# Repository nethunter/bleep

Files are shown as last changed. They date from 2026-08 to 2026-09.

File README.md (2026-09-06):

<p align="center">
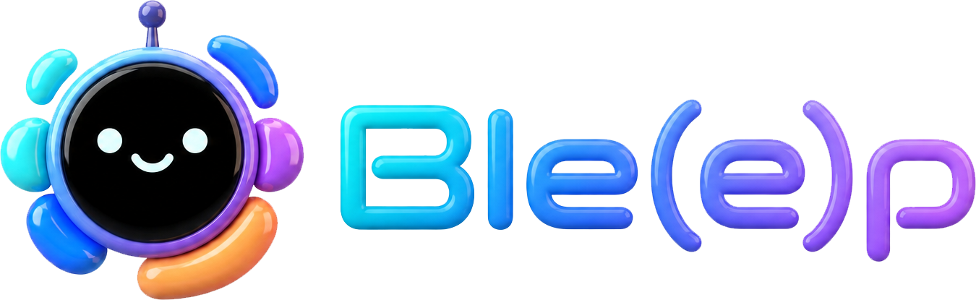
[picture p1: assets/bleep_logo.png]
Ble(e)p
  
</p>

<p align="center">
  Open, community-built control and automation for studio gear.
</p>

<p align="center">
  <a href="https://bleep.hml.tech">Website</a> ·
  <a href="docs/manual/manual.md">Owner's guide</a> ·
  <a href="docs/device-support.md">Device support</a>
</p>

# Ble(e)p

**Bluetooth Links Everything, Eventually, Probably.**

The serious expansion is **Bluetooth Low Energy Equipment Panel**: a compact
description of the hardware and its purpose when the joke needs a straight
face.

Ble(e)p is firmware for a small, touch-first hardware remote that can control
many kinds of studio equipment from one place. It started as a replacement
remote for the iFootage Shark Nano II camera slider. The longer-term goal is
bigger: become the **Home Assistant of remote controls**.

That means a shared platform where the community can add device drivers,
support new controller hardware, combine equipment from different brands, and
build repeatable workflows without waiting for every manufacturer to cooperate
with every other one.

Today Ble(e)p runs on an ESP32-C3 CrowPanel 1.28-inch round display and controls
a small but growing set of motion, camera, and audio devices. It is active
firmware development, not a finished consumer product. Some integrations are
capture-backed experiments, and several roadmap features shown in the UI are
not implemented yet.

## Product website

The [marketing website source](website/README.md) includes an interactive 3D
view of the printable enclosure with independent body/button finish swatches
and a clickable side-button push animation, a lights/camera/audio sequence
illustration, and a brightness preview. It introduces the current DIY project and links to
exact-model compatibility, the owner's guide, and build instructions. See the
website README for local preview and deployment commands. Manufacturer logos
use the site's monochrome palette, and camera compatibility distinguishes
Pixel 9's tested path from experimental iPhone, Galaxy, and other candidates.

## Where it started

Ble(e)p began on the
[Hacking Modern Life YouTube channel](https://www.youtube.com/@hml) as a hands-on
project to turn a small round ESP32 panel into a better remote for the iFootage
Shark Nano II. Once that worked, the obvious question was: why stop at one
remote? That experiment grew into the larger open-source vision described here.

## The idea

Studios accumulate one remote per light, camera, slider, recorder, and app.
Ble(e)p aims to replace that pile with an open controller built around a few
principles:

- **One interface, many brands.** Drivers expose capabilities such as record,
  move, power, or brightness through a common model.
- **Local control.** Device links, state, and sequences run on the controller;
  normal operation does not depend on a cloud service.
- **Useful offline.** The panel boots to Home without starting Bluetooth and
  connects only when a device or sequence needs it.
- **Honest state.** A Bluetooth write or protocol ACK is not presented as proof
  that hardware moved, recorded, or powered down.
- **Community-extensible.** New devices live in isolated drivers with captured
  protocol evidence, host tests, and explicit confidence labels.
- **More than one panel.** The current CrowPanel is the first target, not the
  final form factor. Display, touch, transport, and device boundaries are being
  shaped so other hardware can follow.

## What works now

- A round, touch-first Home and Devices interface with persistent device
  records, enable/disable, rename, forget/re-pair, and delete. A new or
  factory-reset panel starts with an empty Devices list; add Shark or any other
  physical device explicitly through **+ Add device**. The registry holds up
  to 24 saved devices. Connected devices sort to the front while other devices
  retain their saved order. The Devices list remains unpaged through six
  configured devices, then pages six devices at a time. Long screen, device, and sequence
  titles stay on one line and scroll horizontally instead of covering content.
  Common pages and edit overlays share the same Home-aligned title, navigation
  controls, and content start rather than maintaining separate screen geometry.
  Removing a saved device or deleting a sequence always opens a named,
  cancellable confirmation before changing stored configuration.
- A Home-screen Settings cog with radio-free saved-Wi-Fi status and direct
  on-panel setup. **Settings > Wi-Fi** scans only on request, lists visible
  networks, accepts a masked password on the round keyboard, validates
  association/DHCP, and turns Wi-Fi off afterward. Replacing Wi-Fi never
  overwrites the prior credentials unless the connection succeeds; forgetting
  Wi-Fi preserves Home Assistant setup. Retained equipment requires an explicit
  **Disconnect & scan** confirmation. The temporary Portal remains available
  for hidden SSIDs and easier phone text entry. Settings also includes haptic
  enable/disable, a first-position scrollable About/build page (including
  commit date), sanitized runtime diagnostics, and a warned Factory Reset.
- Signed Wi-Fi firmware updates with a Home-first boot. When saved Wi-Fi exists,
  the panel renders Home, waits five seconds, checks the selected channel, and
  returns updater-owned Wi-Fi to `WIFI_OFF`. Foreground work defers or cancels
  the check. Ten-minute idle checks and **Settings > Firmware update** checks
  remain. Checks never download an image; **Install now** hands the exact signed
  request to fixed recovery. The round-safe Firmware page keeps one contextual
  Check/Install action and an explicit two-second-hold Recovery action visible
  without scrolling; its countdown replaces the screen title where the holding
  finger cannot cover it. Available-release and install-confirmation prompts use
  a nearly full-face circular amber frame rather than a rectangular dialog;
  its primary and secondary actions have equal widths. Stable is default and
  development is opt-in. Recovery
  updates only the progress region while downloading, then holds on an explicit
  success screen until **Restart** is pressed. After installation is confirmed,
  main immediately restarts into a circular preparation screen with normal
  services kept dormant, then writes and validates the release's signed recovery
  image. Only the newly updated recovery is selected to install main. A failed
  preparation returns to the Firmware page with **Retry update**. This avoids reserving
  another full application slot; power loss while factory recovery itself is
  being replaced may require the NVS-preserving USB web recovery flow.
- On-demand Bluetooth LE connections through one shared NimBLE host. Central
  camera/light links and the Phone Camera HID peripheral share that runtime. Up to
  four physical BLE transport groups stay connected across navigation and
  remain immediately reusable while healthy. Ordinary devices consume one
  group each; every Aputure Light and Zhiyun member provisioned into the
  same panel-owned mesh shares one group and one proxy connection. An ownerless retained session is parked
  after an unexpected drop instead of reconnecting indefinitely. The controller
  retains up to 16 NimBLE bond records independently of the saved-device limit.
- A battery-conscious runtime policy uses compile-time configurable BLE
  transmit power (+6 dBm by default), bounded
  low-duty scan bursts, calmer ready-link intervals, Home Assistant Wi-Fi modem
  sleep, and ownerless reconnect suppression. The screen and backlight remain
  on continuously.
- On-device sequences with generated reverse/inverse Stop by default, an
  explicit Custom Stop override, waits, persistent storage, concurrent device
  preparation, and a hardware-button
  trigger. A partial Start failure can run Stop for cleanup and then retry
  Start; devices already confirmed stopped do not abort that cleanup. A saved
  camera that keeps accepting and dropping the link fails preparation within
  seconds as `Re-pair <camera>` instead of waiting out the connect budget, and
  Home Assistant's Wi-Fi may start while cameras and recorders are still
  waking when enough memory is free. There is
  no configured sequence-count ceiling; the registry grows until the panel
  cannot safely allocate or persist another sequence.
- Experimental local Home Assistant control for four selected lights, switches,
  input booleans, buttons, scenes, or scripts through a temporary setup Portal
  and one shared on-demand Wi-Fi session. An authenticated event subscription
  is command-ready even when a memory-gated initial state read is deferred; the
  entity remains visibly `UNKNOWN` until Home Assistant confirms its state.
  A successful service response completes sequence delivery even when an
  idempotent command produces no state-change event.
- A responsive LAN Portal for phone or desktop administration of committed
  devices and current Start/Stop sequences. It can rename, enable, disable, or
  remove existing devices and create, duplicate, reorder, and edit sequences;
  physical pairing and runtime control remain on the panel.
- Experimental native `Aputure Light` support with panel-owned PB-GATT
  provisioning, one cross-brand shared Mesh Proxy connection, per-member
  unicast controls, optimistic state, and the common capability-driven light
  screen. Aputure exposes per-member power and `Set look + On`; ordinary power,
  CCT/tint/brightness, and RGB use the selected fixture's unicast address.
  Automatic group polling is disabled because the previously labeled status
  payload is actually a group power-on command. `0xC000` is never written by
  ordinary device controls and is reserved for future explicit group actions.
  Initial Composition Data, AppKey, model, and group configuration advances
  only after authenticated success statuses; the reported vendor model chooses
  MC Pro versus the shared Ace/Pano command model automatically. The MT Pro is
  operator-confirmed working through this control path, but currently shares
  the MC Pro label because its captured composition identity is identical to
  MC Pro's known tuple.
- Experimental `Zhiyun Light` support for multiple MOLUS X100 and X60RGB
  fixtures. Each Add light operation detects the model, provisions a reset
  fixture when needed, persists its mesh-routing selector, and uses confirmed
  proprietary controls through the mesh's retained gateway; X60RGB also
  exposes RGB hue/saturation. Aputure, X100, X60RGB, and Home Assistant lights
  use the same control screen; the old brand-specific light controls are not
  constructed. Unsupported controls are hidden and HA is power-only.
- Separate Camera-family entries for GoPro, Insta360 GPS Remote, Insta360 Mini
  Remote, DJI Osmo, Sony Camera, and Phone Camera. GoPro uses the published
  Open GoPro BLE shutter API; Phone Camera advertises a bonded BLE HID
  volume-key shutter. The two Insta360 choices share one GATT/session runtime
  but retain separate advertising, shutter vectors, and camera-state formats.
  Mini mode uses the captured exact `Insta360 Mini Remote` identity: the X6 did
  not discover either `Ble(e)p Remote` or `Insta360 Bleep Remote` when only the
  complete-name field changed, then discovered the restored exact identity.
  Both include guarded shutdown and ORBIT wake. DJI
  implements the published Osmo controller handshake, shows the camera's
  four-digit verification code during first pairing, and supports start/stop
  plus status subscription. Toggle-only cameras expose an explicit `Shutter Toggle` scene
  action that repeats in generated Stop. Insta360 X6 Mini advertising,
  state-aware Start/Stop, and status are capture-backed; the physical Mini
  Remote's X6 power behavior is operator-confirmed. Ble(e)p's Mini path also
  completes physical X6 shutdown, correct off UI, and wake/reconnect; its
  Start/Stop and status panel checks remain open. Google Pixel 9
  reconnect and shutter behavior is
  operator-confirmed. GoPro MAX2 connection, initial recording state, explicit
  Start/Stop, and camera-confirmed Encoding state are operator-confirmed on the
  panel. Published Sleep plus reconnect-to-wake controls are implemented and
  verified on that MAX2; broader model/platform coverage and the other families remain
  experimental. Sony
  still stops at an explicit protocol-research screen.
- Specialized slider controls for keypoints A-H, joystick positioning,
  speed/hold settings, run direction, looping, and progress.
- A desktop LVGL simulator that renders the real 240x240 UI and captures PNGs
  without a connected board.
- Native tests for protocol parsing, state reducers, device/scene registries,
  command routing, persistence, and shared BLE scheduling.

Groups, existing Sidus mesh import, success-journal rollback, and full
Canon Wi-Fi/CCAPI control are roadmap work. Home Assistant and Aputure Light
are experimental bounded tranches whose hardware gates remain open. See
[project progress](docs/progress.md) for the exact current gates and
[the implementation roadmap](docs/implementation-roadmap.md) for sequencing.

## Device support

| Device | Status | What Ble(e)p can do |
| --- | --- | --- |
| iFootage Shark Nano II | Current | Pair/reconnect, battery, keypoints, manual movement, timing, loop/direction, and run control. |
| Canon EOS R6 Mark II/III via BR-E1 mode | Current | Stateless movie-record trigger through `Canon (Trigger)`. There is no recording-state readback. |
| Canon EOS R6 Mark II/III smartphone mode | Current, bounded scope | Bonded BLE pairing, explicit movie start/stop, and camera-reported recording state through `Canon (Smart)` are verified on both models; automatic wake and explicit power-down are included in the workflow. |
| GoPro MAX2 (Open GoPro BLE) | Supported | Bonded pairing, explicit Start/Stop, confirmed recording state, Sleep, physical wake, and post-boot Ready are operator-confirmed on the panel. Other models and broader coexistence coverage remain open. |
| Phone Camera — Google Pixel 9 | Experimental; verified path | Bonded reconnect and mixed-sequence BLE HID volume-up shutter are operator-confirmed. Other models and multi-phone coverage remain open. |
| Insta360 X3 | Supported | Operation through Ble(e)p's GPS Remote path is operator-approved. Model-specific capture, full reconnect/power coverage, and coexistence remain open. |
| Insta360 X4 | Supported | Operation through Ble(e)p's GPS Remote path is operator-approved. Model-specific capture, full reconnect/power coverage, and coexistence remain open. |
| Insta360 X4 Air | Supported | Operation through Ble(e)p's GPS Remote path is operator-approved. Model-specific capture, full reconnect/power coverage, and coexistence remain open. |
| Insta360 X5 | Supported | Pairing, immediate sequence Start, camera-reported recording state, Start/Stop, shutdown, and physical wake are operator-confirmed. The returning wake connection has a new address-routing fix awaiting confirmation. |
| Insta360 X6 | Experimental candidate; discovery and power verified | Exact-name Mini Remote discovery/connection, shutdown, `CAMERA OFF`, and wake/reconnect are operator-confirmed. Shutter toggle and video state are capture-backed; explicit Start/Stop and status still need a panel run. |
| Insta360 GO 3 | Experimental candidate | GPS Remote compatibility has not been tested on this model. |
| Insta360 GO Ultra | Experimental candidate | The supplied controller manual assigns Mini Remote mode; no model-specific hardware result is recorded. |
| DJI Osmo Action 5 Pro | Current, bounded scope | On-panel first-pair verification, explicit recording start/stop, and camera-originated recording status are operator-confirmed. Reconnect, forget/re-pair, and coexistence remain open. |
| DJI Osmo 360 | Current, bounded scope | On-panel first-pair verification, explicit recording start/stop, and camera-originated recording status are operator-confirmed. Reconnect, forget/re-pair, and coexistence remain open. |
| Sony Camera | Research | Separate catalog entry with recoverable capture-required onboarding; no device record is committed until the peripheral-role protocol is verified. |
| Tascam Portacapture X8 + AK-BT1 | Current, bounded scope | Record start/stop and recorder-confirmed state, including state restoration after reconnect. |
| Home Assistant local entities | Experimental; mixed sequence verified | Four selected `light`, `switch`, `input_boolean`, `button`, `scene`, or `script` entities over local HTTP/WebSocket. Four-link BLE coexistence plus accepted Start/Stop delivery is hardware-verified; full domain/lifecycle coverage remains open. |
| Aputure Light — amaran Ray 60c / Ace 25c; Aputure MC Pro / MT Pro | Supported exact models | Automatically selects one stable candidate, or shows a bounded picker when multiple factory-reset Aputure/amaran fixtures are nearby, before provisioning onto the panel-owned mesh. Per-node power/look routing follows the working Studio Lighter unicast path. MT Pro is currently mislabeled as MC Pro because both report the known `0x03F6:0x1000` vendor tuple and the same composition header IDs. Pano 60c/120c, broader physical selection, multi-fixture isolation, recovery, and soak gates remain open. |
| Zhiyun Light (MOLUS X100 / X60RGB) | Experimental | Uses the same conditional onboarding picker, then adds the selected fixture as a logical member of the one-slot mesh. Ble(e)p persists a per-member proprietary routing selector and multiplexes `0xFEE9` control with the standard Mesh Proxy bearer on one retained gateway. X100 supports power and CCT/brightness; X60RGB adds RGB hue/saturation. |
| Deity PR4 | Later | Transport and protocol research have not started. |

Compatibility claims are deliberately narrow. Read
[device support](docs/device-support.md) for tested models, pairing modes,
limitations, and remaining hardware checks.

## Hardware

The current target is the **ESP32-C3 CrowPanel 1.28-inch round display**:

- 240x240 GC9A01 LCD;
- CST816D touch controller;
- PI4IOE5V6408 I/O expander;
- onboard vibration motor;
- optional external button on GPIO 1, active low.

The board does not include battery-voltage sensing, so the firmware cannot show
the controller's own battery level without a hardware modification. Battery
values shown on the Shark screen come from the slider.

### Controls

- **Touch:** Home, device management, sequences, connection, keypoints,
  positioning, run controls, per-keypoint settings, and explicit Canon/GoPro
  camera power controls. Reopening or preparing a Canon Smart or sleeping
  GoPro that Ble(e)p powered off reconnects and attempts its device-specific
  wake path for up to 30 seconds, then returns to a retryable asleep state. An
  accepted touch click produces a crisp haptic tap; a device becoming ready or
  opening an already-connected device uses two quick ticks; Back uses two
  uneven taps; and a newly surfaced error uses two strong pulses. Scrolling
  and canceled touches do not produce feedback.
- **Button (GPIO 1):** A short press activates the current primary action. On a
  sequence run screen it starts from Ready and stops once armed or while Start
  is running. Device screens similarly dispatch their primary Shark, Canon,
  GoPro, Phone Camera, or Tascam action. A 700 ms hold navigates Back, cancels,
  or closes the current
  overlay. Continuing the same hold to 2 seconds safely unwinds the remaining
  navigation path and returns directly to Home. Recognized short presses use
  the normal tap, while each handled hold stage uses the Back pattern. The
  button has no power behavior; the hardware SPDT switch controls controller
  power.

### Pin assumptions

| Function | GPIO / address |
| --- | --- |
| LCD DC / CS / SCK / MOSI | GPIO 2 / 10 / 6 / 7 |
| I2C SDA / SCL | GPIO 4 / 5 |
| Touch interrupt | GPIO 0 |
| External button | GPIO 1, active low |
| Vibration motor | I/O expander P0 |
| I/O expander | I2C `0x43` |
| CST816D touch | I2C `0x15` |
| BM8563 RTC | I2C `0x51` |

## Build, test, and flash

You need a compatible Python 3 installation and PlatformIO. From the repository
root:

The clean-storage boundary introduced during `0.2.0-dev` remains in 0.3.0: the
firmware does not migrate former Amaran driver IDs, the `amaran_mesh` NVS key,
or pre-current device/scene/mesh schemas. Before flashing over an older
development build, use **Settings > Factory Reset** on the currently installed
firmware. Recovery first verifies latest stable, then clears saved configuration
and installs that stable main image.

```sh
python3 -m venv .venv
./.venv/bin/python -m pip install -r requirements.txt

PLATFORMIO_CORE_DIR="$PWD/.platformio-core" ./.venv/bin/python -m platformio test -e native
PLATFORMIO_CORE_DIR="$PWD/.platformio-core" ./.venv/bin/python -m platformio run -e bleep
PLATFORMIO_CORE_DIR="$PWD/.platformio-core" ./.venv/bin/python -m platformio run -e bleep -t upload
```

The main Montserrat profile compiles every current driver and is the standard
local firmware check. GitHub Actions is the cross-profile testing ground: every
pull request and push to `main` builds the full Montserrat and Roboto profiles,
plus the isolated Shark, Canon Smart, Canon Trigger, Tascam X8, Home Assistant,
  Aputure Light, Zhiyun Light, GoPro, Phone Camera, Insta360, and DJI Osmo
profiles.
Build an isolated profile locally only when diagnosing a profile-specific
failure.

After native tests and all firmware profiles pass on a push to `main`, GitHub
Actions updates the **Latest development firmware** prerelease with a canonical
manifest, ECDSA P-256 signature, full Montserrat and recovery images, independent verification,
and an NVS-preserving USB migration bundle. Its displayed and manifest version
is the configured project version with `-dev` appended. Publishing a normal GitHub Release
performs the stable-channel build and signing job; it does not require a tag
naming convention. Development snapshots have not necessarily passed the
physical hardware release gates.

To render the UI on a desktop, install ImageMagick and run:

```sh
PLATFORMIO_CORE_DIR="$PWD/.platformio-core" ./.venv/bin/python -m platformio run -e ui_sim
.pio/build/ui_sim/program
```

Generated screenshots are written to `sim/screenshots/` and are intentionally
ignored by Git. Partition schema 2 keeps NVS at `0x9000/0x5000`, OTA metadata
at `0xE000/0x2000`, fixed recovery at `0x10000/0x100000`, its journal at
`0x110000/0x10000`, main firmware at `0x120000/0x2D0000`, and coredump in the
final 64 KiB. CI enforces raw ceilings of `0xF0000` for recovery and `0x2C0000`
for main.

Existing single-slot installations require the release's one-time USB
migration bundle before Wi-Fi updates can work. The migration writes the
bootloader, partition table, blank OTA metadata, fixed recovery, blank recovery
journal, and main application; it does not erase or overlap NVS. On the first
boot, recovery validates and automatically selects main without requiring a
**Boot firmware** tap. See
[hardware migration](hardware/README.md#one-time-recovery-firmware-migration).

## Using the current build

The panel always boots to Home. Open **Devices** and choose a device from its
category to go straight into pairing. The device appears in the saved Devices
list only after pairing reaches protocol-ready state; Back or a failed attempt
does not leave an unpaired record behind. Pairing mode matters:

- Shark: make the slider discoverable; Ble(e)p matches service `0xFFF0` or a
  `Nano`/`Shark` advertised name.
- Canon Trigger: use the camera's Bluetooth remote / BR-E1 menu.
- Canon Smart: use **Connect to smartphone → Add a device to connect to**. A
  saved phone registration and a BR-E1 bond are different pairings.
- Tascam X8: install the AK-BT1 and make the recorder available to its remote
  app connection.
- Zhiyun Light: choose **Add light -> Zhiyun**, then add one nearby X100 or
  X60RGB. Factory-reset and previously provisioned fixtures are accepted.
  Ble(e)p matches the product-qualified `PL105_` or `X104_`/`plx104` identity,
  provisions `0x1827` when needed, then rediscovers `0x1828` and opens the
  control service. Repeat Add light for every fixture. A previously provisioned
  fixture can work over a temporary direct link but will not share the panel's
  mesh range. To move it onto the panel-owned mesh without breaking scene
  references, use **Forget** rather than Remove, Bluetooth-reset the fixture,
  reopen its saved entry, and select the factory-reset candidate.

When adding another Canon camera in either mode, Ble(e)p ignores Canon bodies
that are already saved or bonded to it, including cameras advertising from
Bluetooth standby. After pairing, known `EOSR6m2_...` and `EOSR6m3_...`
identities are shown as **Canon EOS R6 Mark II** and **Canon EOS R6 Mark III**.
**Retry** stays locked to the saved body; use **Forget** before deliberately
pairing that entry to a different camera.
For any saved unpaired device, reopening its entry makes the discovered
candidate rows selectable while preserving the existing device and scene
references.

Open **Portal** from Home and join the open temporary `Bleep-Setup-XXXXX`
network by scanning the on-panel QR code or selecting the SSID whose
five-character suffix matches that panel. Browse to the setup address shown on
the panel; phones may open it automatically as a captive sign-on page. The
setup Portal provides **Overview**, **Devices**, **Sequences**, and **Wi-Fi**
without requiring studio Wi-Fi. Devices can be renamed, enabled/disabled, or
removed; removal is blocked while a sequence references the device. Add
physical devices on the panel so their pairing flow stays local.

Home Assistant is the only Portal function that requires studio Wi-Fi. An
initial nearby-network scan completes before the setup AP opens, and **Show
nearby Wi-Fi** performs a fresh non-blocking scan if networks have changed or
the initial scan found none. Choose a result or enter a hidden SSID manually.
After Ble(e)p joins, note the numeric LAN address, let the setup AP close, and rejoin
the normal local Wi-Fi. Open that address while Portal remains active;
`http://bleep.local` is a best-effort convenience. The Home Assistant URL starts
as `http://homeassistant.local:8123`. A saved token is reported only as stored
and is never returned to the browser; choose **Change stored token** to replace
it. Select at most four supported entities.

Sequences can be created, renamed, enabled/disabled, duplicated, and deleted.
On the panel, **Duplicate** in Sequence Settings immediately opens a complete
copy named `Old Name (2)`; the Portal suggests the same copy name and lets you
change it before saving.

**Add Sequence** guides creation through Start actions, generated Stop review,
and Name. Editing Start regenerates the read-only reverse/inverse Stop
preview. **Customize Stop** copies that preview into an independent editable
list; **Use generated Stop** discards the override after confirmation. Custom
lists support action and wait steps, in-place editing, and reordering. On the
panel, orphaned custom
rows remain deletable if their target device
was removed, so an invalid sequence can be repaired one step at a time. The
Portal changes configuration only: it does not connect to
devices or run sequences. Choose **Finish & Exit** in the Portal, or Exit on the
panel, after saving; this stops the server and turns Wi-Fi off. Later Portal
sessions join saved Wi-Fi directly and show their current numeric LAN address;
normal Home boot remains network-free.
In LAN mode, the on-panel QR code changes from the temporary open-network join
to the current numeric Portal URL.

Lights and switches expose explicit On/Off controls. Home Assistant
`input_boolean` entities use one context-sensitive action button: it shows ON
while the helper is off and OFF while it is on. Buttons use Press and HA
scenes/scripts use Activate.

This v1 path uses an open setup AP and sends Portal and HA credentials over
local plaintext HTTP. Open Portal only in a controlled location and use the
LAN handoff only on a trusted studio network; TLS,
Home Assistant Cloud, OAuth, and exposing Ble(e)p-controlled hardware back to
Home Assistant are not implemented.

Open **Scenes** to create ordered Start sequences with generated or Custom Stop.
New sequences open Start first: add steps, select the header arrow to review
Stop, optionally customize it, then use the checkmark and standard Rename keypad
to name and finish the sequence.
A scene reaches `Ready`
only when every target has both a physical link and completed protocol setup.
In Start or Custom Stop, tap an existing step to change its action or settings;
waits open a millisecond duration editor and **Set look + On** steps reopen with
their saved CCT/RGB parameters. New waits default to 200 ms. New looks default
to 5600 K, 50% brightness,
and neutral tint. While that editor is open, settled slider or color-wheel
changes preview the look on the selected light after a short debounce. Preview
uses **Set look + On**, so the fixture turns on to make the result visible.
Step rows place their reorder/delete controls below
the action name, and the scrollable list ends with **Add step**. Back from an
existing step's settings returns directly to that Start/Stop list. The Devices
list similarly places **Add device** after the configured devices.
The panel owns those links while the run screen is open. Circular target chips
show connection readiness and open each device's full controls without dropping
the other sequence links. Opening Settings cancels pending preparation and
releases sequence ownership so Rename and the Start/Stop editors are immediately
usable; it does not interrupt an active Start, armed recording, Stop, or a
partial action failure that still permits Stop cleanup. Back or Done also
releases sequence ownership while ready device sessions remain available for
immediate reuse. Mixed BLE/Home Assistant scenes give cold physical targets and
deferred HA connection separate bounded preparation windows. Switching to a
scene that uses the same HA entity transfers its ownership without an idle gap,
keeping the retained Wi-Fi/WebSocket session protected even while new physical
targets prepare. Old-only targets lose sequence ownership but remain retained
while the four-resource pool has capacity; normal LRU eviction reclaims one
only when a new acquisition actually needs room. A shared physical transport
group is likewise protected when any member remains in the next scene. Device
management offers an explicit Disconnect action.

## How the firmware is organized

| Path | Responsibility |
| --- | --- |
| `src/core/` | Driver metadata, persistent registries, typed commands/results, scene execution, `DeviceManager`, and the shared BLE central. |
| `src/devices/<device>/` | One device integration: protocol, state reducer, transport client, driver adapter, and optional specialized UI. |
| `src/ui.cpp`, `src/scene_ui.cpp`, `src/ui/` | Home, Devices, Scenes, shared pickers/record controls, and navigation. |
| `src/main.cpp` | Display, touch, I/O, power-button handling, and the Arduino main loop. |
| `test/` | PlatformIO native tests for host-testable logic. |
| `sim/` | Desktop LVGL harness and fake runtime. |
| `docs/` | Architecture, decisions, roadmap, device support, protocol research, and current handoff. |

All parsing, state mutation, GATT writes, scene transitions, and LVGL access
happen from Arduino `loop()`. NimBLE callbacks only enqueue bounded raw events
or notification bytes. This ownership rule is central to keeping the UI and
device state deterministic.

Drivers are selected at compile time through the current PlatformIO build
flags. Runtime device records are separate from compiled driver metadata, so a
record can remain dormant when a smaller firmware build omits its driver. A
future Arduino-as-component build is expected to expose these options through
Kconfig without changing driver code.

BLE transmit power is selected at compile time with
`CONFIG_BLE_TX_POWER_DBM`. Its shared configuration default is `+6` dBm;
define the symbol as an integer from `-24` through `20` in a profile's build
flags when a different range/current trade-off is required. NimBLE maps the
request to a radio level supported by the ESP32-C3.

For the complete model, read [architecture](docs/architecture.md),
[architecture decisions](docs/decisions.md), and [scenes](docs/scenes.md).

## Adding support for a device

A useful driver contribution usually includes:

1. a stable driver/model ID and a clear pairing or discovery rule;
2. protocol types and golden vectors that can be tested without hardware;
3. a pure state reducer where the protocol exposes state;
4. a non-blocking client that obeys main-loop ownership;
5. capability and command descriptors used by the common UI and scenes;
6. hardware results that distinguish a link/ACK from observed physical action;
7. documentation with `Research`, `Hypothesis`, and `Blocked` labels where
   evidence is incomplete.

Start with [CONTRIBUTING.md](CONTRIBUTING.md) and the
[device-driver checklist](docs/device-support.md#adding-a-future-driver). For
Android vendor-app research, follow the
[screen-recording and HCI capture workflow](docs/protocols/capture-workflow.md).
Raw wireless captures often contain identifiers from unrelated nearby devices;
do not open a pull request with an unreviewed capture.

## Roadmap

The broad direction is:

- finish the shared multi-device foundation and physical regression gates;
- add capability-safe groups and reusable generic controls;
- prove Bluetooth Mesh, Wi-Fi/HTTP coexistence, and temporary Portal mode;
- add lighting and full camera integrations;
- harden scenes, recovery, configuration import/export, and release profiles;
- separate board support cleanly enough for community-maintained controller
  hardware.

The versioned [roadmap](docs/implementation-roadmap.md) and
[decision log](docs/decisions.md) are the source of truth. They intentionally
move more slowly than feature ideas: hardware verification gates are
requirements, not suggestions.

## Contributing

Device knowledge, protocol research, host tests, UI work, documentation, and
new hardware targets are all welcome. Please read [CONTRIBUTING.md](CONTRIBUTING.md)
before opening a pull request. Use [SECURITY.md](SECURITY.md) for vulnerability
reports, especially anything involving stored pairing material or future
network credentials.

## Safety and trademarks

This firmware can move physical equipment and start or stop real recordings.
Keep people, cables, and equipment clear of motorized hardware. Test protocol
changes at low speed and confirm physical behavior; an ACK alone is not proof
of success.

Ble(e)p is an independent community project and is not affiliated with or
endorsed by iFootage, Canon, GoPro, Insta360, DJI, Sony, Tascam, Amaran, Deity,
Espressif, or Elecrow. Brand
and product names belong to their respective owners.

## License

Ble(e)p is licensed under the [Apache License 2.0](LICENSE), the same license
used by Home Assistant Core. It permits use, modification, and distribution
while preserving attribution and providing an explicit patent grant.

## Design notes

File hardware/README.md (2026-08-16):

# Ble(e)p Hardware

This directory contains the printable enclosure and editable mechanical model
for the Ble(e)p handheld controller. The enclosure is designed around the
Elecrow CrowPanel ESP32 1.28-inch round display and an SS12D00G slide switch.

## Parts

| Part | Specification | Link |
| --- | --- | --- |
| Display and controller | Elecrow CrowPanel ESP32 1.28-inch round display, model DIS12824D; ESP32-C3, 240x240 IPS display, capacitive touch | [Elecrow product page](https://www.elecrow.com/crowpanel-esp32-display-1-28-r-inch-240-240-round-ips-display-capacitive-touch-spi-screen.html) |
| Slide switch | SS12D00G SPDT slide switch with a 5 mm actuator | [Amazon](https://amzn.to/3RRJRAK) |
| Battery | JLJLUP 3.7 V 1100 mAh 1S LiPo with protection board; 25 x 10 x 42 mm, 19 g, 1C discharge rate, JST 1.25 plug; four-pack listing, ASIN B0GR14VMW5 | [Amazon](https://www.amazon.com/dp/B0GR14VMW5) |
| Battery connector | JST SH 1.0 mm 2-pin connector with pigtails; replaces the battery's incompatible plug | [Amazon](https://amzn.to/4hNGGEG) |
| Replacement battery-path diode | 1N5819 Schottky diode, DO-41, nominal 1 A / 40 V; replaces the original CrowPanel D1 | [Amazon](https://amzn.to/45O7ehS) |
| Heat-set inserts | 3x M3 x 6 x 5 mm brass heat-set inserts | [Amazon](https://amzn.to/4yYaTH8) |
| Machine screws | 3x M3 x 8 mm socket-head machine screws | [Amazon](https://amzn.to/3S8nI18) |

The shortened `amzn.to` links in this parts list are affiliate links. Purchases
made through them may earn a commission at no additional cost to you and help
support the
[Hacking Modern Life YouTube channel](https://www.youtube.com/@hml).

## Enclosure files

| File | Purpose |
| --- | --- |
| [Bleep Remote Top.3mf](<Bleep Remote Top.3mf>) / [STL](<Bleep Remote Top.stl>) | Printable top shell |
| [Bleep Remote Bottom.3mf](<Bleep Remote Bottom.3mf>) / [STL](<Bleep Remote Bottom.stl>) | Printable bottom shell |
| [Bleep Remote Button.3mf](<Bleep Remote Button.3mf>) / [STL](<Bleep Remote Button.stl>) | Printable actuator for the CrowPanel's custom button |
| [Bleep Remote.step](<Bleep Remote.step>) | Editable assembly model containing the enclosure, CrowPanel, button, and slide switch |

Use the 3MF files when your slicer supports them. The STL files are provided
for broader compatibility, and the STEP file is the best starting point for
changing the enclosure or adapting it to another component.

## Printing

The original print used a Bambu Lab X1 Carbon with a 0.4 mm nozzle, a SuperTack
plate, and the stock `0.12mm High Quality @BBL X1C` process preset. The top and
bottom shells used Bambu PLA Matte in Ivory White; the button used Bambu PLA
Matte in Black. Each part was placed on its own plate.

Change only these process settings from the preset defaults:

- enable supports;
- select **Normal (Auto)** supports instead of the default **Tree (Auto)**.

All other process and filament settings remain at the defaults supplied by the
selected Bambu presets. Print the button first as a quick fit test before
committing to both shells.

Experimental mechanical models belong in the gitignored
`hardware/.workbench/` directory. Promote a model into this tracked parts list
only after its fit, printability, and assembly behavior feel final.

## Assembly notes

Dry-fit every component before soldering. The CrowPanel fits directly into the
top shell; no adhesive is used. The CrowPanel's custom button is GPIO 1 and
active low; the printed button transfers the case press to that control. In the
current firmware, a short press triggers the current screen's primary action,
including Start/Stop on a sequence run screen. A 700 ms hold navigates Back,
cancels, or closes the current overlay; releasing after a handled hold does not
also trigger the short-press action. The button has no power behavior—the
hardware SPDT switch is the remote's sole power control.

Install the three heat-set inserts into the modeled bosses with a temperature-
controlled soldering iron and a suitable insertion tip. Keep each insert
square to the boss and stop when it is flush; excessive heat or pressure can
deform the shell. Let the plastic cool completely before joining the enclosure
with the three M3 x 8 mm screws. Tighten the screws only until the shells are
secure.

The battery's original plug is not compatible with the CrowPanel battery
socket. Replace it with the linked JST SH 1.0 mm 2-pin pigtail and put the
slide switch in series with one battery lead:

```text
Battery lead A ── switch COM ── selected throw ── connector lead A
Battery lead B ────────────────────────────────── connector lead B
```

Only the switch's common terminal and one throw are used; insulate the unused
throw. Identify the terminals with a multimeter rather than relying on the
switch's physical orientation. Verify continuity in both switch positions, and
verify the finished connector's voltage and polarity against the CrowPanel
markings and documentation before plugging it into the board.

Battery leads remain live while replacing the connector. Cut and splice only
one conductor at a time, insulate each joint before exposing the other lead,
and cover the finished solder joints with heat-shrink tubing. Do not apply the
soldering iron directly to the battery cell or tabs.

After verifying the switched lead, remove the original CrowPanel D1 and install
the external 1N5819 replacement using the procedure below. Route and
strain-relieve the battery, switch, and diode wiring before fitting the board
and closing the enclosure.

Do not charge, use, or enclose a damaged or swollen lithium battery. Prevent
bare switch terminals and battery leads from contacting the PCB or each other.

## Prototype packaging

The five-unit telescoping-box dielines, folded bridge insert, quick-start card,
fit test, and two-up accordion pocket guide live in
[`hardware/packaging/`](packaging/README.md). Print every structural dieline and
the pocket guide at Actual Size and verify its 50 mm calibration bar before
cutting. The pocket guide is a 69 x 130 mm insert for the concealed cable bay;
it is not a substitute for the current full owner's guide.

## Replace the CrowPanel D1 battery path

The [DIS12824D V1.0 schematic](https://www.elecrow.com/download/product/CrowPanel/ESP32-HMI/1.28-DIS12824D/CrowPanel_ESP32_1.28-inch_V1.0_240507.zip)
identifies the CrowPanel's original D1 as a `B5819WT` Schottky diode in a small
SOD-523 package, in series between `VBAT` and the board load. The reference
assembly removes the original D1 and replaces it with the physically larger,
through-hole 1N5819 listed above.

Do not leave both diodes electrically connected in parallel. Do not replace D1
with a wire.
Confirm the diode's markings and supplier datasheet; its real current
and thermal limits depend on the specific manufacturer and installation.

Disconnect both USB and the battery before soldering. Identify the two D1 nets
with a multimeter rather than relying on connector wire colors, especially
after replacing or rewiring the JST SH pigtail:

```text
battery-positive / VBAT side ── unbanded end [ 1N5819 ] banded end ── board-load side
                                 anode                       cathode
```

Installation procedure:

1. With power disconnected, check that the board-load side is not shorted to
   ground. A steady resistance near zero indicates a fault; resolve it before
   fitting the external diode.
2. Confirm which end of the original D1 is connected to actual battery
   positive. Mark that as the `VBAT` side and mark the opposite end as the
   board-load side.
3. Carefully desolder and remove the original D1. Heat each joint only as long
   as needed, lift the component without prying, then clean and inspect both
   pads. Stop if either pad or trace lifts.
4. Connect the 1N5819's **unbanded anode** to the `VBAT` side. The battery
   connector's verified positive solder joint is a stronger alternative to
   loading the tiny former D1 pad mechanically.
5. Connect the 1N5819's **banded cathode** to the board-load side. Use short,
   flexible insulated wire so the large DO-41 body cannot pull the former D1
   pad from the PCB.
6. Confirm that the removed D1 is no longer electrically connected. Insulate
   every exposed conductor with heat-shrink or Kapton tape. Secure the diode
   body with strain relief and keep the assembly clear of the antenna, USB
   connector, enclosure hardware, and other exposed pads.
7. Inspect for solder bridges, then perform the first test from battery only.
   Disconnect immediately if the diode heats rapidly, the board-side voltage
   stays near zero, or the panel behaves abnormally.

A build using this arrangement measured 4.0 V on the battery side and 3.7 V on
the board side while the panel ran from battery. Before closing the enclosure,
exercise representative BLE scanning and connection load while monitoring
diode temperature and voltage drop. Disconnect immediately if the diode heats
rapidly or the voltage becomes unstable. Retain the longer ADR-025
battery-endurance gate.

## Firmware and pin details

### One-time recovery firmware migration

Firmware installed with the earlier single-application partition table cannot
perform a safe Wi-Fi update. Download `bleep-usb-migration.zip` from a trusted
release, verify its release provenance, extract it, connect the panel by USB,
and run:

```sh
cd bleep-usb-migration
./migrate.sh /dev/cu.usbserial-211240
```

Use the actual enumerated port; never guess a different device. The script uses
esptool `write_flash` without `erase_flash`. It writes the bootloader at
`0x0000`, partition table at `0x8000`, blank OTA metadata at `0xE000`, fixed
recovery at `0x10000`, a blank recovery journal at `0x110000`, and main firmware
at `0x120000`. It does not write or erase NVS at `0x9000/0x5000`, so saved panel
configuration is intended to survive. Keep USB power connected through the
first boot. Recovery should automatically validate and select main; no
**Boot firmware** tap is required for a clean migration. Confirm saved
configuration before relying on Wi-Fi updates.

The NVS-preserving bundle has been hash-verified and exercised on five distinct
panels. All five booted main firmware after migration without a manual recovery
selection, and settings remained intact where previously configured. Continue
to back up important configuration, confirm it after migration, and never use a
full-chip erase for this procedure.

Build, flashing, firmware behavior, and the complete CrowPanel pin assumptions
are documented in the [project README](../README.md#hardware).

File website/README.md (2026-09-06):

# Ble(e)p website

The static marketing site for [bleep.hml.tech](https://bleep.hml.tech), hosted
with Firebase Hosting in the `hml-studio` Google Cloud project.

## Preview locally

No install or bundler is required. Serve the directory over HTTP so the 3D
model can load its local modules and geometry:

```sh
python3 -m http.server 8765 --directory website --bind 127.0.0.1
```

For a preview with Firebase routing and headers:

```sh
cd website
firebase serve --only hosting --project hml-studio
```

## Design and interactions

The site presents Ble(e)p as an open-source DIY studio gadget. Warm ivory,
signal orange, olive, and oversized Archivo Black headlines frame a real CAD
model and an interactive studio illustration. There is no checkout or implied
finished-product availability.

- `index.html`: product story, lights/camera/audio sequence illustration,
  brightness preview, model-specific compatibility links, build CTA, and FAQ.
- `styles.css`: shared responsive marketing and compatibility design.
- `script.js`: navigation, finite user-started sequence playback, brightness
  preview, and optional model loading. Reduced motion shows the final sequence
  state immediately; each step remains individually selectable.
- `screen-tour.js`: five automatically cycling firmware-screen chapters
  (Sequences, Lighting, Cameras, Audio, Motion), illustrative tap pulses, and
  state crossfades on a 240×240 canvas texture. Pause and Next are keyboard
  accessible. Reduced motion disables autoplay; Next still selects functions.
  Hidden/offscreen/context-lost views stop the clock, and unchanged frames
  sleep between transitions. Failed tour loading retains the static screen.
- `product-model.js`: Three.js rendering from the actual top/bottom/button STL
  exports and display cover, USB-C socket, and power-switch parts extracted
  from the STEP assembly. Drag, arrow buttons, and keyboard arrows rotate the device; Home or
  Reset restores it. Body finishes (Ivory, Graphite, Sand, Stone, Orange) and
  button colors (Orange, Blue, Black) change independently through labeled
  swatches. Stone uses procedural object-space speckles, preserving alignment
  across the two shell parts. Clicking the model's side button depresses it
  and releases in one short animation; Enter/Space on the canvas provides the
  same push. Dragging rotates the enclosure. No separate Press control is rendered,
  and the push does not change the screen tour. Render work stops offscreen
  and when the tab is hidden.
- `assets/device-poster.svg`: lightweight illustrated fallback for unavailable
  WebGL, failed model assets, disabled JavaScript, or Save-Data.
- `compatibility.html`: existing dated evidence ledger, restyled without
  promoting model support. Detailed repository notes remain authoritative.

The sequence and brightness interactions are marketing illustrations, not
remote hardware controls or firmware UI emulators. Camera and audio start in
order, not with frame synchronization. The model uses the real enclosure
geometry, firmware screenshots, illustrative fasteners, and selectable finish
materials; it is not a promise of a manufactured finish.

## Assets and maintenance

Three.js **0.180.0** is pinned and vendored under `assets/vendor/`; its MIT
license is included. No CDN scripts or runtime package installation are needed.
Archivo Black, Manrope, and DM Mono are self-hosted as Latin WOFF2 subsets
under `assets/fonts/`, with their SIL Open Font Licenses. The site makes no
third-party runtime requests.

The top, bottom, and button STL files under `assets/models/` are byte-for-byte copies of the
matching `hardware/Bleep Remote {Top,Bottom,Button}.stl` files. When the enclosure
changes, refresh these copies together and inspect the assembled model. The
original assembly coordinates must be preserved. The LCD-MIANBAN display cover,
USB-C socket, and SS12D00 power switch are exported from the STEP assembly with
`tools/export_website_components.py` (Python 3.12, `cadquery-ocp==7.8.1.1`,
`vtk==9.3.1`). The display cover fills the 42.1 mm case opening; its rounded
shoulder rises from z=0 to the flat touch face at z=1.9 mm. The animated
32.8 mm display and its annular border replace the cover's solid front cap
at z=1.9 mm, eliminating overlapping triangles beneath the screen. Camera
clipping planes follow the device bounds to preserve mobile depth precision.
The model adds a dark socket mouth and insulating tongue to the
single-material connector CAD part to match the physical reference. Raw user
photos are not included in the repository. `ui-sequence.png` is an
existing firmware UI screenshot used as the static fallback. `assets/screens/`
contains fresh, unchanged captures from the full `ui_sim` traversal in this
checkout. These show simulator states, not physical-device recordings:

| Website frame | Simulator capture |
| --- | --- |
| `sequence-ready.png` | `24_scenes_run_ready.png` |
| `sequence-running.png` | `26_scenes_armed.png` |
| `light-cct.png` | `20e_aputure_light_cct_optimistic.png` |
| `light-rgb.png` | `20f_aputure_light_rgb.png` |
| `camera-ready.png` | `12_canon_ready.png` |
| `camera-recording.png` | `13_canon_recording.png` |
| `audio-ready.png` | `19_tascam_ready.png` |
| `audio-recording.png` | `20_tascam_recording.png` |
| `motion-keypoints.png` | `06_shark_keys.png` |
| `motion-run.png` | `07_shark_run.png` |

Rebuild `ui_sim`, run `.pio/build/ui_sim/program`, and refresh the paired
captures together when the firmware UI changes. Tap pulses are illustrative;
lighting/motion screens show separate controls and do not imply synchronized
motion inside a sequence. Existing photography and the owner's-guide
PDF remain available; a website redesign does not regenerate the manual.

Keep asset URLs versioned when changing JS/CSS: Firebase serves them with a
one-week immutable cache. Increment the HTML script/style URLs and the dynamic
model import together. When updating model dependencies or geometry, version
their import/fetch URLs as well.

## Verification

Inspect desktop and mobile layouts, the compatibility table, navigation,
keyboard rotation/reset, drag rotation, play/pause/replay, step selection,
brightness keyboard input, FAQ, reduced motion, missing-model fallback, and
JavaScript-disabled content. Check against Firebase's configured CSP as well
as the plain static server. The existing repository policy also requires the
full Montserrat `bleep` compile after code changes; no flashing from worktrees
without explicit approval.

## Deploy

```sh
cd website
firebase deploy --only hosting --project hml-studio
```

A local preview or successful build is not a production deployment.

### Equipment logos and phone-family presentation (2026-09-06)

`assets/brands/` contains locally hosted manufacturer artwork, displayed as
CSS alpha masks in the site's ink color. Original letterforms and proportions
are preserved. SVG view boxes are tightened to the artwork; Canon's separate
“Global” header label is omitted. The iFootage PNG is unchanged. Logo use
identifies equipment; it does not imply manufacturer endorsement.

| File | Official source | Preparation |
| --- | --- | --- |
| `canon.svg` | <https://global.canon/01cmn/img/common/logo-sp.svg> | Extracted the five Canon wordmark paths; omitted separate Global text. |
| `amaran.svg` | <https://amarancreators.com/> | Extracted the inline `amaran Logo` SVG from the header. |
| `insta360.svg` | <https://res.insta360.com/static/1a22851807665e5431fd7f77b62a9102/Insta360_Primary%20logo%20-%20Black%26transparent%20-%20Online.pdf> | Converted official vector PDF using Poppler `pdftocairo -svg`; cropped view box to paths. |
| `tascam.svg` | <https://tascam.com/wp-content/themes/tascam/assets/img/logo.svg> | Added/tightened the view box. |
| `ifootage.png` | <https://www.ifootagegear.com/cdn/shop/files/cropped-ifootage-logo_2017_300x_c243c7f7-d24a-4d2c-9e1e-efef87ae692d.png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> | Original transparent PNG. |
| `gopro.svg` | <https://gopro.com/en/us/> | Extracted the inline header-logo SVG. |

Phones appear within the homepage Cameras category and alongside the camera
rows in the compatibility matrix. iPhone, Samsung Galaxy, OnePlus, and
Xiaomi/Redmi are named examples of the **existing
experimental iOS/Android candidates** in `docs/device-support.md`, not newly
supported devices or expanded verification. Pixel 9 retains its observed
reconnect/shutter evidence; other Pixel models remain unverified. Manufacturer
camera-setting links support only the volume-key convention, not Ble(e)p BLE
pairing, reconnect, video behavior, or exact-model compatibility. Support
classifications, firmware, and manual content are unchanged.

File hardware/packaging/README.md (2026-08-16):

# Ble(e)p prototype packaging

This directory contains the editable generator for a five-unit packaging
prototype. The design holds:

- one assembled Ble(e)p controller, nominally 118 x 48 x 21 mm;
- one folded USB-C cable beneath the controller;
- one 140 x 75 mm quick-start card above the controller.

The package is a two-piece telescoping paperboard box with a folded bridge
insert. Its nominal internal size is 155 x 90 x 45 mm. The lid has 2.5 mm of
clearance per side before accounting for material thickness. The visual design
uses warm-white faces, a centered Ble(e)p identity, a restrained `Studio
Controller` label, and cropped cyan, blue, purple, pink, and orange accents at
the lid edges. The structure remains telescoping; it is not a hinged or magnetic
book box.

## Generate the prototype

From the repository root:

```sh
/Users/nethunter/.cache/codex-runtimes/codex-primary-runtime/dependencies/python/bin/python3 \
  hardware/packaging/generate_prototype.py
```

This writes `hardware/packaging/bleep-packaging-prototype.pdf`. The PDF contains:

1. the package concept and dimensions;
2. a full-scale lid dieline;
3. a full-scale base dieline;
4. a full-scale bridge-insert template;
5. quick-start cards;
6. a fit and handling test protocol.

Generate the two-up pocket guide separately:

```sh
/Users/nethunter/.cache/codex-runtimes/codex-primary-runtime/dependencies/python/bin/python3 \
  hardware/packaging/generate_pocket_guide.py
```

This writes `hardware/packaging/bleep-pocket-guide-2up.pdf`, a two-page Tabloid PDF.
Each sheet produces two identical 69 x 130 mm, 12-panel accordion guides. Print
three sheets to make five guides plus one fit/registration spare.

Print the pocket guide double-sided in color on 11 x 17 inch, 32 lb matte text
paper. Use **Actual Size / 100%**, landscape orientation, and **flip on short
edge**. Disable automatic scaling and verify the 50 mm calibration bar before
cutting. The front reads panels 1-6 from left to right. Unfold the strip, turn
it over, and continue panels 7-12 from right to left.

Cut the magenta outer borders, then score at each pair of cyan fold ticks. With
the front side up, fold panel 2 behind cover panel 1 and alternate fold
direction at every remaining crease. The closed cover should face outward. No
glue or staples are required. Keep the guide in the concealed cable bay; do not
place it between the controller and the lid.

The first instruction panel deliberately places a stable firmware update before
device pairing. The recipient should connect USB power, configure trusted Wi-Fi
from the Home cog, choose **Settings > Firmware update > Check now**, install the
available stable release, keep USB power connected throughout preparation and
recovery, and press **Restart** when **Update successful** appears. Hidden Wi-Fi
networks use Portal. Manual Recovery mode is not part of the routine first-use
upgrade path.

Print dieline pages at **100% / Actual Size** with all automatic scaling
disabled. Check the 50 mm calibration bar before cutting. Solid magenta lines
are cuts and dashed cyan lines are scores/folds.

Start with ordinary paper to confirm scale and folding order. Make the next
article from 300-400 gsm cover stock or thin E-flute board. The insert is best
made from 1-1.5 mm E-flute or laminated cover stock. Apply adhesive only to the
orange glue tabs.

The dielines are prototype geometry, not production tooling. A packaging
vendor must compensate for its exact board caliper, crease allowance, print
bleed, grain direction, and cutting equipment before manufacturing samples.

For the five presentation samples, request a bright warm-white SBS board or a
white paper-wrapped rigid-board equivalent, digital CMYK printing, and a matte
anti-scuff finish. Ask for one physical color proof before the complete run;
soft-touch films can shift or yellow an otherwise clean white surface. A vendor
can replace the folded paper insert with white CNC-cut EVA/EPE foam while
retaining the same controller opening and concealed cable-bay arrangement.

## Fit assumptions

The controller pocket starts at 116 x 44 mm, leaving a nominal 1 mm supporting
lip at the enclosure ends and 2 mm along its sides for a 118 x 48 mm enclosure.
Print and cut the insert before ordering foam or production board. Enlarge the
opening in 0.5 mm increments only where the physical enclosure rubs.

The cable bay is 17 mm high. Use a compact cable folded flat rather than a
tightly wound coil. The quick-start card sits above the controller and should
be removed before lifting the device.

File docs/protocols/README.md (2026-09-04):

# Protocol research

The protocol notes here were derived from controlled captures and public
research. The public repository keeps extracted command vectors, annotated
behavior, hashes of the original research material, and confidence labels. It
does not ship raw packet captures.

- [Tascam Portacapture X8](tascam-x8.md)
- [Canon smartphone-mode BLE](canon-smartphone-ble.md)
- [Insta360 GPS Remote](insta360-gps-remote.md) — implemented X3/X4/X4 Air/X5 path
- [Insta360 Mini Remote](insta360-mini-remote.md) — implemented X5/X6 capture-backed path; panel gate open
- [GoPro Open GoPro BLE](gopro-open-gopro.md)
- [Zhiyun MOLUS X100](zhiyun-x100.md)
- [Zhiyun MOLUS X60RGB](zhiyun-x60rgb.md)
- [Android screen-recording + HCI capture workflow](capture-workflow.md)
- [Desktop BLE protocol harnesses](desktop-protocol-harness.md) — active
  central/client and macOS peripheral testing
- [Captive Portal discovery](captive-portal-discovery.md) — SoftAP DNS and
  phone connectivity-probe behavior
- [Signed firmware update protocol](firmware-update.md) — manifest, signature,
  replay, target, payload, boot-validation, and rollback rules

Raw captures were removed before publication because radio traces can contain
stable addresses, nearby device names, phone/camera identifiers, pairing
material, host paths, and unrelated traffic. A small filtered capture can still
leak identifiers in metadata or advertisements.

For contributions:

1. follow the [capture workflow](capture-workflow.md) so app actions, ATT
   traffic, reported state, and physical behavior remain distinguishable;
2. use the [desktop harness workflow](desktop-protocol-harness.md) when active
   protocol validation can safely isolate the protocol from firmware;
3. extract the smallest golden request/response or notification vectors needed
   to reproduce the conclusion;
4. replace device-specific identifiers and omit credential-bearing values;
5. document capture conditions, packet order, and the original capture's
   SHA-256 while keeping the raw material private;
6. keep confirmed behavior separate from `Research`, `Hypothesis`, and
   `Blocked` conclusions;
7. do not attach raw captures or mobile bugreports to public issues or pull
   requests.

Every protocol implementation or research tranche must add or update its note
in this directory at the same time as the code. Record known frame directions,
state transitions, confidence, capture provenance, and unresolved fields; do
not leave the implementation as the only protocol specification.

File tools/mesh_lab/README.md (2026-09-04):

# Bluetooth Mesh lab probes

These host-side research tools exercise a panel-owned Bluetooth Mesh without
changing firmware. They are intentionally separate from the production
runtime and currently consume the JSON state created by the sibling
`studio-lighter` research client.

Keep the state file outside the repository with mode `0600`: it contains the
network key, application key, and node device keys. The tools never print
those keys, but raw proxy traffic can still contain stable mesh metadata.

Install the optional dependencies in a separate environment:

```sh
python3 -m pip install -r tools/mesh_lab/requirements.txt
```

The probe used for the 2026-08-07 MC Pro run supports the individual
configuration operations needed to diagnose provisioning independently:

```sh
PYTHONPATH=/path/to/studio-lighter/src python3 tools/mesh_lab/mesh_probe.py \
  --state /private/path/state.json --address COREBLUETOOTH-IDENTIFIER composition-get

PYTHONPATH=/path/to/studio-lighter/src python3 tools/mesh_lab/mesh_probe.py \
  --state /private/path/state.json --address COREBLUETOOTH-IDENTIFIER appkey-add

PYTHONPATH=/path/to/studio-lighter/src python3 tools/mesh_lab/mesh_probe.py \
  --state /private/path/state.json --address COREBLUETOOTH-IDENTIFIER \
  vendor-bind --company-id 0x03f6 --model-id 0x1000

PYTHONPATH=/path/to/studio-lighter/src python3 tools/mesh_lab/mesh_probe.py \
  --state /private/path/state.json --address COREBLUETOOTH-IDENTIFIER sig-bind

PYTHONPATH=/path/to/studio-lighter/src python3 tools/mesh_lab/mesh_probe.py \
  --state /private/path/state.json --address TARGET-IDENTIFIER \
  --proxy-address GATEWAY-IDENTIFIER onoff-get
```

`--address` selects the logical node and its unicast destination from the state
file. `--proxy-address` independently selects the physical BLE Mesh Proxy. Use
different values to prove that a node is reachable through another fixture's
single proxy connection.

Additional read-only operations are `level-get`, `transition-get`,
`onpowerup-get`, and `lightness-get`. `onoff-on`, `onoff-off`, and
`lightness-set --lightness VALUE` send acknowledged messages with a transaction
ID derived from the durably reserved sequence number. Always restore a fixture
to its intended state after a lab run.

`soak --other-address SECOND --count 20 --interval 1` alternates acknowledged
Generic OnOff Get messages between two logical nodes while retaining one BLE
connection to `--proxy-address`. It reserves every sequence number before the
connection attempt and prints the encrypted notifications for offline decode.

`vendor-power-soak --count 20 --interval 1` repeats the confirmed read-only
group power poll over one retained proxy connection. A healthy two-member mesh
should return two authenticated, independently sourced statuses per request.
It does not change emitter state.

`sig-subscribe` adds the target node's Generic OnOff Server to the mesh state's
group address. After subscribing each member, `group-onoff-get` sends one Get
to that group; each reachable member should return its own sourced status.
`group-onoff-on` and `group-onoff-off` send one acknowledged state change to
the group; use `group-onoff-get` afterward to resolve every member separately.

`vendor-subscribe --company-id ID --model-id ID` subscribes a
composition-verified vendor model to the mesh group. `raw-unicast --access HEX`
and `raw-group --access HEX` are restricted to short, already-understood lab
payloads; do not use them for destructive or unknown opcode fuzzing.

After subscribing each tested vendor model to the panel-owned group,
`vendor-power-get`, `vendor-power-on`, and `vendor-power-off` use the confirmed
Ace 25c/MC Pro group protocol. The Set operations change real emitter power;
`vendor-power-get` returns one authenticated, source-addressed status per
reachable member. These commands deliberately target the mesh group: the same
captured power payload sent to either node's unicast address had no observed
effect. Run a Get after a Set and treat missing members as stale, not Off.

`listen --listen 20 --proxy-address GATEWAY` opens a passive Mesh Proxy
notification window without sending an access message. Use it while operating
fixture-local controls to capture unsolicited model/vendor publications.

`appkey-add` uses segmented lower transport. This is the important difference
from the old research sender, which incorrectly emitted the 20-byte Config
AppKey Add access message as one unsegmented PDU.

Use `decode_notifications.py` with the same private state file and one or more
hex Mesh Proxy notifications to decrypt and label responses. It intentionally
prints decoded opcodes and parameters, but not keys. Known configuration,
Generic OnOff/Level/OnPowerUp/Default Transition Time, and Light Lightness
statuses also receive semantic present/target/transition labels.
The correlated Ace 25c/MC Pro vendor power status is labeled with emitter
power, stored intensity, product profile, and checksum validity.

`zhiyun_probe.py` performs the captured read-only `0xFEE9` initialization and
state sequence against a provisioned X100/X60RGB gateway. It reports only the
resolved model and decoded light values; raw identity payloads are intentionally
not printed. Pass the member's persisted selector. The first Zhiyun member in
the mixed panel-owned test mesh was an X60RGB and used selector `0`:

```sh
python3 tools/mesh_lab/zhiyun_probe.py \
  --address COREBLUETOOTH-IDENTIFIER --selector 0
```

Pass `--power on` or `--power off` only when a deliberate physical state
change is intended. The probe follows the write with an independent readback.
X60RGB also accepts `--hue`, `--saturation`, and `--brightness`; each setter is
followed by an independent readback.

`decode_zhiyun_capture.py` timelines a ZY Vega Android HCI snoop log (from an
`adb bugreport`) for Zhiyun mesh research. It requires `tshark` on `PATH` and
prints one line per event: LE connect/disconnect with the peer address, PB-GATT
provisioning PDUs, Mesh Proxy/Network PDUs (classified but left encrypted), and
the cleartext `0xFEE9` frames decoded into direction, sequence, command, member
selector, and payload. Pass `--video-start HH:MM:SS` (phone local time of the
screen recording's first frame) to print the matching recording offset beside
every event, and `--all-att` to include unrecognized ATT traffic.

```sh
python3 tools/mesh_lab/decode_zhiyun_capture.py /private/path/btsnoop_hci.log \
  --video-start 20:23:24
```

The tool prints raw radio addresses, so keep its output outside the repository
with the rest of the private capture material. The two-fixture capture decoded
with it proved that the vendor routes a second Zhiyun member's control through
the first fixture's retained `0xFEE9` gateway link, each member on its own
stable selector; see `docs/protocols/zhiyun-x100.md`.

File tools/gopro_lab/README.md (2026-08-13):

# GoPro desktop protocol lab

This is the central/client form of the reusable desktop BLE protocol harness.
The Mac scans for a GoPro advertising `0xFEA6`, connects with Bleak, records the
discovered GATT shape and notifications, and tests the smallest Open GoPro
recording flow before any behavior is copied into firmware.

The lab deliberately separates four facts:

1. the host BLE API accepted a write;
2. the camera returned a successful command response;
3. status 10 (`Encoding`) independently reported the requested state; and
4. the operator observed the physical camera start or stop.

A successful command response is not recording-state confirmation. The current
firmware stops at step 2. This lab subscribes to Query Response (`GP-0077`) and
registers status 10 so that a firmware repair can be based on camera-originated
state.

## Environment

The repository's documented PlatformIO virtual environment already includes
Bleak. If a worktree has no `.venv`, use the main checkout's interpreter:

```sh
LAB_PYTHON="/Users/nethunter/dev/bleep/.venv/bin/python"
"$LAB_PYTHON" -m unittest -v tools/gopro_lab/test_protocol.py
```

On first use, macOS may request Bluetooth access for Terminal or Python. Put the
camera in its Open GoPro wireless pairing flow before scanning.

First list only matching advertisements. This is read-only:

```sh
"$LAB_PYTHON" tools/gopro_lab/client.py \
  --scan-only \
  --raw-all \
  --log /private/tmp/gopro-lab-scan.jsonl
```

Use the exact name or macOS CoreBluetooth identifier if multiple cameras are
nearby. A fresh pairing normally needs `--finish-pairing`; omit it when testing
whether an existing bond and protocol initialization work without that command:

```sh
"$LAB_PYTHON" tools/gopro_lab/client.py \
  --device "GoPro 1234" \
  --finish-pairing \
  --raw-all \
  --log /private/tmp/gopro-lab.jsonl
```

For a non-recording diagnostic, add `--status-only`. It connects, subscribes,
polls Hardware Info until ready, registers Encoding status, records the reported
idle/recording value, and exits without sending Set Pairing State or Shutter.

The harness subscribes to every discovered notifiable characteristic, polls
`Get Hardware Info` until the camera reports BLE readiness, and registers for
Encoding status. It tries the original one-byte status operation first and
records a fallback to the dedicated two-byte-ID operation if the camera rejects
it. Interactive commands are `status`, `query`, `register`,
`start`, `stop`, `pairing`, and `quit`. Start and Stop are rejected when the
last camera-originated Encoding status does not make the transition safe.

For a bounded five-second recording test:

```sh
"$LAB_PYTHON" tools/gopro_lab/client.py \
  --device "GoPro 1234" \
  --run-cycle \
  --record-seconds 5 \
  --raw-all \
  --log /private/tmp/gopro-lab-cycle.jsonl
```

Begin the cycle with the camera in video mode and physically idle. The runner
requires reported idle, sends Shutter On, waits for reported encoding, holds for
the bounded duration, sends Shutter Off, and waits for reported idle. It does
not claim physical success; record that observation separately.

Raw advertisements, GATT traffic, Hardware Info, and logs can contain a serial
number, stable BLE identifier, Wi-Fi identity, and model information. Keep logs
under a private directory such as `/private/tmp`, never in the repository. Add
only sanitized golden vectors and conclusions to public tests or protocol docs.

## Firmware comparison points

Compare the live transcript with these current firmware boundaries:

- whether a bonded reconnect needs Set Pairing State again;
- which notifiable characteristics must be subscribed on every connection;
- how many readiness retries precede a successful Hardware Info response;
- the exact short packets for Shutter and Encoding registration;
- whether Query Response reports `0x53` initially and `0x93` on transitions;
- whether camera-side or local-button changes also produce Encoding updates;
- command-response and reported-state timing; and
- disconnect/reconnect behavior after the camera sleeps.

Do not port a conclusion into firmware until the transcript and physical camera
agree. Desktop success does not validate ESP32 memory, NimBLE callback ownership,
multi-link coexistence, or panel UI behavior.

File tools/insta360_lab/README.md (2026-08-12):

# Insta360 Mac protocol lab

This is a private-capture harness for testing the X5 GPS Remote protocol before
moving a behavior into firmware. The Mac acts as the BLE peripheral, hosts
`0xCE80`, logs every camera write to `0xCE81`, and sends state-gated Start,
Stop, and power-off notifications on `0xCE82`.

The reusable design, CoreBluetooth callback lifecycle, validation sequence,
privacy rules, and limits of macOS advertising are documented in
[the desktop protocol harness guide](../../docs/protocols/desktop-protocol-harness.md).
This directory is the concrete X5 reference, not a generic multi-device runner.

macOS CoreBluetooth constructs the actual advertisement. Normal mode defaults
to the captured name `Insta360 GPS Remote` and, like the captured physical
remote, does not request CE80 in the advertisement; CE80 is still present in
GATT. `--advertise-service` enables a comparison probe. The longer firmware
name does not fit when macOS also inserts TX power and the service UUID, so
CoreBluetooth can silently omit it. Wake mode requests the captured Apple
manufacturer `ORBIT` data and `0 dBm` TX power; success from CoreBluetooth is
not proof that the controller emitted the capture-exact primary/scan packets.
On the development Mac, a cold-start nRF capture found no ORBIT frame even
though CoreBluetooth reported success. Use a raw-HCI-capable external adapter
when exact wake advertising matters.

A live X5 test confirmed that the minimal CE80-only GATT profile is sufficient:
the camera subscribed to CE82, sent its initialization and current video-idle
state without a query, accepted Start and Stop, reported recording/idle after
each transition, and disconnected after power-off. The two opaque services on
the captured physical remote are therefore not required for this X5 path.
Mac-native wake remains the one unsupported leg: no reconnect occurred during
a 128-second ORBIT request after shutdown because the requested ORBIT packet
was not present over the air.

Run from this directory with the repository virtual environment:

```sh
/Users/nethunter/dev/bleep/.venv/bin/python -m unittest -v test_protocol.py
/Users/nethunter/dev/bleep/.venv/bin/python remote.py \
  --camera-name "X5 SERIAL" \
  --raw-all \
  --log /private/tmp/insta360-mac-lab.jsonl
```

On first use, macOS may request Bluetooth permission for the terminal or Python
process. Select the advertised remote from the X5, wait for a decoded state,
then enter `start`, `stop`, `off`, or `wake`. Start and Stop are rejected unless
the preceding camera write confirms the safe video state. `status`, `normal`,
and `quit` are also available.

For an automated destructive cycle, begin with the X5 on, in video mode, idle,
with media available:

```sh
/Users/nethunter/dev/bleep/.venv/bin/python remote.py \
  --camera-name "X5 SERIAL" \
  --run-cycle \
  --record-seconds 5 \
  --raw-all \
  --log /private/tmp/insta360-mac-cycle.jsonl
```

The cycle waits for confirmed idle, starts recording, waits for confirmed
recording, records for five seconds, stops, waits for confirmed idle, powers
off, waits for CE82 unsubscribe, requests ORBIT wake advertising for up to 60
seconds, and finishes only after reconnect plus a new camera state. Transport
acceptance is logged separately from reported and physical state.

Raw logs may contain the camera serial and other stable identifiers. Keep them
outside the repository and sanitize any vectors before adding them to protocol
documentation.

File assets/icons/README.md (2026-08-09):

# Home Mode Icon Generation

The PNGs in this directory are the source artwork for the 48x48 Home mode
icons embedded in the firmware. Keep this prompt recipe when adding or
regenerating an icon so the Home grid remains visually consistent.

## Successful generation recipe

The current colorful icons were generated on 2026-08-03 with Nano Banana Pro,
using the model ID `gemini-3-pro-image-preview`, a square image response, and
temperature `0.8`. Model IDs may change; use the current Nano Banana Pro image
model when the recorded preview ID is unavailable.

Start every prompt with this shared style block:

> Fun colorful app icon for a round OLED studio remote home screen. Playful
> glossy sticker / toy-like 3D illustration, saturated cheerful colors, soft
> rounded shapes, delightful and quirky, not corporate. Subject centered on a
> pure black background with NO outer square frame, NO border plate, NO text,
> NO watermark. Square 1:1, generous padding so the glyph reads clearly at 48
> pixels.

Append exactly one concise subject description:

- **Devices:** `Subject: a cute cartoon motorized camera slider with a tiny
  smiling camera riding the rail, cyan and electric blue accents, warm orange
  wheels.`
- **Groups:** `Subject: three cute glowing LED softbox lights clustered as a
  friendly group, lime green, magenta, and gold colors.`
- **Scenes:** `Subject: a playful film clapperboard character mid-clap, sunny
  yellow and hot pink stripes, big friendly energy.`
- **Portal:** `Subject: a whimsical Wi-Fi portal doorway / gateway arch
  shooting playful signal waves, violet and turquoise neon candy colors.`

Device-category icons (Add device / Add scene step grids):

- **Motion:** `Subject: a cute cartoon motorized camera slider with a tiny
  smiling camera riding the rail, cyan and electric blue accents, warm orange
  wheels.`
- **Lights:** `Subject: a cute glowing LED softbox light character with a warm
  friendly face, lime green and gold colors, soft glow.`
- **Cameras:** `Subject: a cute cartoon mirrorless camera with a big friendly
  lens eye and a tiny smiling face, coral red and cyan accents, glossy body.`
- **Recorders:** `Subject: a cute cartoon portable audio recorder with chunky
  knobs and a smiling VU meter face, mint green and gold accents.`
- **Switches:** `Subject: a cute chunky rounded ON/OFF toggle switch with the
  knob visibly switched on and a tiny friendly face, turquoise and electric
  cyan track, sunny yellow knob, and coral accents.`

For a new mode or category, preserve the shared block and append a similarly
concrete subject sentence. Specify recognizable objects, a small palette, and
any important count or arrangement. Generate each icon independently as a 1:1
PNG. Save category icons as `icon_cat_<name>.png`.

## Review checklist

Before accepting generated artwork:

- the subject is recognizable when reduced to 48x48;
- the outer area is pure or near black for clean transparency keying;
- there is no enclosing app-icon frame, border plate, text, or watermark;
- the subject has generous padding and does not touch the image edges;
- colors and glossy, rounded forms match the existing four icons;
- the image is saved as `assets/icons/icon_<mode>.png`.

If a model adds a baked-in frame, repeat `NO outer square frame, NO border
plate` and describe the subject as a standalone glyph. If a result is too
abstract, state the exact object count and arrangement, such as “three
identical lights, one above two.”

## Embed into LVGL

The checked-in sources are 1024x1024 RGBA PNGs with transparent backgrounds.
Regenerate the 48x48 true-color LVGL arrays after changing any source:

```sh
python3 tools/gen_icons.py --size 48
```

`tools/gen_icons.py` keys the near-black background to transparency, crops and
scales the artwork, and writes `src/assets/ui_icons.c` and
`src/assets/ui_icons.h`. Review `sim/screenshots/01_home.png` after running the
UI simulator because fine details that work at 1024x1024 may disappear on the
panel.

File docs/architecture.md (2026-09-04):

# Architecture

## Goal

Ble(e)p is a direct Bluetooth and HTTP studio controller. A project builder
selects device drivers at compile time. The operator then creates, configures,
enables, disables, groups, and controls instances of those compiled drivers at
runtime.

The existing iFootage Shark Nano II behavior remains supported.

## System model

```mermaid
flowchart TB
  PanelUI["Round-panel UI"] --> DeviceManager
  PortalUI["Dedicated-mode HTTP portal"] --> DeviceManager
  SceneRunner --> DeviceManager
  DriverCatalog --> DeviceManager
  Groups --> DeviceManager
  DeviceManager --> SharkDriver
  DeviceManager --> AputureLightDriver
  DeviceManager --> ZhiyunLightDriver
  DeviceManager --> CanonTriggerDriver
  DeviceManager --> CanonSmartDriver
  DeviceManager --> HomeAssistantDriver
  DeviceManager --> FutureRecorderDrivers
  SharkDriver --> BluetoothRuntime
  AputureLightDriver --> BluetoothRuntime
  ZhiyunLightDriver --> BluetoothRuntime
  CanonTriggerDriver --> BluetoothRuntime
  CanonSmartDriver --> BluetoothRuntime
  CanonSmartDriver --> WifiHttpRuntime
  HomeAssistantDriver --> HomeAssistantRuntime
  PortalUI --> HomeAssistantRuntime
  ConfigStore --> DeviceManager
  ConfigStore --> SceneRunner
```

All state mutation, command dispatch, and LVGL access remains serialized
through the Arduino `loop()`. Transport callbacks may only queue bytes or
events.

## Current foundation implementation

ADR-013 advances a bounded subset of this architecture before the transport
feasibility spikes:

- the main profile's `DriverCatalog` contains Shark Nano II, Canon Trigger,
  Canon Smart, Tascam X8, Home Assistant, and one discoverable generic Aputure
  Light entry, and one experimental multi-instance Zhiyun Light entry for
  captured MOLUS profiles;
  smaller profiles compile selected drivers out;
- `DeviceManager` owns a dynamically allocated registry with a fixed persisted
  ceiling, command/result queues, up to eight logical active instances grouped
  onto four physical BLE transport slots, per-owner lifecycle, and persistence;
- schema version 2 stores up to twenty-four device records in the `studio` NVS
  namespace and retains records for unavailable driver IDs. Version 0.3.0 is a
  deliberate current-schema boundary: older device, scene, and mesh encodings
  are rejected rather than migrated. HA credentials/token and panel-owned mesh
  secrets use separate checksummed records;
- a missing registry is initialized empty. Pre-registry Shark storage and the
  former default-placeholder cleanup path have been removed;
- the catalog permits one Shark, up to three Canon Trigger instances, up to
  three Canon Smart instances, and one Tascam X8 within the twenty-four-record
  registry;
- Home and Devices load without initializing NimBLE; the first requested BLE
  device lazily starts one shared central runtime, and the last release shuts
  it down;
- Groups and the remaining generic device-type UI remain unimplemented. The first
  GATT facade tranche (ADR-021) now centralizes scanning, async links, retries,
  address claims, security serialization, bonds, and teardown for all four BLE
  clients. Panel Scenes (ADR-020/037) provide generated or custom Stop
  sequences with concurrent Canon Smart + Tascam links. ADR-023 adds bounded
  Portal provisioning and four local HA entities. ADR-024 adds an experimental
  userspace PB-GATT/Mesh Proxy Aputure Light tranche. Both target hardware gates remain
  open. ADR-028 shares that panel-owned provisioning repository and PB-GATT
  engine with Zhiyun lights, then adds model-profiled direct `0xFEE9` control
  with confirmed readback;
  user-authored native groups remain deferred.

Scene records use a dynamically growing, checked-allocation registry rather
than a configured scene-count ceiling. The current schema v4 stores compact
authored steps, a 32-bit scene count, and generated/custom Stop mode. Older
schemas are intentionally rejected at the 0.3.0 clean-storage boundary. RAM
and available NVS space remain real resource boundaries; failed growth or
persistence rolls the attempted mutation back without changing existing
scenes.

## Compile-time driver catalog

`Kconfig.projbuild` will provide a Linux-kernel-style menu for:

- device families and individual model drivers;
- Bluetooth GATT, Bluetooth Mesh, and Wi-Fi/HTTP transports;
- scenes, dedicated Portal mode, and optional UI modules;
- memory-sensitive limits such as connection and queue counts.

Selected drivers register immutable metadata in `DriverCatalog`:

- stable driver ID, brand, model, and device type;
- required transports;
- discovery, pairing, and configuration schema;
- capabilities, commands, and state fields;
- generic UI module plus optional specialized UI extension.

Disabled drivers must not link protocol code, tasks, buffers, assets, or UI
extensions into the firmware.

Compiled drivers are also dormant in RAM until used. Their global adapter is a
small shell containing only pointers/counters; clients, protocol sessions,
transport queues, and shared repositories are allocated on first activation.
Configured-but-inactive devices occupy only registry metadata. Maximum-instance
values constrain configuration and concurrency and must never size eager arrays
of full sessions. Allocation failure is reported through the normal activation
or registry status path without partially activating a driver. The shared BLE
backend follows the same boundary: its implementation state is allocated by the
first BLE activation and released after the last asynchronous client teardown.
When no BLE-backed driver is compiled, its main-loop pump and implementation are
omitted from the linked image.

## Runtime device registry

A device instance is separate from its compiled driver. It stores:

- stable instance ID and display name;
- driver ID and enabled state;
- pairing identity or HTTP endpoint;
- transport preference and fallback;
- model-specific configuration;
- group membership.

Multiple instances may use one driver. If firmware is rebuilt without a
previously used driver, its stored instance remains dormant and can reappear
when that driver is compiled back in.

Runtime disable prevents discovery, connections, polling, commands, and menu
presence. It releases that instance's runtime session but does not recover the
driver's flash code; removing the driver at compile time recovers flash.

## Startup and connection lifecycle

The firmware always boots to a neutral Home menu. Boot does not scan, pair,
re-pair, reconnect to Shark, or load a device control screen.

Home provides:

- Devices;
- Groups;
- Scenes;
- Portal;
- status and power controls.

Opening a device screen acquires a foreground owner for that instance. Opening
a sequence run screen acquires a sequence owner for every materialized
Start/Stop target.
Preparation reaches `Ready` only after
every target is physically connected and its driver reports protocol readiness.
The run screen shows one category-icon chip per target. A chip borrows the
already-held activation to open full device controls, then returns without
tearing down that device or its peers. Once a session reaches protocol readiness,
removing its last owner parks a healthy link in the retained pool. If that
ownerless link later drops unexpectedly, its transport is deactivated instead
of continuing background reconnect; acquiring it again starts the normal
bounded connection path. Attempts that never became ready are canceled.
When a retained instance gains a new owner, `DeviceManager` invokes the
driver's bounded resume hook before attaching that owner. Canon Smart uses this
hook to reconnect and wake a session that the panel previously powered off;
other drivers leave their retained transport unchanged.
Mixed BLE/Home Assistant sequence preparation gives cold physical transports a
60-second ceiling, then starts a fresh 30-second deadline when deferred
Wi-Fi/WebSocket preparation begins. Switching between scenes atomically
transfers sequence ownership for their shared targets. Those targets never
become idle eviction candidates; old-only targets release sequence ownership
but remain retained until ordinary capacity-driven LRU needs room, and a
physical transport group remains protected when any member is shared.
Logical active-instance capacity is separate from physical BLE capacity. Each
driver supplies a `BleSlotKey`: ordinary GATT instances use their instance ID,
non-BLE runtimes use no key, and logical members sharing one real transport use
the same key. A new key at the four-slot limit evicts the least-recently-used
transport group only when every member of that group is idle and unprotected;
the complete group is deactivated so eviction actually frees its one central
link. The logical-instance limit may evict one idle instance independently.
Neither path evicts sequence/foreground owners, pending commands, or confirmed
recording. No device is selected or restored implicitly at boot.

### Shared BLE central

`src/core/ble/` contains a bounded backend-independent coordinator and the
NimBLE backend. Device clients acquire one link handle and retain only their
protocol policy: advertisement matching, candidate choice, GATT discovery,
subscriptions, handshakes, commands, and notification parsing.

One physical scanner fans fixed-size advertisement observations to every
interested link. It runs in four-second bursts separated by 1.5-second pauses,
with a 40/100 scan window/interval while active. Selecting a peer removes only
that subscriber's scan demand;
other preparing devices continue to receive observations except while the
controller is initiating or securing a connection. Discovery pauses for that
bounded procedure and resumes automatically for every remaining requester.
Address claims keep two clients from selecting the same peer. Connects are
asynchronous and use independent slots with a bounded watchdog and
`1500 * min(failures, 4)` retry
backoff. A saved target receives three direct attempts before rediscovery, which
avoids paying scan latency for the common case where a nearby peripheral needs
one or two radio-wakeup retries. The ESP32-C3 initiates at most one physical connection or security
procedure at a time; queued targets continue sharing discovery, and the next
link can connect while an already-linked driver's protocol initialization runs.
This avoids observed HCI `0x3e` establishment timeouts without serializing the
entire preparation pipeline. Canon security procedures are also serialized
because NimBLE security configuration is controller-global.

The central tracks physical connection separately from protocol readiness and
clears readiness on retry, failure, release, and reconnect. Drivers publish
readiness only after their final required subscription, identity/session write,
handshake, and initial refresh has succeeded. Connection setup is scheduled on
the next main-loop pass so queued link events can drain first. Drivers request
targeted service/characteristic/descriptor discovery rather than full attribute
walks. The backend also makes best-effort connection-parameter requests: 7.5–15
ms during setup and 30–50 ms after protocol readiness; rejection is diagnostic
and non-fatal.

The NimBLE controller is initialized with the compile-time
`CONFIG_BLE_TX_POWER_DBM` setting. The shared configuration defaults to +6 dBm
rather than leaving the value implicit; builds may select another value from -24
through 20 dBm when their range/current trade-off requires it. NimBLE maps the
request to a radio-supported level. These radio policies reduce average and
peak demand but are not electrical protection for the CrowPanel battery-input
path.

Serial-only `ble_timing` records cover activation, scan/direct connect, link,
security, GATT setup, protocol readiness, retries, teardown, and total sequence
preparation. A shared asynchronous GATT executor remains conditional: implement
it only if ten-cycle hardware measurements show blocking GATT work consumes at
least 25% of median readiness time for any driver or the concurrent Canon Smart
+ Tascam pair. Until that gate is met, UUID selection and GATT sequencing remain
driver-owned under ADR-021.

NimBLE host callbacks only enqueue fixed-size scan/link/security events.
`loopBleRuntime(now)` drains them before `DeviceManager::loop()`, so matching,
state mutation, GATT setup/writes, and all LVGL access remain on the main loop.
The first acquired link initializes `Ble(e)p` with MTU 247; releasing the last
link begins client deletion and deinitializes NimBLE only after asynchronous
client teardown has actually emptied NimBLE's global slots. An immediate
reacquire can reserve links during that interval; the backend provisions their
replacement clients as capacity returns. Backend callback objects have backend
lifetime rather than link lifetime, and final GAP events are accepted only when
their client pointer still owns the logical slot. Control events also carry the
slot generation that queued them, so an event already waiting when LRU eviction
reuses a logical handle is discarded instead of being delivered to the
replacement device.

Peripheral-role profiles share that same lazy NimBLE host rather than starting
a second controller. Phone Camera and Insta360 use a shared server-callback
dispatcher so the singleton NimBLE server never has competing callback owners.
The first active peripheral-camera driver registers every compiled camera
peripheral service before accepting a connection, because NimBLE cannot safely
extend its GATT table around retained peers. A shared advertiser gives each
disconnected peripheral family or bonded phone a bounded reconnect window;
connected sessions remain simultaneous and advertising continues for the next
offline target. Phone Camera keeps the host alive through a private radio lease
and routes each authenticated inbound connection by bonded identity. Insta360
scans camera advertisements for peer classification and exposes separate GPS
Remote and Mini Remote catalog drivers over one lazy runtime. The selected
profile controls the captured advertising identity, scan response, and shutter
vector while both profiles host the shared proprietary `0xCE80` and HID GATT
table. When disconnected instances require both identities, the shared
advertiser alternates bounded windows; an inbound camera connection is routed
to the saved or provisional instance for the identity it selected. The
inbound connection still has its own `BleSlotKey`, so it counts against the
same four-link budget as outbound central connections. Server callbacks enqueue
only bounded connection/authentication events; security requests, HID/shutter
reports, state changes, persistence updates, and teardown run from the main loop. Sony
remote emulation will use this peripheral-role boundary only after hardware
validation of its public reverse-engineered protocol.

## Capabilities and unified UI

Shared device-type UI modules consume capabilities rather than brand-specific
state:

- `light`: power, brightness, CCT, tint, HSI;
- `camera`: record start/stop, recording state, and later camera controls;
- `motion`: run, stop, progress, keypoints, and manual movement;
- `recorder`: record start/stop, recording state, battery, and media status.
- `switch`: explicit on/off with confirmed state;
- `action`: explicit Press or Activate with no inferred toggle/value action;
- `input_boolean`: explicit On/Off commands with one context-sensitive entity
  button that sends the opposite of the last confirmed state.

Light drivers additionally publish a normalized `LightControlState` containing
supported modes and limits, current or optimistic values, power, pending/error
state, and confirmation quality. A single round-panel shell consumes that
state for Aputure Light, Zhiyun Light, and Home Assistant light instances and
hides unsupported rows without changing navigation or command debounce. The
brand modules retain onboarding only; they do not construct dormant legacy
control screens behind the shared shell. Home Assistant constructs its generic
entity screen only for non-light domains.

Home Assistant is the first dynamic-profile driver: each persistent instance
derives its device type and capabilities from its stored entity domain rather
than the driver's catalog row. Device pickers, scene validation, and command
selection query this instance profile. Four HA instances share one retained
network runtime and do not consume the four physical BLE link slots.

### Home Assistant Portal and runtime

Portal suspends scenes and physical links. If studio Wi-Fi is not configured or
cannot be joined, it performs a bounded asynchronous station scan before
starting a temporary open SoftAP. The SoftAP-bound administration console offers
the initial cached results, a fresh non-blocking scan on request, manual
SSID/password entry, and all local device and sequence configuration. HTTP and
DNS servicing continue while an AP-mode refresh scan is pending. The panel's QR
code identifies the open setup network.
While the AP is active, wildcard DNS sends probe hosts to the panel. Known
Apple, Android, and Windows connectivity-check paths, plus other unknown GET
paths, receive the non-empty Portal page directly with status 200 so phones can
recognize the network as captive and present the setup page as a sign-on screen.
The join is a main-loop state machine, leaving HTTP and LVGL responsive while the
browser and panel report scanning, connecting, success, timeout, missing SSID,
or rejected credentials. A successful join saves those credentials, exposes
the assigned numeric LAN address during a bounded handoff, destroys the AP,
binds a new listener to the station address, and advertises a best-effort
`http://bleep.local` mDNS alias. The same responsive console serves overview,
committed-device administration, and current authored Start/Stop sequence
editing on either AP or LAN. HA setup, discovery, and testing are enabled only
after station handoff. Physical pairing, device commands, and sequence execution are
deliberately absent. Discovery incrementally parses `/api/states`; the browser
receives at most 24 bounded summaries and may select four. The default URL is
`http://homeassistant.local:8123`. Secrets are password fields and never appear
in `/api/config`; it returns only whether a token is already stored, and a blank
submission preserves that stored value. Exit or ten minutes of inactivity
stops HTTP/mDNS, disconnects STA, and returns Wi-Fi to off.

Opening an HA screen or preparing an HA scene target allocates and acquires the
shared `HomeAssistantRuntime`. It joins Wi-Fi, authenticates `/api/websocket`, fetches
each active entity's initial state through REST, and installs a
`subscribe_trigger` state subscription containing only active entity IDs.
Once that authenticated subscription succeeds, the transport is command-ready;
if the memory-gated initial REST read is still deferred, the configured entity
is exposed as available with unknown state until REST or a subscribed event
confirms it. This keeps state reporting honest without blocking mixed-radio
sequence preparation on an optional readback.
Callbacks copy at most two 2048-byte frames; the main loop parses them with
ArduinoJson, mutates state, sends service calls, and updates LVGL. Malformed,
oversized, or dropped frames mark state unknown and schedule a bounded REST
refresh. A successful service result completes action delivery because an
idempotent call may not emit a state-change event. Subscribed events and
heap-gated REST reconciliation update state independently, so API acceptance
does not promote unknown state to confirmed. Only HTTP 404 means missing, while
transport and parse failures remain unknown. The runtime disconnects
Wi-Fi after its final HA instance is evicted or explicitly unlinked. Merely
saving HA entities or credentials does not allocate the client or start Wi-Fi;
outside Portal, active HA ownership, and a bounded updater check the radio is
explicitly `WIFI_OFF`.

Mixed sequences initialize every physical transport before acquiring any Home
Assistant target, independent of authored action order, unless the platform's
early-network policy reports that the BLE runtime is already up with enough
heap; then Home Assistant's Wi-Fi starts while the peripherals are still waking. On the ESP32-C3,
NimBLE initialization requires a contiguous allocation of roughly `0x7800`
bytes; starting Wi-Fi first can fragment/deplete the heap and causes the
underlying BLE library to assert instead of returning a recoverable error.
Scene handoff does not proactively tear down either HA or physical retained
sessions. Old-only targets become ownerless but stay connected while the
four-resource pool has capacity. Acquiring a fifth logical resource or BLE key
uses the normal LRU paths, which skip every shared target because it retains
sequence ownership. This keeps HA, Canon, Tascam, and Aputure Light connected together
when they exactly fill the pool. Action execution still follows the authored
order after all targets prepare. The LVGL pool is held to 64 KiB
and the target keeps two 15-row DMA display strips, returning 47.2 KiB of
static SRAM compared with the earlier 96 KiB/40-row configuration. The full
simulator flow is the regression gate for the LVGL allocation budget. HA keeps
two 2 KiB WebSocket frame slots; oversized state events intentionally become
unknown and use the individual REST recovery path. A WebSocket disconnect is
reported to the main loop as a flag, where authentication and subscription
state are cleared and a bounded reconnect is scheduled.
Transient failures while resolving an entity's initial REST state leave the
entity command-ready but unknown: one entity is retried at a time after a
bounded delay. HTTP 404 remains a terminal missing-entity result; transport,
other HTTP, and malformed JSON results remain unknown and retry.

Drivers publish limits and availability. For example, a CCT-only light does
not expose HSI controls. Specialized workflows such as Shark keypoints may
extend the common motion UI without leaking into other drivers.

### UI allocation optimization

Home and the Devices shell remain resident. Device rows, device screens,
management overlays, and keyboards are created on entry and deleted after
navigation leaves them.
Device and transport state remains owned outside LVGL so destroying a view
never discards protocol state.

Canon (Smart) and Tascam share `src/ui/recorder_shell.*`, driven by a small
view model and typed command callbacks. The shared shell provides connection,
recording, transition, confirmation, and failure states; driver adapters add
optional controls such as Canon's explicit power button or dual Start/Stop
controls for unknown state. Shark retains specialized keypoint and motion
views, and creates only the connect screen plus connected screens/overlays
while active.

Devices **Add device** and Scenes **+ Step** share `src/ui/picker_shell.*`: a
category icon grid, then a driver or enabled-device list, then (for scene
steps) Record Start / Stop. The overlay is created on open and deleted on
close.

The sequence run screen reuses the same category icons in circular target
chips. Their borders breathe cyan during connection/protocol setup, stay green
when protocol-ready, turn red after a terminal connection failure, and remain
muted gray when simply disconnected or powered off. Chip navigation is disabled
while Start or Stop steps execute; a compact status label remains above
Cancel/Done.

The CrowPanel vibration motor is driven by PI4IOE5V6408 expander output P0. A
shared main-loop sequencer provides four semantic patterns: Press is one 20 ms
tap; Connected is 12 ms on, 24 ms off, then 12 ms on; Back is 15 ms on, 35 ms
off, then 30 ms on; Error is 60 ms on, 45 ms off, then 60 ms on. LVGL's input
feedback callback requests Press only after a click is accepted, and navigation
handlers replace that generic pulse with Back. Connected fires when the current
device becomes protocol-ready, when an already-ready retained device is opened,
or when sequence preparation reaches `ScenePhase::Ready`; it queues behind a
stronger active pattern. Foreground command failures, pending-add save failures,
sequence failures, and terminal Portal errors request Error only on their
transition into failure.
Stronger patterns take priority, and no pattern delays UI, transport, or scene
work.

The Devices screen remains unpaged through six records. Pagination controls
appear only at seven or more records, with six records per page. Device rows
are released before a specialized control screen or rename overlay is
allocated. The full capture run still includes the largest specialized control
and sequence-stop screens. Target heap recovery remains part of ADR-023's open
hardware gate.

State fields carry a quality:

- `unknown`: no usable value;
- `optimistic`: inferred from a command without readback;
- `confirmed`: observed from the device.

## Groups

Groups are named collections of runtime instances. A group exposes only the
capabilities common to all enabled members. Commands fan out and retain a
result for every member.

Groups are valid scene targets. An incompatible or unavailable group action is
rejected during scene validation.

## Bluetooth architecture

GATT is accessed through a transport facade:

- all current BLE builds use one lazy NimBLE central;
- Shark, Canon, and Tascam use their device-specific GATT services;
- Aputure Light and Zhiyun lights share one panel-owned mesh repository, durable unicast
  allocator, and userspace no-OOB PB-GATT provisioner over that central;
- the mesh runtime owns one retained proxy client. A dynamically allocated
  `ProxyTransport` reference-counts logical users and prefers a saved Zhiyun
  node whenever the active set requires the additional `0xFEE9` service. It
  exposes standard Mesh
  Proxy Data In/Out to Aputure Light access messages and lets saved Zhiyun
  sessions attach their separate `0xFEE9` characteristics to that same native
  client;
- `DeviceManager` charges the complete panel-owned Aputure Light/Zhiyun mesh one
  `BleSlotKey`, so adding or retaining another member does not consume another
  one of the four physical slots;
- the generic, multi-instance Zhiyun driver accepts reset or provisioned
  product-qualified `pl105` X100 and `plx104` X60RGB advertisements. It uses
  PB-GATT when provisioning is required, rediscovers the Mesh Proxy advertiser,
  then initializes and controls the separate `0xFEE9` GATT service. Its writes
  remain pending until correlated device replies confirm the requested values.
  Saved members persist a routing selector and share one gateway notification
  stream; unique transport sequences keep concurrent replies attributable;
- PB-GATT onboarding is a temporary exclusive link. After a saved node is
  reopened, steady-state control attaches to the shared proxy bearer rather
  than allocating another central slot;
- callbacks enqueue only bounded events or raw bytes; mesh crypto, parsing,
  persistence, and writes remain on the main loop.

Concurrent Aputure Light proxy, Shark/Canon/Tascam GATT, provisioning recovery, and
post-teardown heap remain an ESP32-C3 hardware feasibility gate.

## Dedicated Portal mode

The administration server does not run during normal operation.

Entering Portal mode:

1. refuses entry or requests confirmation if a scene is active;
2. suspends device connections;
3. joins saved studio Wi-Fi, or scans before starting a temporary open SoftAP
   whose administration console supports local device/sequence changes and
   optional Wi-Fi credentials, with an on-panel Wi-Fi QR code and AP-scoped
   captive-portal discovery;
4. after joining, shows the numeric station address, closes the AP, and binds
   the bounded HTTP server there with `bleep.local` as best-effort discovery,
   and changes the QR code to the numeric Portal URL;
5. displays the active network, URL, timeout, and Exit on the panel.

Both listeners expose bounded JSON APIs for summary, device records, sequences,
and non-secret HA configuration. HA discovery/testing and secret writes require
LAN mode. Each session has a fresh mutation nonce;
state-changing requests without it are rejected, CORS is not enabled, and the
page is served with no-store and frame-denial headers. Device and sequence
changes pass through their normal registries, validation, and checked NVS
writes. Failed persistence restores the prior in-memory state, stale sequence
revisions are rejected, and referenced devices cannot be removed. Records for
drivers omitted from the current build remain visible but unavailable.

Exiting Portal mode, reaching the inactivity timeout, or rebooting destroys the
HTTP server, mDNS responder, SoftAP, and station connection before restoring
normal operation. Teardown tests must verify that no listener, AP, server task,
or portal buffer remains active.

Canon CCAPI is unavailable in Portal mode because normal station-mode control
is intentionally suspended. The portal is exposed on the trusted studio LAN
only for the lifetime of the active Portal screen.

## Local settings and support information

Home adds a cog without replacing Devices, Groups, Scenes, or Portal. Settings
and its Wi-Fi, About, System Info, and Factory Reset views are created on entry
and destroyed on exit. The Wi-Fi view reads the saved SSID and labels the
normal state as radio-off without starting the radio. An explicit scan
allocates a bounded main-loop Wi-Fi configuration service, lists at most 16
visible deduplicated SSIDs by signal strength, and associates only after the
operator selects a network and enters any required password. A non-zero DHCP
address is the success boundary; internet access is not required. The service
saves only a successful replacement and returns Wi-Fi to off after success,
failure, timeout, or cancellation. Retained equipment requires a separate
**Disconnect & scan** confirmation, while an active command blocks scanning.
The Portal remains available from this page for hidden SSIDs, phone-based text
entry, and Home Assistant configuration. **Forget network** clears only Wi-Fi
credentials and preserves Home Assistant URL, token, and entity records.

About is the first Settings item. The menu and About body scroll independently
within round-safe page regions, while Factory Reset remains a distinct top-level
menu item. Destructive styling appears only after it opens the separate warning
and hold-confirmation view.

Haptic enablement is a separate checked NVS record and gates the shared
non-blocking sequencer without changing its semantic patterns. About embeds a
small LVGL logo and build identity. System Info samples heap, largest
allocation, minimum heap, physical BLE groups, and Wi-Fi mode on the main loop
without exposing secrets or stable device identifiers.

Factory Reset is deliberately stronger than clearing an individual registry.
After a three-second hold it cancels work, deactivates transports, journals a
reset request, and boots fixed recovery. Recovery first downloads and verifies
the latest signed stable main image. Only after that succeeds does it erase the
complete NVS partition, including BLE bonds and mesh identity, select main, and
reboot. Failed networking or verification leaves NVS untouched.

## Signed firmware updates

`FirmwareUpdateService` is a bounded main-loop state machine covering startup
pending/checking, scheduled, foreground-deferred, connection, manifest check,
availability, failure, and recovery handoff. Home and stores are rendered
before its clock starts. On each boot with saved Wi-Fi it checks the selected
channel after five seconds of eligible idle Home. Foreground activity defers a
not-yet-started check or cancels an in-progress HTTP request without releasing
equipment. Ten-minute idle eligibility, 24-hour success cadence, 1/6/24-hour
network backoff, and Settings-triggered checks remain available afterward.

The updater fetches only the bounded signed manifest and detached signature.
It is a temporary network owner and returns its station to `WIFI_OFF` on every
terminal or cancellation path. Teardown disconnects first and stops the radio
only after a bounded main-loop settling interval, so ESP-IDF's tcpip task cannot
race driver deinitialization while sending DHCP release. Recovery handoff lets
the imminent reset stop Wi-Fi. Confirmed installation persists the exact
signed request and releases retained links with consent. Main first verifies
and selects its own `ota_0`, then restarts immediately without painting an
intermediate progress overlay. That boot initializes only the display, touch,
LVGL, and a circular update-progress view; device runtimes, scenes,
Portal, Home, and normal services remain dormant. It downloads, writes, and
validates the signed recovery payload in the factory partition, selecting
recovery only after verification succeeds. A failed attempt falls through to
the normal main UI with a retry action. A newly installed main that remains
pending its ten-second health gate skips this early path. The newly updated
recovery verifies the same request again and streams main into `ota_0`; no
second full firmware image is retained. See
[the signed update protocol](protocols/firmware-update.md) for manifest trust,
stream validation, replay rejection, journal recovery, and partition geometry.
The bounded encoded journal records use checked `nothrow` heap storage during
load/save; they are never multiplied on the Arduino loop-task stack.
If power is lost before the recovery write begins, the intact journal makes the
next valid main boot resume it before normal services. Once the factory
partition has been erased, loss of power can leave
recovery unbootable; main remains selected when possible, but a later main
failure then requires the NVS-preserving USB web recovery flow. Main and
recovery release sequences are tracked independently. After main passes its
health gate, it clears the completed install journal; Factory Reset retains its
post-main recovery-refresh compatibility path.
Manual Recovery mode uses a two-second hold and persists a distinct request so
fixed recovery remains on its menu until the operator explicitly boots main or
chooses another action.
Recovery ignores all touch during a 1.5-second boot guard, then requires 300 ms
of continuous release before arming menu input. This prevents touch-controller
startup from being mistaken for release while the initiating finger is still
held over a menu row. A blank migration journal plus a valid main image causes
an automatic one-time handoff to `ota_0`; corrupt or unreadable journal state,
an explicit Recovery Mode request, or invalid main keeps the recovery menu and
its **Boot firmware** action available.
During a main-image download, recovery paints the static install view once and
updates only the progress bar and percentage region. After the image and hash
verify and `ota_0` is selected, recovery remains on an explicit success screen;
it reboots only after the operator presses **Restart**.

## Persistence

Versioned persistent records cover:

- Wi-Fi credentials and Canon endpoints;
- runtime device instances and groups;
- panel-owned mesh identity and keys;
- scenes and execution metadata;
- schema version and compatibility status;
- panel preferences such as haptic enablement.
- firmware channel plus installed, available, and dismissed release sequences.

Secrets are masked in UI and logs. Backups exclude keys and credentials unless
the operator explicitly requests a protected full export.

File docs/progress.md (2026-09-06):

# Project Progress

Update this file at the end of every implementation session. Keep entries
short, factual, and reproducible.

## Current status

### 2026-09-06: Finish swatches and illustrated action-button push

- Added independent body swatches (Ivory, Graphite, Sand, Stone, Orange) and
  button swatches (Orange, Blue, Black), based on the operator's finish photo.
  Body colors affect both shell parts; the button material remains independent.
  Stone uses procedural speckles in assembly coordinates. Swatches show the
  selected name and pressed state, with compact desktop and mobile layouts.
- Clicking the actual top-right CAD button plays one short inward push and
  automatic release. There is no separate Press control or held-button UI, and
  the animation does not change the screen tour. Enter/Space on the focused
  model provides equivalent keyboard access. Nearby ray samples improve the
  small button target while respecting enclosure occlusion. Dragging continues
  to rotate the model. Reduced motion uses an immediate pressed/resting pose.
- Browser checks verify pixel changes for all finishes, independent selection,
  a direct CAD-button click, visible push and return to identical resting pixels,
  keyboard access, rotation, and back occlusion. Screenshots reviewed at desktop
  and phone sizes. Layout checks pass at 320/390/768/1024/1440 px; desktop/mobile
  Axe and JavaScript error capture are clean. Existing screen-tour animation,
  pause, five functions, offscreen behavior, and fallback checks pass.
- Context-loss checks hide controls, preserve chosen finishes on restoration,
  and restore button animation. Missing geometry retains the poster; missing
  optional screen-tour assets retain finish choices and button animation.
  CSS and main/model JavaScript use `20260906-8` URLs. Syntax, artifact, and
  whitespace checks pass. Full Montserrat `bleep` build passed using the shared
  environment: 147,220 bytes RAM, 2,038,518 bytes flash. No firmware behavior
  changed, native tests were not needed, and no hardware was flashed.
- Rebased onto current `origin/main`, merged from `main` with `--no-ff` as
  `55835ee`, and pushed. Firebase Hosting released 54 files. Live HTML, CSS,
  and main/model JavaScript match the reviewed bytes. Production checks
  confirm independent Stone/Blue selection, a mouse click on the actual CAD
  button followed by automatic release, no separate Press control, mobile
  layout fit, and no JavaScript/CSP errors. Live mobile screenshot reviewed;
  artifact check passes (441 tracked files).

### 2026-09-06: Present phones as cameras

- On operator correction, folded iPhone, Galaxy, Pixel, OnePlus, and Xiaomi/Redmi
  into the homepage Cameras category. Removed the separate Phones category and
  compatibility section; phone candidates now appear next to the existing Pixel
  camera entry in the standard matrix. Preserved evidence labels and camera
  setup sources. The old `#phones` anchor now targets that matrix row.
- Removed unused phone-section CSS and advanced shared CSS URLs to
  `20260906-7`. Homepage has exactly Cameras, Lighting, Audio, and Motion.
  Browser checks pass at 320/390/768/1440 px, with no JavaScript errors or
  mobile compatibility Axe violations. Visually reviewed the camera category.
  Artifact and whitespace checks pass. Full Montserrat `bleep` build passed
  using the shared environment: 147,220 bytes RAM, 2,038,518 bytes flash.
  No firmware behavior or support status changed; no native tests or flash.
- Rebased onto current `origin/main`, merged with `--no-ff` as `9da0646`,
  and pushed. Firebase Hosting released 54 files successfully. Live browser
  checks confirm four equipment categories, phones within Cameras, the matrix
  row in place of the removed section, mobile fit, and no JavaScript errors
  or mobile Axe violations at `https://bleep.hml.tech`.

### 2026-09-06: Authentic equipment logos and visible phone families

- Replaced the six typeset equipment names with manufacturer artwork for Canon,
  amaran, Insta360, Tascam, iFootage, and GoPro. Assets are self-hosted and
  rendered as ink-colored CSS masks with their original proportions. Official
  source URLs and extraction details are recorded in `website/README.md`.
  SVGs contain local vector paths only; no embedded scripts or remote assets.
- Added a homepage Phones row linking to a dedicated compatibility section for
  iPhone, Samsung Galaxy, Google Pixel, OnePlus, and Xiaomi/Redmi. Manufacturer
  camera-setting sources explain the volume-key convention. These are named
  examples of the existing experimental iOS/Android candidates, not additions
  to the Supported list: Pixel 9 retains its verified reconnect/shutter evidence,
  while other families and other Pixel models remain unverified. No firmware,
  support classification, or manual changes are made by this website tranche.
- Desktop/mobile screenshots reviewed. Checks pass at 320, 390, 768, 1024,
  and 1440 px; fixed a discovered 768 px logo-strip overflow. All six logos,
  five phone-family cards, and the homepage-to-phone-section link are present.
  Homepage and compatibility desktop/mobile Axe checks report no violations;
  browser JavaScript error capture is clean. Shared CSS URLs use `20260906-6`.
  Repository artifact and whitespace checks pass. Full Montserrat `bleep`
  compiled in the shared environment recorded below: 147,220 bytes RAM and
  2,038,518 bytes flash. Native tests were not needed for website-only work;
  no hardware was flashed or phone compatibility physically tested.
- Rebased onto current `origin/main` without conflicts, merged from `main`
  with `--no-ff` as `5857f20`, and pushed. Firebase Hosting released 54 files.
  Live HTML, compatibility page, versioned CSS, and all six logos match the
  reviewed bytes. Production browser checks pass at all five widths, including
  the clean-URL phone anchor, five family cards, six logos, and homepage plus
  compatibility desktop/mobile Axe scans. No browser JavaScript/CSP errors;
  live mobile logos visually inspected. Artifact check passes (441 files).

### 2026-09-06: Remove rotating-screen depth artifacts

- The operator's phone screenshot exposed depth fighting between the animated
  display and the cover's solid front cap. Removed the 51 coplanar front-cap
  triangles at load time and replaced them with an adjacent screen and annular
  border at z=1.9 mm. The original CAD asset and rounded shoulder are preserved.
  Camera near/far planes now follow its distance with a 110 mm half-range,
  rather than wasting mobile depth precision on a 0.1 mm near plane. All model
  vertices fit within a 59.414 mm rotation radius. Main/model URLs use
  `20260906-5` for cache invalidation.
- Browser verification at 390 px width and DPR 3 covered 26 rotation steps.
  All 11 sampled front-facing views matched an unobstructed-screen reference
  pixel-for-pixel. Front, angled, and back screenshots were visually inspected;
  the back properly hides the screen. No JavaScript errors. These are desktop
  Chromium mobile-emulation checks; the operator's physical phone was not used.
- Animation, paused pixels, five functions, offscreen pause, reduced motion,
  optional-tour fallback, responsive widths, and desktop/mobile Axe checks
  pass. JavaScript syntax, whitespace, and the repository artifact check pass.
  Full Montserrat `bleep` compiled in the shared environment recorded below:
  147,220 bytes RAM and 2,038,518 bytes flash. No firmware logic changed;
  native tests were not rerun and no hardware was flashed.
- Rebased onto current `origin/main` (no incoming changes), merged from
  `main` with `--no-ff` as `da609b1`, and pushed. Firebase Hosting released
  48 files successfully. Production HTML and versioned renderer match local
  bytes at `https://bleep.hml.tech`; model loading, five functions, mobile
  navigation/width, compatibility, custom 404, and CSP pass without browser
  JavaScript errors. The website correction is deployed; physical-phone
  confirmation remains with the operator.

### 2026-09-06: Fit the website display to its raised cover

- Replaced the undersized, flat 38.2 mm backing with the actual LCD-MIANBAN
  cover exported from `hardware/Bleep Remote.step`. Its 42.1 mm diameter
  matches the shell opening, and its rounded shoulder rises 1.9 mm above the
  case, matching the operator's side photo. Moved the animated display to
  z=1.92 mm above that face. The export script now reproduces this component.
  Main/model JavaScript URLs use `20260906-4` to bypass immutable caches.
- Visually inspected angled, side, and mobile views. Browser checks pass for
  changing screen pixels, paused-frame stability, all five functions,
  offscreen pause/resume, reduced motion, optional-tour failure fallback,
  and widths 320/360/390/768/1440. Desktop/mobile Axe checks and JavaScript
  error capture are clean. JavaScript syntax and repository artifact checks
  pass. No firmware logic changed; native tests were not rerun.
- Full Montserrat `bleep` compiled using the shared main-checkout Python
  environment and PlatformIO core recorded below: 147,220 bytes RAM and
  2,038,518 bytes flash. No hardware was flashed. These checks verify the
  website illustration, not physical-device operation.
- Rebasing `wip/fit-raised-device-display` onto current `main` required no
  changes. Merged with `--no-ff` as `4792449` and pushed to `origin/main`.
  Firebase Hosting successfully released 48 files to `hml-studio`. Live
  checks at `https://bleep.hml.tech` confirm matching HTML, JavaScript, and
  display-cover bytes, a loaded model, all five screen functions, mobile
  navigation without overflow, compatibility routing, custom 404, and CSP.
  No browser JavaScript errors. The merged artifact check passes with 435
  tracked files. Website correction complete; no hardware validation implied.

### 2026-09-06: Website merged and deployed

- On explicit operator approval, committed the complete reviewed redesign as
  `114a317` on `wip/studio-marketing-website`, fetched `origin`, rebased onto
  current `main` (no incoming changes or conflicts), and merged from `main`
  with `--no-ff` as `7c4ea55`. Pushed that merge to `origin/main`.
- The merged revision passes JavaScript syntax and repository artifact checks
  (434 tracked files). Full Montserrat `bleep` compiled with the same shared
  PlatformIO environment/toolchain recorded below: 147,220 bytes RAM and
  2,038,510 bytes flash. No hardware was flashed. GitHub CI run
  `34014332463` was in progress at deployment verification; no CI completion
  claim is made here.
- Deployed from the clean merged website directory using
  `firebase deploy --only hosting --project hml-studio --non-interactive`.
  Firebase Hosting uploaded/finalized/released 47 files successfully to the
  existing `hml-studio` site. The public domain is `https://bleep.hml.tech`;
  the default hosting URL is `https://hml-studio.web.app`.
- Live HTTPS/browser checks on the public domain confirmed that HTML, CSS,
  main/model/tour JavaScript, USB/switch models, a recording screen, and font
  CSS match local bytes. The 3D model loads; all five screen chapters are
  selectable; mobile navigation and width fit pass at 390 pixels. The
  compatibility clean URL and table, custom 404 status/page, and configured
  CSP pass. No browser JavaScript errors; the deployed desktop hero was
  visually inspected. These are production website checks, not hardware
  operating or firmware-release evidence.
- Website merge/deployment request complete. Future work can continue from
  the published design; no manual refresh or stable firmware release was
  requested or performed.

### 2026-09-06: Animated website device screen

- Replaced the model's static display with a 240x240 canvas texture cycling
  through Sequences, Lighting, Cameras, Audio, and Motion. Each chapter uses
  two fresh, unmodified `ui_sim` captures, with short illustrative tap pulses
  where appropriate and crossfades between actual UI states. The screen tour
  is a marketing illustration, not a live controller or physical-device capture.
  The screenshot-to-source mapping is recorded in `website/README.md`.
- Added labeled Pause/Play and Next controls above the model. Autoplay freezes
  offscreen, in hidden tabs, and during WebGL context loss; paused frames stay
  fixed, and unchanged hold frames do not continually re-upload textures.
  Reduced motion disables autoplay while retaining manual function selection.
  Failed optional tour loading leaves the original static model screen usable.
  HTML, styles, main script, model, and tour assets use the `20260906-3` URLs.
- `ui_sim` built and its complete traversal passed; all ten website screenshots
  match the generated files byte-for-byte. Phone preview of the screen and tour
  controls was visually inspected. Full Montserrat `bleep` compiled with the
  previously recorded shared PlatformIO environment/toolchain: 147,220 bytes
  RAM and 2,038,518 bytes flash. JavaScript syntax, whitespace, and repository
  artifact checks pass. No firmware logic changed, so native protocol/state
  tests were not rerun; no flash or production deployment was performed.
- Browser checks under the configured Firebase CSP confirmed changing screen
  pixels, identical pixels while paused, all five manual selections, automatic
  chapter advance, offscreen freeze/resume, reduced-motion behavior, and static
  model fallback when the tour module is blocked. No JavaScript errors or Axe
  WCAG 2 A/AA and 2.1 AA violations on desktop/mobile; 320, 360, 390, 768, and
  1440-pixel widths remain free of horizontal overflow.
- Next safe task: operator review of the automatic screen tour on the existing
  Wi-Fi preview, then continue the requested website review.

### 2026-09-06: Website model USB-C and power-switch correction

- The operator's side photo exposed missing non-printed components in the
  website model. Extracted the actual `TYPE_C_20241129` connector and SS12D00
  power-switch shapes from `hardware/Bleep Remote.step`, preserving nested
  assembly transforms. Added both to the Three.js assembly with a metal socket
  rim, dark socket opening/insulating tongue, and black switch finish. Printed
  shell geometry is unchanged. Raw reference photos remain outside the repo.
- Added `tools/export_website_components.py` for reproducible component exports;
  verified it with temporary Python 3.12, cadquery-ocp 7.8.1.1, and VTK 9.3.1.
  Bumped the HTML script and dynamic model URLs to `20260906-2` so existing
  previews reload the correction. The Wi-Fi preview remains available at
  `http://192.168.1.27:8766/` on the current host network.
- Desktop and 390-pixel mobile side/profile browser renders show both components
  aligned with the enclosure cutouts; visually inspected against the supplied
  photo. The updated model loads without JavaScript errors. Syntax, local
  artifact, and whitespace checks pass. The required full Montserrat `bleep`
  build passes using the same toolchain/environment recorded below: 147,220
  bytes RAM and 2,038,518 bytes flash. No firmware behavior change, native-test
  rerun, flash, or production deployment. Next safe task: operator review of
  the corrected rotating model on mobile.

### 2026-09-06: Marketing website redesign

- Rebuilt the homepage around “Your studio. On cue.” with ivory/orange/olive
  art direction, self-hosted Archivo Black/Manrope/DM Mono fonts, product-led
  copy, a real enclosure model, lights/camera/audio sequence illustration,
  brightness preview, exact-model compatibility links, DIY build CTA, and FAQ.
  Restyled the compatibility ledger and 404 page. Existing support claims and
  the manual source/PDF are unchanged; the outdated hero count was removed.
- The 3D model uses byte-identical copies of the actual enclosure STL exports
  and the existing sequence screenshot. Three.js 0.180.0 and its MIT license
  are vendored; font OFL licenses are included. Drag, keyboard arrows, rotation
  buttons, and reset work. Rendering is demand-driven and pauses offscreen or
  in hidden tabs; missing assets/WebGL, Save-Data, or disabled JavaScript leave
  a static SVG illustration. These are visual previews, not hardware controls.
- Browser verification used installed Chrome through Playwright at 320, 360,
  390, 768, 1024, and 1440 CSS pixels. No horizontal overflow or JavaScript
  errors; keyboard/drag rotation, reset, mobile menu/Escape/link closing,
  sequence play/pause/replay and step selection, brightness keyboard input,
  FAQ, reduced-motion final state, missing-model fallback, and JavaScript-off
  content passed. Firebase CSP was applied during checks; all dependencies
  are served locally. Axe WCAG 2 A/AA and 2.1 AA checks reported zero violations
  on desktop/mobile homepage, desktop/mobile compatibility ledger, and mobile
  404 page. Final desktop/phone homepage, studio illustration, and compatibility
  screenshots were visually inspected. Every local HTML asset/link/fragment and
  unique ID passed; all three website STL copies match the hardware sources.
- Full Montserrat `bleep` compiled successfully using
  `PLATFORMIO_CORE_DIR=/Users/nethunter/dev/bleep/.platformio-core
  /Users/nethunter/dev/bleep/.venv/bin/python -m platformio run -e bleep`.
  This fresh worktree resolved Espressif32 7.0.1, Arduino framework
  3.20017.241212, LVGL 8.4.0, LovyanGFX 1.2.28, NimBLE-Arduino 2.5.1,
  WebSockets 2.7.3, and ArduinoJson 7.4.3. Result: 147,220 bytes static RAM
  (44.9%) and 2,038,518 bytes flash (69.1%). No firmware behavior changed,
  so native protocol/state tests were not rerun. Repository artifact and
  JavaScript syntax checks passed.
- Scoped under the standalone September marketing tranche in the roadmap.
  No flash, merge, push, release, or Firebase deployment was performed. The
  local preview is served at `http://127.0.0.1:8765/`. Next safe task: review
  the design, then follow the repository rebase/merge policy and deploy when
  requested; production behavior remains unverified.
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

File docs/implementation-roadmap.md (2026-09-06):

# Implementation Roadmap

Each phase has an explicit completion gate. Do not begin a dependent phase
until its gate passes or the deviation is recorded in
[Decisions](decisions.md).

## Active sequencing deviation

ADR-013 authorizes a bounded multi-device foundation tranche ahead of the
Phase 1 feasibility spikes. Implemented scope includes the driver catalog,
device manager, versioned device registry, Home/Devices UI, and on-demand Shark
lifecycle. It does not complete Phase 2, Phase 3, or Phase 7: Kconfig validation,
the GATT facade, groups, Portal mode, scenes, generic device modules, and the
physical Shark regression gate remain outstanding.

ADR-014 additionally authorizes a bounded Canon BR-E1 BLE sub-spike against the
EOS R6 Mark III. It adds on-demand pairing and a stateless movie record trigger
to the existing one-active-instance framework. It does not claim recording
state, concurrent Shark/Canon links, CCAPI support, or completion of Phase 1 or
Phase 5.
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

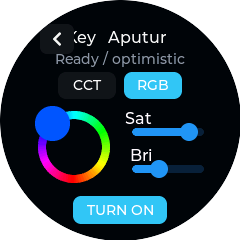
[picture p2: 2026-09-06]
website/assets/screens/light-rgb.png

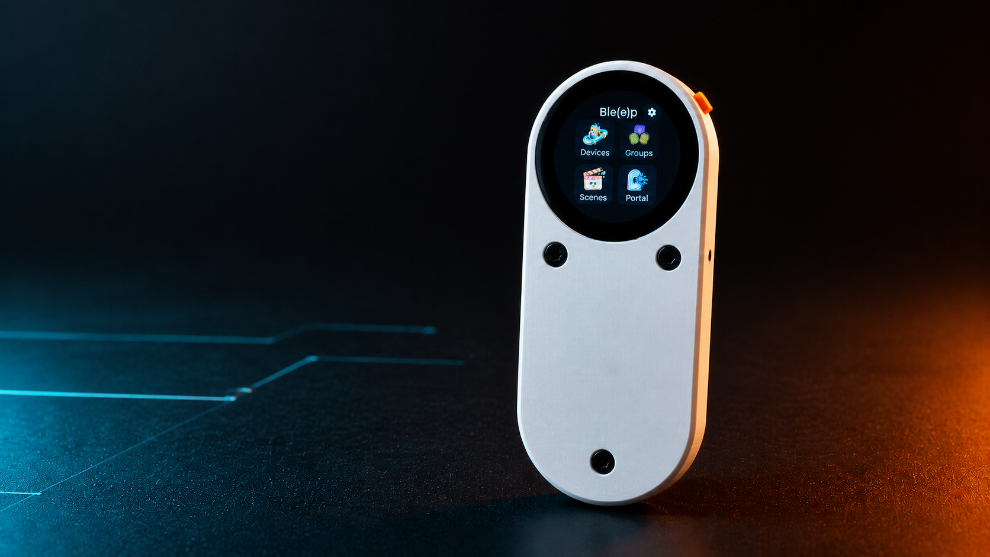
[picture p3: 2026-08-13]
website/assets/hero-product.png

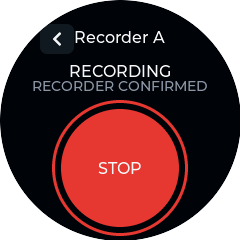
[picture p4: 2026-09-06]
website/assets/screens/audio-recording.png

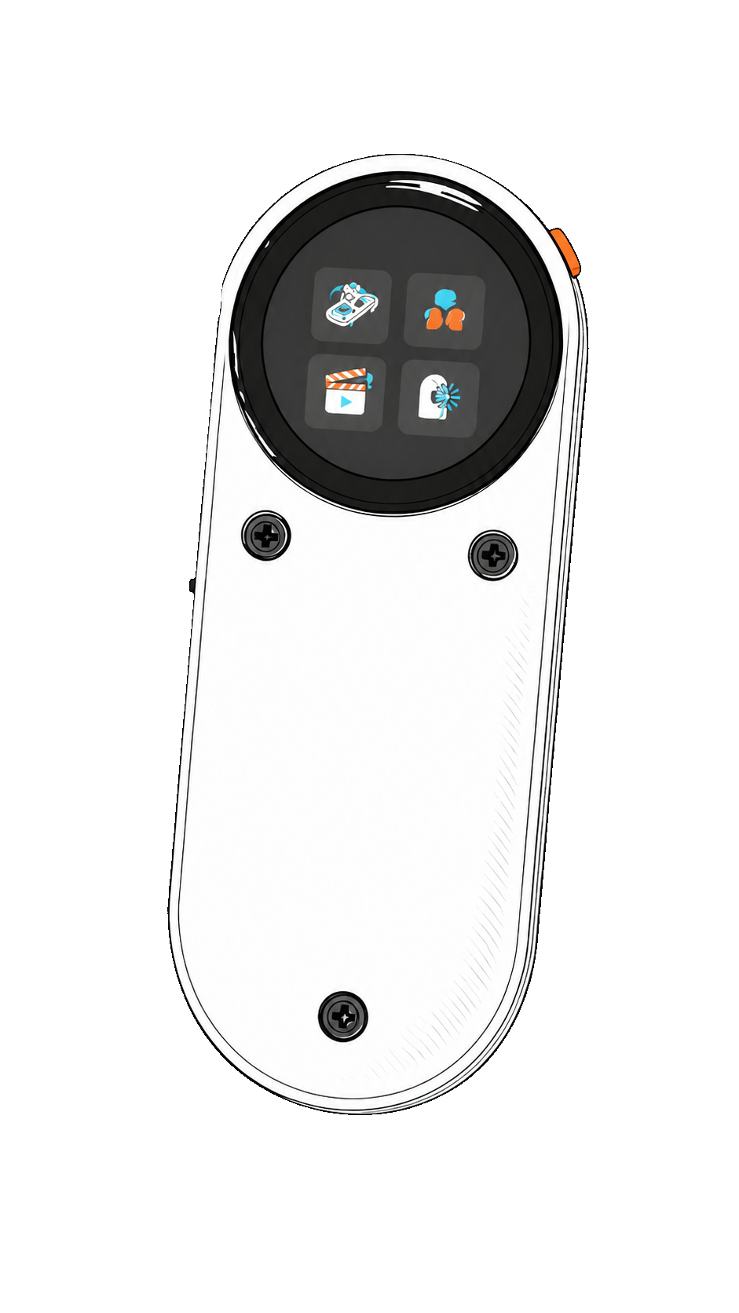
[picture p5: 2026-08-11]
website/assets/controller-front.png

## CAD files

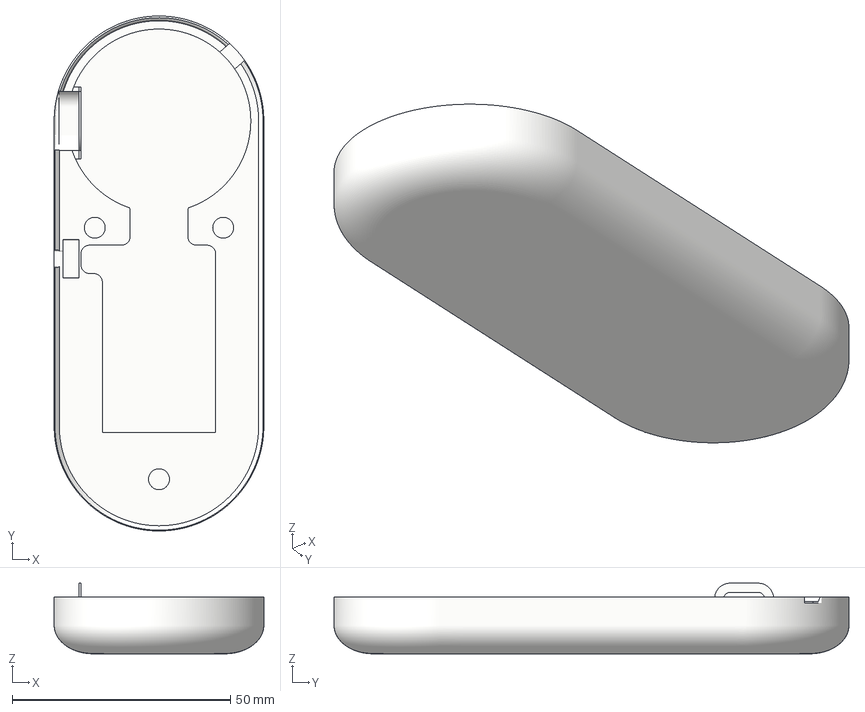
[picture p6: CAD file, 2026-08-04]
hardware/Bleep Remote Bottom.3mf
48.1 x 118.1 x 16.2 mm

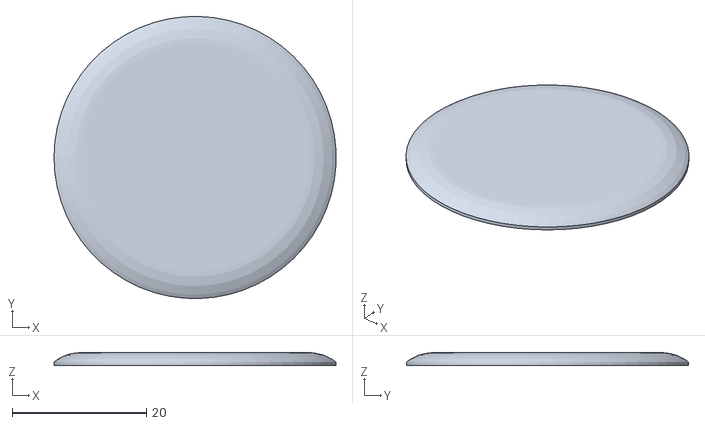
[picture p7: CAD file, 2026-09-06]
website/assets/models/display-cover.stl
42.1 x 42.1 x 1.90

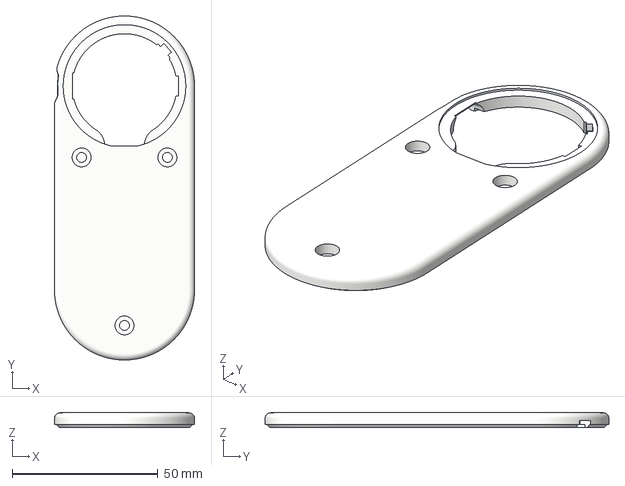
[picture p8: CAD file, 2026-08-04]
hardware/Bleep Remote Top.3mf
48.1 x 118.1 x 5.00 mm

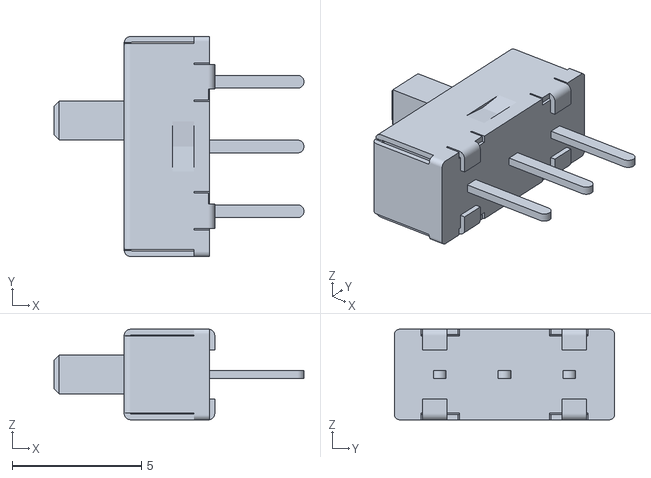
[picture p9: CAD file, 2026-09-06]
website/assets/models/power-switch.stl
9.66 x 8.50 x 3.50

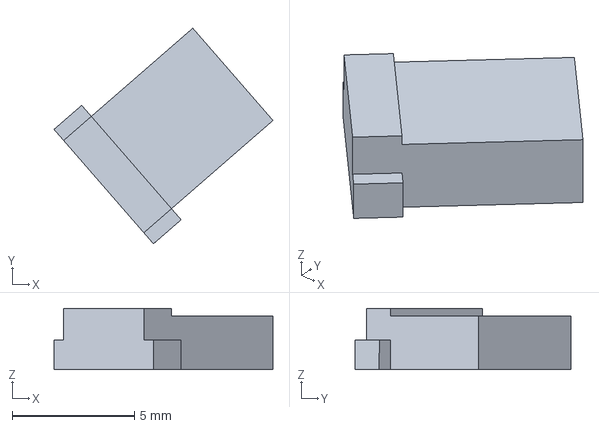
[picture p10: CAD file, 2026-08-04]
hardware/Bleep Remote Button.3mf
8.96 x 8.82 x 2.50 mm

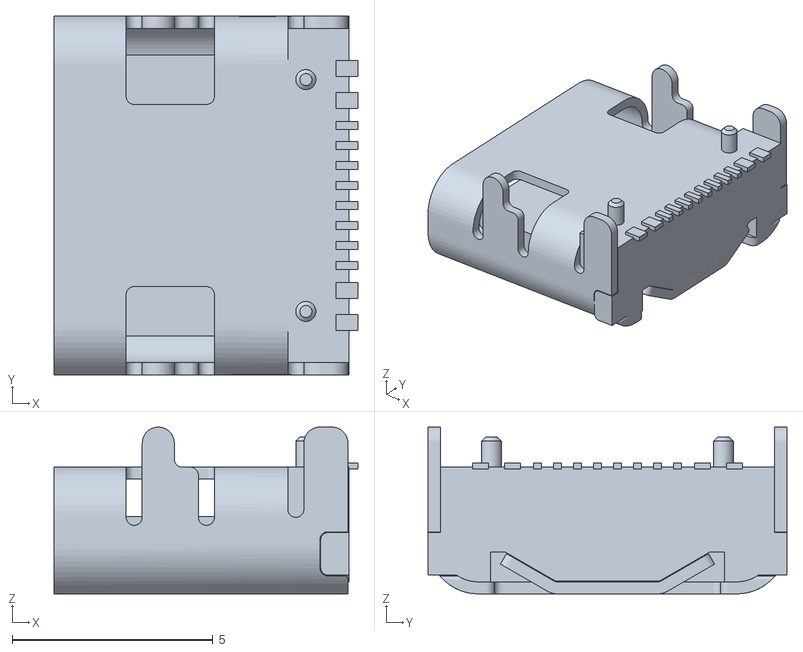
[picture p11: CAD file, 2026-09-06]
website/assets/models/usb-port.stl
7.58 x 8.94 x 4.16

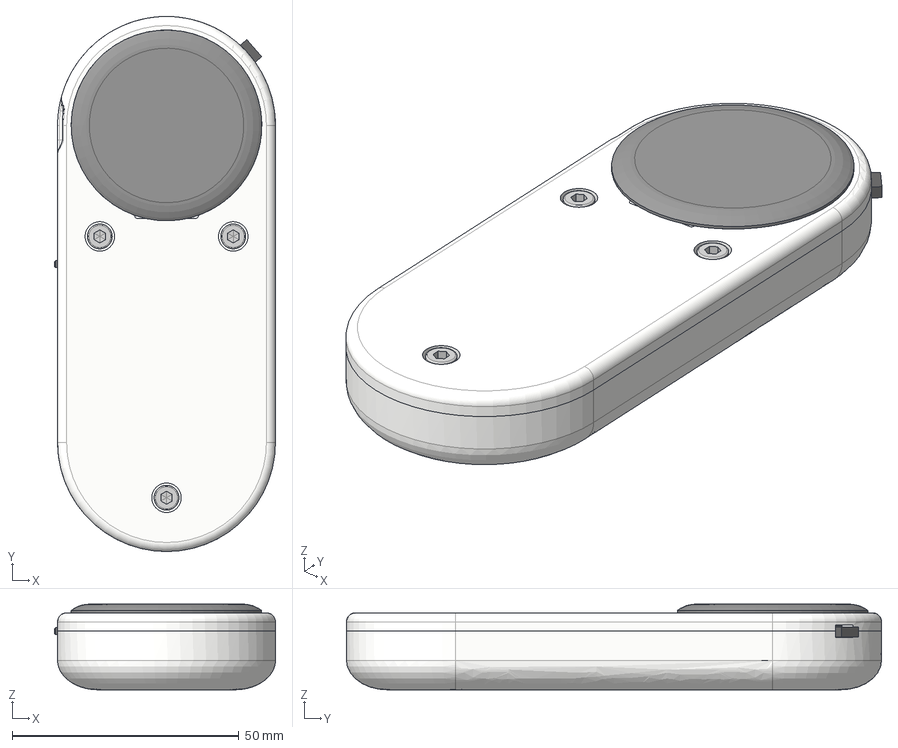
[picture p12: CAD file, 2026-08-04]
hardware/Bleep Remote.step
48.8 x 118.1 x 18.9 mm
BSHCS ASME B18.3.1M - M3x0.5 x 8 Steel Grade 2 Plain x 3

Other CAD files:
website/assets/models/button.stl
website/assets/models/bottom.stl
website/assets/models/top.stl

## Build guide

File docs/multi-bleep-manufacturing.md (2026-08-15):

# Multiple Ble(e)p Manufacturing and Coexistence Plan

This plan makes independently manufactured Ble(e)p panels safe to provision and
operate in the same room. Each panel owns its identity, setup AP, configuration,
and Bluetooth Mesh. Panels may share a studio LAN, but they do not share device
records, mesh keys, scenes, or Home Assistant state.

## Product rules

- The immutable unit identity is derived from the ESP32-C3 factory eFuse MAC;
  it is not a counter compiled into firmware and is not stored in erasable NVS.
- The canonical display form is `BLP-XXXXXXXXXXXX`, using all 48 factory-MAC
  bits. Shortened suffixes are presentation aids only and never database keys.
- The setup SSID is `Bleep-Setup-XXXXX`, using the final five hexadecimal
  characters of the canonical ID. The 20-bit suffix is a presentation aid;
  the full canonical identity remains authoritative.
- The temporary setup AP is open. Its Wi-Fi QR payload uses `T:nopass` and the
  panel does not show a password.
- Every panel generates its own random Bluetooth Mesh Network Key and AppKey
  when its mesh store is missing. Provisioner address `0x0001`, group addresses,
  and node addresses may repeat across panels because the keys define separate
  mesh security domains.
- Every panel continues to request `bleep.local` on the LAN. The numeric DHCP
  address shown on that panel is authoritative when mDNS conflicts or resolves
  to a different Ble(e)p.
- Factory Reset erases runtime configuration and mesh secrets, but cannot
  change the eFuse-derived unit identity or setup SSID. The next mesh use creates
  a new independent network.

## Tranche 1: Stable panel identity

Add one small identity module with host-testable formatting and a target adapter
for `ESP.getEfuseMac()`.

The adapter reverses the six bytes placed into Arduino's little-endian integer
before formatting. Formatters receive the canonical 48-bit MAC value; otherwise
the short suffix would select the shared vendor prefix instead of the unique
device tail.

It provides:

- the full 48-bit hardware identity;
- canonical `BLP-XXXXXXXXXXXX` text;
- the full setup SSID;
- an optional short suffix for round-screen layouts.

Use the canonical identity in About, Portal overview/handoff, diagnostic serial
startup, and manufacturing records. Do not use a new random NVS UUID: cloning or
erasing NVS must never duplicate or change the panel identity. Do not expose
Wi-Fi credentials, BLE bonds, mesh keys, or other secrets beside it.

Acceptance:

- formatting vectors cover leading zeroes and the full 48-bit range;
- two injected hardware IDs produce distinct canonical IDs and setup SSIDs;
- Factory Reset simulation leaves the identity unchanged;
- every firmware profile compiles with one identity implementation.

## Tranche 2: Open, uniquely named setup AP

Replace the fixed password path with an open SoftAP and use the requested short
`Bleep-Setup-XXXXX` suffix. Keep the existing physical Portal entry,
ten-minute teardown, AP-scoped HTTP server, captive DNS, per-session mutation
nonce, no CORS, no-store responses, and frame denial. Limit the AP to one client
when the Arduino API permits it, and show `OPEN NETWORK` on the panel so the
security boundary is honest.

Update both embedded and simulator behavior:

- call the open-network `WiFi.softAP` form;
- return an empty password;
- emit `WIFI:T:nopass;S:Bleep-Setup-XXXXX;;`;
- remove password instructions from the UI and documentation;
- retain the numeric `192.168.4.1` setup URL and LAN handoff flow.

An open AP provides no radio authentication. A nearby person can join while the
Portal is active and can obtain the current page nonce. Physical Portal entry,
the bounded lifetime, visible on-panel status, and one-client capacity reduce
exposure but do not make it equivalent to WPA2. Revisit an on-panel approval for
configuration writes if hostile shared venues become a supported environment.

Acceptance:

- a phone joins without a password or misleading saved credentials;
- QR scanning joins the correct unit when two setup APs are visible;
- captive discovery, manual `192.168.4.1`, Wi-Fi scan/join, LAN handoff, Exit,
  timeout, and heap recovery still work;
- two panels advertise distinct SSIDs simultaneously.

## Tranche 3: Independent mesh creation and recovery

The repository now assembles a missing mesh in temporary state through an
injectable random-fill seam. Both Network Key and AppKey must be filled and the
complete existing-schema blob must save before the live repository publishes
it. RNG and save failures leave the caller unchanged. Production uses the ESP
hardware RNG; keys are never derived from the public unit ID or MAC.

Add validation for:

- independent first boots producing different Network Keys and AppKeys;
- reboot preserving one panel's keys and sequence high-water mark;
- Factory Reset producing a new mesh rather than restoring old keys;
- a save failure preventing provisioning from starting with unsaved keys;
- proxy candidates from another panel's mesh failing authentication and being
  skipped without changing node reachability or state.

Never print raw mesh keys. A manufacturing diagnostic may print a short
cryptographic fingerprint only in an explicitly enabled factory build; normal
firmware should report merely `mesh initialized` and its node count.

## Tranche 4: Same-room device selection

Fresh Aputure Light and Zhiyun adds now use a bounded four-entry picker with
advertised model/name, radio-address suffix, and RSSI. Duplicate observations
retain a stable address-plus-type selection token, and a full list replaces
only its weakest member with a stronger candidate. The operator must choose the
intended fixture before PB-GATT provisioning begins; saved-target reconnect is
still automatic.

Software gates cover stable refresh, weakest replacement, selection rollback,
cancel, and no normal registry commit before protocol-ready. The two-panel,
two-fixture acceptance below remains entirely unverified on hardware.

For ordinary GATT devices, continue persisting the full discovered BLE identity
and address type. For mesh nodes, persist the device UUID, device key, assigned
unicast address, and proxy candidates only in the owning panel's mesh store.
Concurrent panels may scan, but only one may provision a particular
factory-reset fixture; losing the provisioning race must return to the picker
without creating a device record or consuming an address permanently.

Acceptance uses two panels and at least two factory-reset fixtures in one room:

- each panel provisions only the selected fixture;
- cancellation, timeout, and a competing provisioning attempt leave no phantom
  registry entry;
- each panel controls its own mesh member and rejects authenticated state from
  the other mesh;
- reboot and fallback-proxy selection preserve that ownership.

## Tranche 5: LAN and service coexistence

Keep `bleep.local` as requested. Do not silently introduce numbered hostnames.
Because multiple responders requesting the same hostname are inherently
ambiguous, every LAN Portal screen and handoff page must pair the canonical unit
ID with its numeric DHCP URL. The URL is the recovery path and source of truth.

Add the canonical unit ID to the Portal overview JSON and page chrome so an
operator can verify which panel answered. If supported by ESPmDNS, give the
advertised HTTP service instance a unique display name while leaving the host
request as `bleep.local`; this improves browser discovery without changing the
requested alias.

Acceptance:

- two panels join the same WLAN and display different numeric addresses;
- direct IP access reaches the expected unit ID on each panel;
- an mDNS collision never blocks Portal startup or numeric-IP access;
- Portal teardown on either panel does not affect the other.

## Manufacturing flow

1. Flash the same signed firmware image to every panel. Do not compile serials,
   AP names, mesh keys, or credentials into per-unit binaries.
2. Do not clone a configured full-flash image. Erase NVS on every new or
   refurbished panel before first boot; the current `huge_app.csv` NVS region is
   `0x9000` with size `0x5000`.
3. Boot the panel and record the canonical unit ID against the enclosure label,
   PCB revision, and test record. A printed QR may encode only that public unit
   ID, not setup credentials or mesh material.
4. Open Portal and verify the visible setup SSID matches the enclosure record,
   joins without a password, and serves the same unit ID at `192.168.4.1`.
5. Verify display, touch, haptics, battery/charging, Wi-Fi scan/join/teardown,
   BLE scan, and clean reboot. Do not provision production lights during the
   generic factory test.
6. For a refurbished panel, Factory Reset it and separately reset any lights
   that were provisioned to its old mesh. Confirm the panel identity is stable
   and the mesh is newly generated before release.

## Release gate

Do not call multi-panel manufacturing ready until a two-panel soak passes with
both open APs, both LAN Portals, two independent meshes, overlapping BLE scans,
reboots, Portal teardown, and factory reset. Record free heap, largest free
block, scan failures, provisioning failures, and the exact firmware profile.
Build/simulator evidence does not substitute for observing the two physical
panels and their selected fixtures.

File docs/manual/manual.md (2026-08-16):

---
title: "Ble(e)p Owner's Guide"
subtitle: "Set up your gear, control a shoot, and build repeatable studio workflows"
edition: "0.3.6"
date: "16 August 2026"
status: "Development hardware - verify before critical work"
author: "Ble(e)p project"
---

# Welcome

Ble(e)p brings your cameras, lights, audio gear, slider, phone, and Home
Assistant controls together in one small touchscreen remote. You can also save
common actions as sequences and run them in order. Its playful name means
**Bluetooth Links Everything, Eventually, Probably**; the practical version is
**Bluetooth Low Energy Equipment Panel**.

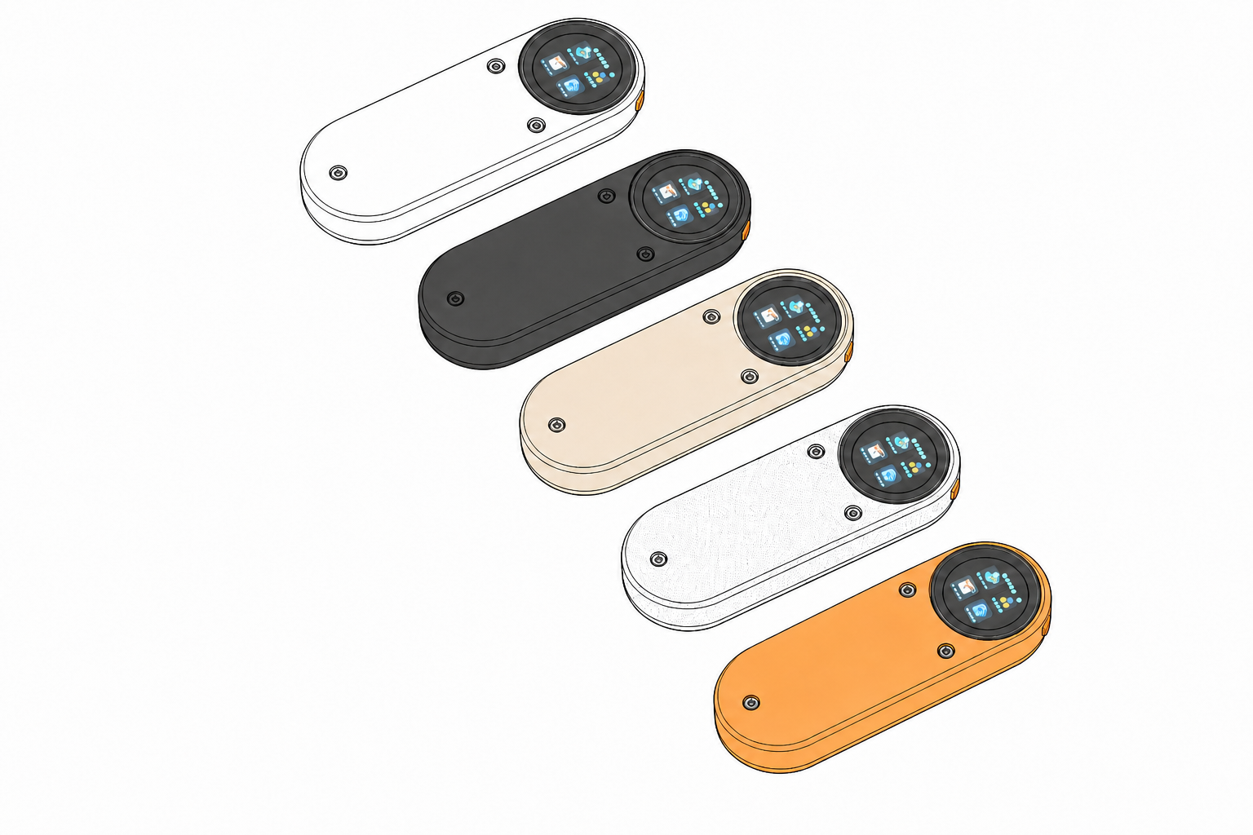
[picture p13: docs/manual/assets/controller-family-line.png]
Five Ble(e)p enclosure finishes. All five use the same circular interface.


> Ble(e)p is still in development - the "Eventually, Probably" part is there for a reason. Before an important shoot, check that your exact model is supported. When Ble(e)p says **Sent**, **Optimistic**, or **Unknown**, look at the equipment itself to make sure the action happened.

## Status words used here

| Label | Meaning |
| --- | --- |
| Supported | Verified on the exact model for the listed functions. |
| Experimental | You can use it, but some situations still need testing. |
| Candidate | It may work, but this exact model has not been tested. |
| Research | It is being investigated and cannot be controlled yet. |
| Later | Not implemented. |

# Quick start

Ble(e)p starts at Home and leaves your equipment disconnected until you open a
device or run a sequence. If you have saved Wi-Fi, it briefly connects about
five seconds after Home appears to check for a safe, signed update. It turns
Wi-Fi off again when the check is finished.

1. Open **Devices**.
2. Open a saved device, or choose **Add device** and follow its pairing steps.
3. Wait for **Ready**.
4. Use the on-screen control or optional Action Button.
5. Check the equipment when the result is **Sent**, **Optimistic**, or **Unknown**.

## Action Button

A short press runs the main action on the current screen. Hold it for about
700 ms to go Back or cancel, or for two seconds to return Home. It is not a
power button.

## Action Button by screen

| Screen | Short press |
| --- | --- |
| Canon - Trigger Mode | Sends the movie trigger, which starts or stops recording without reading the camera's state. |
| Canon Smart, GoPro, DJI Osmo, or Tascam | Starts or stops recording according to the confirmed state. |
| Phone Camera | Sends the shutter command. |
| Insta360 | Runs Record Start while video is idle or Record Stop while recording. It does nothing while the camera reports photo mode or while recording state is unavailable. |
| Aputure, amaran, or Zhiyun light | Toggles the selected light On or Off. |
| Shark Nano II Keypoints | Opens the Run screen. |
| Shark Nano II Run | Runs the displayed Standby, Start, or Stop action. |
| Home Assistant entity | Light or switch: On; input boolean: On/Off toggle; button: Press; scene or script: Activate. Use the on-screen Off control for a Home Assistant light or switch. |
| Scene Run | Starts when Ready; once started or armed, stops the scene. Scene lists, editors, settings, and pickers ignore short presses. |

On supported device screens, a short press also selects **Retry** when it is shown.

# Find your way around

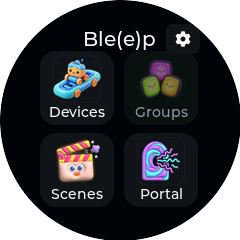
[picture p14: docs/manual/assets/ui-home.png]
Home: Devices, Groups, Scenes, and Portal. The small cog opens Settings.


From Home, choose **Devices** to control equipment, **Scenes** to run saved
workflows, **Portal** to set up Ble(e)p in a browser, or the cog to open
Settings. **Groups** is not available yet.

<!-- pagebreak -->

# Set up your equipment

## Add a physical device

1. Open **Devices**.
2. Scroll to and select **Add device**.
3. Choose the equipment category, then the device family.
4. Put the real device in the exact pairing mode listed in this manual.
5. Wait for Ble(e)p to finish connecting and show **Ready**.

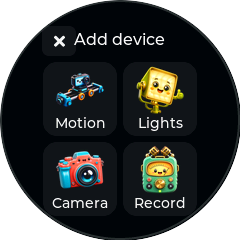
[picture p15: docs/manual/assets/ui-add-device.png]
The Add device screen groups equipment into simple categories.


## Manage a saved device

Open a device's management menu to rename, enable, disable, disconnect, forget/re-pair, or delete it. Disabled devices are hidden from control and sequence lists without being deleted. Remove a device from every sequence before deleting it.

If your installed firmware does not include a saved device type, the entry
stays saved but cannot be opened.

## Connection and state labels

| Label or behavior | Meaning |
| --- | --- |
| Connecting / Preparing | Ble(e)p is connecting and getting the device ready. |
| Ready | You can send a command. Watch the equipment to make sure the action happens. |
| Pending | Ble(e)p is waiting for the device to answer. |
| Confirmed | The device reported the displayed state. |
| Optimistic / Sent | Ble(e)p sent the command but cannot check the physical result. |
| Unknown | Ble(e)p does not have a reliable current state. Check the equipment itself. |
| Unavailable / Failed | The device did not become ready. Check it and choose Retry, or go Back and reopen it. |

# Control cameras

## Canon cameras

Canon Trigger Mode and Smart Phone Mode use separate camera pairings. **Retry** reconnects the camera saved for that entry; choose **Forget** before replacing it with another body.

| Mode | Best for | Controls and feedback |
| --- | --- | --- |
| Trigger Mode | The quickest remote-control setup | One movie trigger starts or stops recording. Ble(e)p cannot read the recording state. |
| Smart Phone Mode | Separate recording controls and camera feedback | Record Start, Record Stop, confirmed recording state, automatic wake, and on-screen power-down on the supported EOS R6 Mark II and Mark III paths. |

### Trigger Mode

1. On the camera open its **Bluetooth remote / BR-E1** pairing menu.
2. On Ble(e)p choose **Canon (Trigger)**.
3. Complete pairing and wait for Ready.
4. Use **Trigger** on screen or press the Action Button.

The same trigger starts and stops recording, so check the camera before pressing it again. Trigger Mode is supported on the **Canon EOS R6 Mark II** and **R6 Mark III**. The original R6 has not been tested.

### Smart Phone Mode

1. On the camera choose **Connect to smartphone > Add a device to connect to**.
2. On Ble(e)p choose **Canon (Smart)**.
3. Complete pairing, then use **Record Start** or **Record Stop**.

Smart Phone Mode supports confirmed recording state and automatic wake on the **EOS R6 Mark II** and **R6 Mark III**. The R6 Mark III also supports on-screen power-down; it is disabled during recording or a pending command. If the camera shows **Connection target not found**, remove its old phone registration and pair again.

## GoPro

Choose **GoPro**, put the camera in wireless pairing mode, and wait for Ready. Recording state and Start/Stop results are camera-confirmed.

Use the top-right power icon to sleep or wake an idle camera. Opening a sleeping GoPro or preparing it for a sequence also wakes it. GoPro documents remote BLE wake for eight hours after sleep; do not rely on it indefinitely.

The **GoPro MAX2** is supported for pairing, confirmed Start/Stop, Sleep, wake, reconnection, and return to Ready. Other GoPro models have not been verified.

## Phone Camera

Ble(e)p appears to the phone as a wireless volume-up remote, which many camera apps can use as a shutter button.

1. Add **Phone Camera** on Ble(e)p.
2. Open Bluetooth settings on the phone and pair with **Ble(e)p Shutter**.
3. Open a camera app that maps Volume Up to shutter.
4. Use the on-screen Shutter action or press the Action Button.

Ble(e)p can remember four phones but cannot confirm that the camera app captured a photo or video. Automatic reconnection and mixed-sequence shutter operation are verified on the **Google Pixel 9**; other combinations remain unverified.

## Insta360

Ble(e)p appears as **Insta360 Remote (Bleep)** and uses the camera's reported state to offer Start or Stop.

1. Open the camera's **GPS Remote** pairing flow.
2. Add **Insta360** on Ble(e)p and wait for the camera to connect to the panel.
3. Wait for the panel to show idle or recording state.
4. Use **Start** while video is idle or **Stop** while recording. No recording action is shown in photo mode or when state is unavailable.
5. On X5, use the on-screen power control to shut down or wake the camera. Wake
   can take up to 60 seconds while Ble(e)p waits for it to reconnect.

The **Insta360 X3**, **X4**, **X4 Air**, and **X5** are supported. On X5,
recording state, Start/Stop, photo-mode feedback, shutdown, and physical wake
have been tested. Waking the camera after leaving and returning to its control
screen still needs more testing. **GO 3** and **GO Ultra** are unverified.

## DJI Osmo

1. Put the camera in its compatible remote-controller pairing flow.
2. Add **DJI Osmo** on Ble(e)p.
3. During first pairing, compare the four-digit code shown on the panel with the camera and approve it.
4. Wait for Ready, then use explicit Record Start/Stop.

Pairing, Start/Stop, and confirmed recording state are verified on the **DJI Osmo Action 5 Pro** and **DJI Osmo 360**. Reconnection, forget/re-pair, and two-camera use need more testing.

## Sony Camera

The Sony entry is for research only. It does not save a camera or provide controls yet.

<!-- pagebreak -->

# Control lights

## Aputure Light

**Aputure Light** adds compatible, factory-reset Aputure and amaran fixtures.
Several compatible lights can share one Bluetooth connection while you still
control each light separately.

1. Factory-reset the light and place it nearby in pairing mode.
2. Choose **Devices > Add device > Lights > Aputure Light**.
3. If several compatible fixtures appear, choose the intended name and address suffix.
4. Leave the light powered while Ble(e)p sets it up. The light may restart;
   wait for **Ready**.
5. Use On/Off, color temperature (CCT), tint, brightness, or RGB color controls as shown.
6. Check the fixture when a change is shown only as sent.

Aputure Light RGB controls. Color changes are sent quickly, but the displayed values are not read back from the light.

The controls adapt to each light. Ble(e)p remembers its CCT and RGB looks, brightness, mode, and power state. Changing tabs applies the stored look only while the light is On.

The **amaran Ray 60c**, **amaran Ace 25c**, **Aputure MC Pro**, and **Aputure MT Pro** are supported. The MT Pro currently appears as MC Pro because the tested fixtures report the same identity. Pano 60c and Pano 120c remain candidates.

## Zhiyun Light: MOLUS X100 and X60RGB

1. Choose **Add device > Lights > Zhiyun Light** once for each fixture.
2. If several compatible fixtures appear, choose the intended name and address suffix.
3. Wait while Ble(e)p identifies the model, connects, and reads its settings.
4. Use power, color temperature, and brightness. The X60RGB also offers hue and saturation controls.

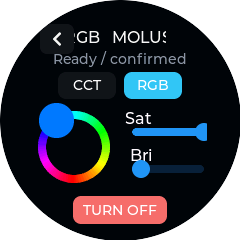
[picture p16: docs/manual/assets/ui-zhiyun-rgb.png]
X60RGB control. The X100 uses the same layout without the RGB tab.


**MOLUS X100:** power, 2700-6500 K color temperature, and brightness. Everyday
control is tested. Reconnecting after a power cycle and using several devices
together need more testing.

**MOLUS X60RGB:** adds hue and saturation. Its color commands have been tested,
but everyday panel use, reconnecting, recovery after a reset, and use with
other lights need more testing.

Sidus Link network import is not supported. Aputure and Zhiyun lights share one connection but remain separate controls. Keep a compatible saved Zhiyun fixture powered whenever a Zhiyun target is active; it acts as the shared gateway.

# Control audio

## Tascam Portacapture X8

Tascam control requires the **AK-BT1** Bluetooth adapter.

1. Install the AK-BT1 in the Portacapture X8.
2. Make the recorder available to its remote-app connection.
3. Choose **Tascam X8** on Ble(e)p and wait for Ready.
4. Use **Record Start** and **Record Stop**. The Action Button performs the appropriate action for the state shown.

Start/Stop, reconnection, and restored recording state are verified. Battery, media status, and other recorder features are not available.

<!-- pagebreak -->

# Control motion

## iFootage Shark Nano II

### Pair

1. Make the Shark Nano II discoverable.
2. On Ble(e)p choose **Devices > Add device > Motion > Shark Nano II**.
3. Wait for the Shark control screen to show **Ready**.

### Functions

- read slider battery, keypoints, run state, and progress;
- save and select keypoints A-H;
- move manually with positioning controls and joystick;
- set speed and hold timing per keypoint;
- choose run direction and looping;
- enter Standby, Start, and Stop the programmed move;
- reconnect when opened.

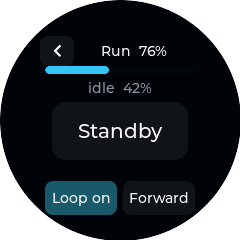
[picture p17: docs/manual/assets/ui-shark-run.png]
Shark Run shows progress, direction, looping, and the primary run-state action.


> Slider movement can damage equipment or injure people. Clear the rail, secure the payload, and test at low speed. Watch the slider until the move is complete.

# Connect Wi-Fi and Home Assistant

Portal lets you configure Ble(e)p from a phone or computer. Device control is
paused while Portal is open.

## First-time Portal setup

1. From Home open **Portal**.
2. Scan the QR code or join the open `Bleep-Setup-XXXXX` network matching the panel suffix.
3. Open the phone's sign-on page, or browse to the numeric setup address on the panel.
4. Manage devices and sequences directly; studio Wi-Fi is not required.
5. To use Home Assistant or configure a hidden network, open **Wi-Fi**, choose a network found during Portal entry or enter its SSID, and supply its password.
6. After Ble(e)p joins, note the web address shown on its screen. Rejoin the normal studio Wi-Fi on your phone or computer.
7. Open the displayed address while Ble(e)p remains on the Portal screen. You can also try `http://bleep.local`.

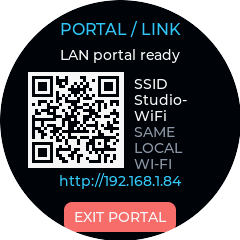
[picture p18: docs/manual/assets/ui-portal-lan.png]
Portal after Ble(e)p joins your normal Wi-Fi. The address works only while the Portal screen is open.


Pair new physical equipment on Ble(e)p itself. Choose **Finish & Exit** in the browser or Exit on the panel when finished.

## Link Home Assistant entities

1. In Portal open **Home Assistant**.
2. Enter your server's local URL and a long-lived access token. Choose **Change stored token** only when replacing one.
3. Select up to four supported Home Assistant entities.
4. Save and exit Portal.
5. Open the saved entity under Devices or add it to a sequence.

Supported entities: lights, switches, input booleans, buttons, scenes, and scripts. Light and switch control is power-only.

Home Assistant can be Ready while an entity still shows **Unknown**. A successful command means Home Assistant accepted it; check the target if you need to confirm that something physically changed.

> The `Bleep-Setup` network is open, and Portal traffic is not encrypted. Use it only in a controlled place. Connect Portal to your normal Wi-Fi only when you trust that network.

# Build repeatable workflows

A **scene**, also called a **sequence**, runs a saved list of actions and waits
across one or more devices.

## Create a scene on the panel

1. Open **Scenes** and select **Add sequence**.
2. Build the **Start** list with **Add step**. Choose a target, action, and any parameters. For a light, **Set look + On** combines its color, brightness, and power-on in one step.
3. Add Wait steps where needed. New waits start at 200 ms; the included Press Record example uses 500 ms.
4. Select the arrow in the header to review the automatic **Stop** list. Ble(e)p
   reverses the Start order and adds a matching Stop action where it can.
5. Optional: choose **Customize Stop** if you want to edit that Stop list
   yourself.
6. Use the checkmark, enter a name, and save.

When you change Start, Ble(e)p updates the automatic Stop preview. New light
looks begin at 5600 K, 50% brightness, neutral tint, and full RGB saturation.
You can preview changes on the selected light. **Set look + On** adds one
**Turn Off** action to Stop.

**Use generated Stop** replaces a custom Stop list after confirmation. You can edit and reorder existing steps; unavailable-device steps can still be deleted from a custom Stop list.

## Run a scene

1. Open the scene. Ble(e)p begins preparing every target.
2. Wait for **Ready**. Every target must be connected and prepared.
3. Select Start or press the Action Button.
4. Watch each step progress. Circular equipment shortcuts open individual controls.
5. Once armed, use Stop or press the Action Button. If Start fails partway through, you can still run Stop for cleanup and then try Start again.

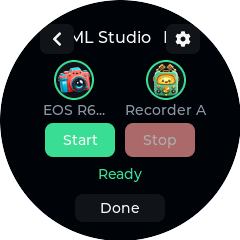
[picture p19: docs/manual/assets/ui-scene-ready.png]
A prepared multi-device sequence. The circular equipment shortcuts show readiness and open individual controls.


Opening scene Settings cancels preparation. It does not interrupt a Start or
Stop already in progress, an armed recording, or a failed Start that may still
need cleanup.

## Action behavior to understand

| Integration | Start/Stop behavior in scenes |
| --- | --- |
| Canon Trigger | Record Trigger; Ble(e)p cannot tell whether recording started or stopped. |
| Canon Smart, DJI, Tascam, GoPro | Separate Start and Stop actions. Confirmation varies by device. |
| Insta360 | Separate Start and Stop actions. Start is available after a fresh video-mode connection; Stop appears after the camera confirms it is recording. |
| Phone Camera | Sends a volume-up command; Ble(e)p cannot see what the camera app did. |
| Lights and Home Assistant switches | Separate On/Off. A light's Set look + On applies its stored CCT or RGB look and turns on that fixture; generated Stop adds one Turn Off. |
| Home Assistant button | Press. |
| Home Assistant scene/script | Activate. |
| Wait | Pause for the chosen number of milliseconds. |

<!-- pagebreak -->

# Personalize, diagnose, and reset

Open the Home cog for version information, Wi-Fi, firmware updates, haptics,
diagnostics, and Factory Reset.

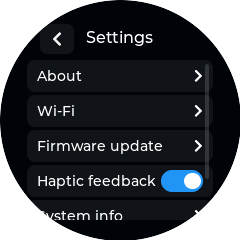
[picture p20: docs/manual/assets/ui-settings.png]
Settings includes About, Wi-Fi, Firmware update, haptics, system information, and Factory Reset.


## Connect Wi-Fi from the panel

Opening **Settings > Wi-Fi** does not connect by itself. To join or replace a
visible network:

1. Choose **Scan networks** or **Replace network**.
2. If Ble(e)p is keeping equipment connected, confirm **Disconnect & scan**.
   An active command must finish first.
3. Select the network. Enter its password on the masked round keyboard when
   required.
4. Wait for Ble(e)p to connect. It saves the network only after the connection
   succeeds, then turns Wi-Fi off again.

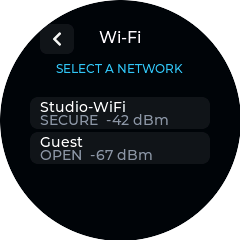
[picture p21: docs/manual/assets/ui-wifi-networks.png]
Visible networks are listed by signal strength after an explicit scan.


Use Portal for a hidden SSID, easier phone-based text entry, or Home Assistant
setup. **Forget network** removes only the saved SSID and password; it preserves
Home Assistant settings.

## Install a firmware update

Stable releases are selected by default. You can opt into Development builds,
but they may not have been tested as thoroughly on real hardware.

With saved Wi-Fi, Ble(e)p checks your selected Stable or Development channel
about five seconds after Home appears. If you are already using a device,
scene, command, or Portal, it waits until Ble(e)p is idle. You can also choose
**Settings > Firmware update > Check now**. A check downloads only the update
details, not the firmware itself, and turns Wi-Fi off when finished.

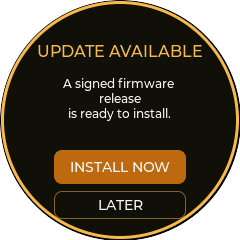
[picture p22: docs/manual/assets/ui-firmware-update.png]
A newer signed release uses a round amber prompt with equal Install now and Later actions.


To install:

1. Keep Ble(e)p connected to reliable USB power.
2. Choose **Install now**, review the reboot warning, and confirm.
3. Leave power connected while the amber **Preparing update** screen appears
   and Ble(e)p installs the update. It will restart more than once.
4. Wait for **Update successful**, then choose **Restart**. Ble(e)p returns to
   Home after validating the new firmware.

**Later** dismisses that release's popup but leaves it available on the
Firmware Update page. A newer release may prompt again. If preparation fails,
return to the Firmware Update page and choose **Retry update**. Do not remove
power during recovery or installation.

## Enter Recovery mode

On **Settings > Firmware update**, hold **Recovery mode** continuously for two
seconds. Recovery can retry the requested update, install the latest stable
release, start the installed firmware when it is still usable, or run Factory
Reset. Use it after an interrupted update or when Ble(e)p cannot start normally.

## Factory Reset

Factory Reset requires a continuous three-second hold and working saved Wi-Fi.
Ble(e)p first downloads and checks the latest stable firmware. It erases your
saved devices and pairings, scenes, Wi-Fi, Home Assistant links, light setup,
and preferences only after that download is ready. If the network or download
fails, your saved setup is left untouched.

# Device compatibility matrix

Compatibility is intentionally exact. A similar model is not automatically supported.

| Device or service | Status | Available functions | Key limitation or open gate |
| --- | --- | --- | --- |
| Canon EOS R6 Mark II / III - Trigger | Supported | Movie trigger and reconnect | Recording state is unavailable. |
| Canon EOS R6 - Trigger | Candidate | Intended movie trigger | Exact model untested. |
| Canon EOS R6 Mark III - Smart | Supported | Start/Stop, confirmation, wake, power-down | No additional camera controls. |
| Canon EOS R6 Mark II - Smart | Supported | Start/Stop and confirmation | No additional camera controls. |
| GoPro MAX2 | Supported | Start/Stop, confirmation, Sleep/wake | Use alongside several other devices needs more testing. |
| Other Open GoPro models | Candidate | Intended Start/Stop and state | No model-specific result. |
| Google Pixel 9 | Experimental | Volume-up shutter and reconnect | Capture cannot be confirmed. |
| Other phones | Candidate | Volume-up shutter | Phone and camera-app combinations untested. |
| Insta360 X3 / X4 / X4 Air | Supported | GPS Remote camera control | Reconnect, power, and use alongside other devices need more testing. |
| Insta360 X5 | Supported | Start/Stop, shutdown, wake | Wake after leaving and reopening its screen needs more testing. |
| Insta360 GO 3 | Candidate | Intended GPS Remote control | Exact model untested. |
| Insta360 GO Ultra | Research | None | GPS Remote compatibility unknown. |
| DJI Osmo Action 5 Pro / Osmo 360 | Supported | Four-digit pairing, Start/Stop, confirmation | Reconnect and two-camera use need testing. |
| Sony RMT-P1BT cameras | Research | None | Pairing and control unavailable. |
| Tascam Portacapture X8 + AK-BT1 | Supported | Start/Stop and confirmed state | No battery or media status. |
| Home Assistant local entities | Experimental | Up to four supported entities | Power-only lights and switches; no cloud sign-in. |
| amaran Ray 60c | Supported | Aputure Light power and looks | Long sessions and recovery after failures need more testing. |
| amaran Ace 25c / Aputure MC Pro | Supported | Setup, identity, RGB power and looks | Confirmation, recovery, and long sessions need more testing. |
| Aputure MT Pro | Supported | Setup, power, and looks | Currently labelled MC Pro. |
| amaran Pano 60c / Pano 120c | Candidate | Intended Aputure Light controls | Exact models untested. |
| Zhiyun MOLUS X100 | Experimental | Power, CCT, brightness, saved state | Cold reconnect, multi-light use, and recovery need testing. |
| Zhiyun MOLUS X60RGB | Experimental | Power, CCT, RGB, saved state | Panel, reconnect, recovery, and mixed-light use need testing. |
| Deity PR4 | Later | None | Not implemented. |
| iFootage Shark Nano II | Supported | Pair/reconnect, battery, keypoints, movement, run | Secure the payload and watch every move. |

# Troubleshooting

## A device does not appear

- Confirm the target is in the correct pairing menu, not merely powered on.
- For a first-time light, select the intended name and address suffix when several appear.
- Re-enter the target's pairing mode and retry.
- If the device was paired to another phone or remote, remove the old registration or use Forget/re-pair as appropriate.
- For Canon, do not interchange BR-E1 and smartphone pairings.

## A saved device will not reconnect

- Open the saved device to begin reconnecting.
- Confirm the target is awake and still trusts Ble(e)p.
- Use **Manage > Disconnect**, then reopen.
- Ble(e)p can keep four equipment connections ready at once. Disconnect something you are not using, then try again.
- For a light, keep a compatible fixture powered and advertising, then use Retry.

## A command says Sent, Optimistic, or Unknown

Some equipment cannot tell Ble(e)p what happened. Check the camera display,
recorder, light output, phone app, or slider directly. If you do not know the
real state, do not press a toggle again without checking first.

## A scene cannot reach Ready

- Open the failed target and resolve its pairing or connection problem.
- Confirm every device used by the scene is enabled and available in the installed version.
- Check the four-connection limit. Compatible Aputure and Zhiyun lights share one connection; Home Assistant does not use one of the four.
- If the scene contains a Zhiyun light, keep a compatible saved Zhiyun fixture powered so it can provide the shared Aputure/Zhiyun gateway.
- If a multi-light scene fails, open the failed fixture, retry it, and confirm its physical output.
- Use Retry when shown. Opening scene Settings cancels preparation.

## Portal does not open

- Keep Ble(e)p on the Portal screen. Leaving it closes Portal.
- During first setup, join the `Bleep-Setup-XXXXX` network matching the panel suffix. If the sign-on page does not appear, use the numeric setup address.
- On the setup network, `http://192.168.4.1` opens Portal directly. If the
  phone says the network has no internet, stay connected and open that address.
- After Ble(e)p joins the studio network, reconnect your phone or computer to that network and use the address shown on the panel.
- If `bleep.local` does not work, use the numeric address shown on Ble(e)p.

## Wi-Fi scan fails or finds no networks

- Return to Home, move closer to the access point, and scan again from
  **Settings > Wi-Fi**.
- For a hidden network, open Portal and enter the SSID and password yourself.

## A firmware update does not appear or complete

- Confirm **Settings > Wi-Fi** shows the intended saved network, and confirm the
  Firmware Update page is using the intended Stable or Development channel.
- Finish active device commands, leave Portal, and return Home before checking
  again. Ble(e)p never disconnects active equipment silently for an update.
- Keep USB power connected. If **Preparing update** returns to the Firmware
  Update page, choose **Retry update**. After an interrupted installation,
  enter Recovery mode and retry the requested update.

# Work safely

- Secure cameras, sliders, lights, cables, and recorders before sending commands.
- Watch the equipment itself for movement, recording, power, and light changes
  whenever Ble(e)p says **Optimistic** or **Unknown**.
- Use Portal only in a controlled place, and connect it only to Wi-Fi you trust;
  Portal traffic is not encrypted.
- Treat saved Wi-Fi details, Home Assistant tokens, pairing information, and device identities as private. Factory Reset removes them from Ble(e)p.
- Keep reliable USB power connected throughout firmware preparation, recovery,
  installation, and the final success confirmation.
- This project is independent and is not endorsed by iFootage, Canon, GoPro, Insta360, DJI, Sony, Tascam, Aputure, amaran, Zhiyun, Deity, Espressif, Elecrow, or Home Assistant.

<!-- pagebreak -->

# Advanced: developers and builders

This section is for building, repairing, or developing Ble(e)p. Opening the enclosure or modifying the battery lead requires electronics experience.

## Platform and operating limits

The reference build uses the **Elecrow CrowPanel ESP32 1.28-inch round display, model DIS12824D**: an ESP32-C3, 240 x 240 GC9A01 LCD, CST816D capacitive touch controller, PI4IOE5V6408 I/O expander, and onboard vibration motor. The case adds an optional Action Button and an SS12D00G slide switch for power.

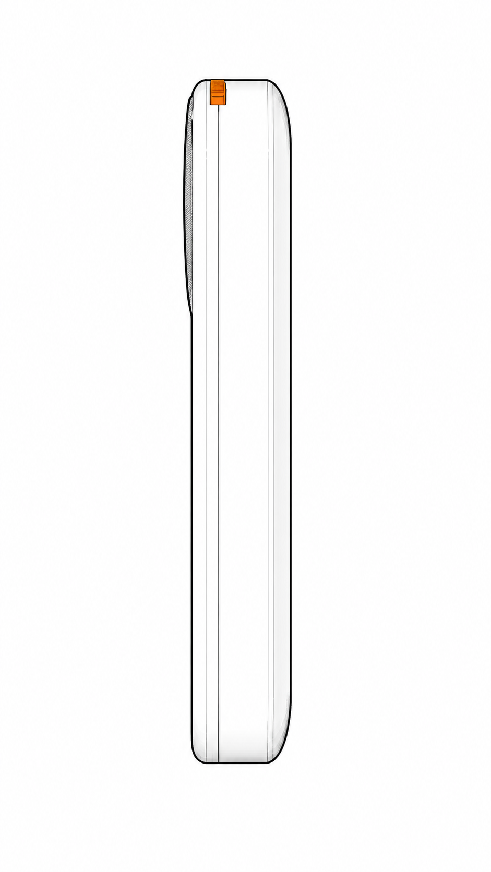
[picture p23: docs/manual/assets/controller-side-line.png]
Side profile of the reference enclosure. The orange actuator belongs to this build; placement can differ on community enclosures.


- The screen and backlight remain on continuously in the current firmware.
- The board does not sense its own battery voltage. A battery value on the Shark screen belongs to the slider.
- The registry holds 24 device records and up to 16 BLE bonds.
- Four physical BLE transport groups can remain connected. Compatible Aputure and Zhiyun fixtures share one group.

| Function | GPIO or address |
| --- | --- |
| LCD DC / CS / SCK / MOSI | GPIO 2 / 10 / 6 / 7 |
| I2C SDA / SCL | GPIO 4 / 5 |
| Touch interrupt | GPIO 0 |
| Action Button | GPIO 1, active low |
| Vibration motor | I/O expander P0 |
| I/O expander | I2C `0x43` |
| CST816D touch | I2C `0x15` |
| BM8563 RTC | I2C `0x51` |

## Parts and tools

The maintained bill of materials and source links live in `hardware/README.md`. The reference assembly uses:

| Item | Specification |
| --- | --- |
| Display/controller | Elecrow CrowPanel ESP32 1.28-inch, DIS12824D |
| Power switch | SS12D00G SPDT, 5 mm actuator |
| Battery | JLJLUP 3.7 V 1100 mAh 1S LiPo with protection board, 25 x 10 x 42 mm, and JST 1.25 plug; replace the plug during assembly |
| Battery pigtail | JST SH 1.0 mm, 2 pin |
| Threaded hardware | 3 x M3 x 6 x 5 mm heat-set inserts; 3 x M3 x 8 mm socket-head screws |
| Replacement battery-path diode | 1N5819 Schottky, DO-41; replaces the original CrowPanel D1 |

You also need a multimeter, temperature-controlled soldering iron, heat-set insertion tip, soldering supplies, heat-shrink or suitable insulation, and ordinary 3D-print cleanup tools. Battery packs and community kits vary; confirm every electrical rating rather than assuming a linked or visually similar part is correct.

## Print the enclosure

The `hardware/` directory contains top, bottom, and button parts as 3MF and STL files. Use 3MF where supported. `Bleep Remote.step` is the editable assembly model for enclosure changes.

The original print used a Bambu Lab X1 Carbon, 0.4 mm nozzle, SuperTack plate, Bambu PLA Matte, and the stock `0.12mm High Quality @BBL X1C` preset. Enable supports and select **Normal (Auto)** rather than **Tree (Auto)**; otherwise keep the selected process and filament defaults. Put each part on its own plate and print the button first as a quick fit test.

## Assemble the enclosure

1. Clean the prints and dry-fit the display, slide switch, action-button actuator, battery, and both shells before soldering. The CrowPanel fits directly into the top shell without adhesive.
2. Confirm that the printed Action Button moves freely and transfers a case press to the board control. It is an action/navigation button, not a power button.
3. With a temperature-controlled iron and suitable tip, install the three heat-set inserts square to their bosses. Stop when each is flush; excessive heat or force can deform the shell.
4. Let the plastic cool completely. Do not install or wire the battery while the shell is still warm.
5. Complete and verify the switched battery lead as described below.
6. Remove the original CrowPanel D1 and install the external 1N5819 replacement as described below.
7. Route and insulate wiring so it cannot touch the PCB, antenna, USB connector, screw bosses, or moving switch parts. Fit the CrowPanel and battery without pinching a conductor.
8. Join the shells with three M3 x 8 mm screws. Tighten only until secure; overtightening can strip an insert or distort the print.
9. Before final use, check switch operation, button travel, charging behavior, and boot from battery with the enclosure attended.

## Wire the battery and power switch

The reference battery's original plug is incompatible with the CrowPanel socket. Replace it with a correctly wired JST SH 1.0 mm two-pin pigtail and put the slide switch in series with **one** battery lead:

```text
Battery lead A -- switch COM -- selected throw -- connector lead A
Battery lead B ------------------------------- connector lead B
```

Use only the common terminal and one throw; insulate the unused throw. Identify the switch terminals with a multimeter, not by physical orientation. Verify continuity in both positions, then verify the finished connector's voltage and polarity against the CrowPanel markings and documentation **before** plugging it in.

Battery leads remain live during connector replacement. Cut and splice only one conductor at a time, insulate that joint before exposing the other conductor, and cover finished joints with heat-shrink. Never solder directly to a cell or its tabs. Do not charge, use, or enclose a damaged or swollen lithium battery, and prevent bare terminals from touching the board or each other.

## Replace the CrowPanel D1 battery path

The DIS12824D V1.0 schematic identifies D1 as a `B5819WT` Schottky diode in SOD-523, in series from `VBAT` to the board load. The reference assembly removes the original D1 and replaces it with a physically larger, through-hole 1N5819. **Never leave both diodes connected in parallel, and never substitute a wire.**

Disconnect USB and the battery. Use a multimeter to identify the actual VBAT and board-load nets rather than trusting wire colors:

```text
battery-positive / VBAT -- unbanded [ 1N5819 ] banded -- board-load side
                           anode                 cathode
```

1. With all power removed, confirm the board-load side is not shorted to ground. If resistance stays near zero, stop and find the fault before continuing.
2. Confirm and mark the original D1 end connected to battery positive as the VBAT side and the opposite end as the board-load side.
3. Carefully desolder and remove the original D1. Heat each joint only as long as needed, lift the component without prying, then clean and inspect both pads. Stop if either pad or trace lifts.
4. Connect the external 1N5819's unbanded anode to VBAT. The verified battery-positive connector joint may be mechanically safer than loading the tiny former D1 pad.
5. Connect the banded cathode to the board-load side with short, flexible insulated wire. Do not let the DO-41 body pull on the former D1 pad.
6. Confirm that the removed D1 is no longer electrically connected. Insulate all exposed conductors, strain-relieve the replacement diode, and keep it clear of the antenna, USB connector, fasteners, and exposed pads.
7. Inspect for bridges, then make the first test from battery only. Disconnect immediately if the diode heats quickly, board voltage stays near zero, or operation is abnormal.

A build using this arrangement measured 4.0 V at the battery and 3.7 V on the load side while running. Before closing the case, exercise representative BLE scanning and connected operation while monitoring diode temperature and voltage drop. Disconnect immediately if the diode heats quickly or the voltage becomes unstable. The longer battery-endurance gate remains open.

## Build, test, and flash firmware

Use a compatible Python 3 installation and PlatformIO from the repository root. The full Montserrat profile is `bleep`:

```sh
python3 -m venv .venv
.venv/bin/python -m pip install -U pip platformio
PLATFORMIO_CORE_DIR="$PWD/.platformio-core" ./.venv/bin/python -m platformio test -e native
PLATFORMIO_CORE_DIR="$PWD/.platformio-core" ./.venv/bin/python -m platformio run -e bleep
PLATFORMIO_CORE_DIR="$PWD/.platformio-core" ./.venv/bin/python -m platformio run -e bleep -t upload
```

The configured upload port is `/dev/cu.usbserial-211240`; do not guess another
port if it is absent. A normal PlatformIO upload writes main at `0x120000` and
assumes the recovery partition layout already exists.

Build success is not proof of panel behavior, peripheral compatibility, browser behavior, tactile feel, or endurance. Record those separately and retain exact-model confidence labels.

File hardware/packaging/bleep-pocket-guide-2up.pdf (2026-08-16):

POCKET GUIDE

# Studio control, without the

scramble.

A compact guide to setup, control, scenes, troubleshooting, and safe operation.

Development hardware
Verify your exact equipment before critical or unrepeatable work.

### 01 A / POCKET GUIDE

01 / START HERE
Update before setup.

On first use, install the latest stable firmware before pairing equipment.

1. Connect USB power and switch Ble(e)p on.
2. Open the Home cog, then Wi-Fi. Scan, choose a trusted network, and enter its password. Use Portal for a hidden network.

### 3. Return to Settings > Firmware update and

choose Check now.
4. Choose Install now and confirm.

### 5. Keep USB power connected through

Preparing update and Recovery. Do not switch off.

### 6. At Update successful, press Restart. Wait

for Home, then continue with Devices.

### 02 A / POCKET GUIDE

02 / DEVICES
Pair and manage gear.

Choose Devices > Add device, then select the equipment category and family. Follow the pairing instructions for that exact device.

A saved device can be renamed, enabled, disabled, disconnected, forgotten/re-paired, or deleted from its management menu.

Opening a saved device begins its connection. Ble(e)p can keep up to four physical equipment links ready at once. Compatible Aputure and Zhiyun lights share one link.

### 03 A / POCKET GUIDE

03 / CAMERAS

# Check what the camera

confirms.

Canon Trigger sends one movie toggle; recording state is unknown. Canon Smart, GoPro, and DJI Osmo offer explicit Start/Stop with device feedback on supported paths.

Insta360 offers Start or Stop only when its reported mode and state allow it. Phone Camera sends Volume Up as a shutter and cannot confirm capture.

When Ble(e)p says Sent, Optimistic, or Unknown, look at the camera before sending another toggle.

### 04 A / POCKET GUIDE

04 / LIGHTS + AUDIO + MOTION

# Control the rest of the

studio.

Aputure Light controls supported Aputure/amaran fixtures. Zhiyun Light controls MOLUS X100 and X60RGB paths. Available controls can include power, brightness, CCT, tint, and RGB looks.

Tascam X8 requires the AK-BT1 adapter and provides confirmed Record Start/Stop.

Shark Nano II supports keypoints, manual positioning, speed, timing, looping, Standby, Start, and Stop. Clear the rail and watch every move.

### 05 A / POCKET GUIDE

05 / SCENES

# Build repeatable

workflows.

Open Scenes > Add sequence. Add Start actions and Wait steps in order. New waits begin at 200 ms; tune them for your gear.

Review the generated Stop list, or choose Customize Stop for an independent list. Save, open the scene, and wait until every target is Ready.

Press Start, watch step progress, then use Stop for cleanup. If Start fails partway through, Stop remains available.

UNFOLD FULLY - THEN TURN OVER

### 06 A / POCKET GUIDE

POCKET GUIDE

# Studio control, without the

scramble.

A compact guide to setup, control, scenes, troubleshooting, and safe operation.

Development hardware
Verify your exact equipment before critical or unrepeatable work.

### 01 B / POCKET GUIDE

01 / START HERE
Update before setup.

On first use, install the latest stable firmware before pairing equipment.

1. Connect USB power and switch Ble(e)p on.
2. Open the Home cog, then Wi-Fi. Scan, choose a trusted network, and enter its password. Use Portal for a hidden network.

### 3. Return to Settings > Firmware update and

choose Check now.
4. Choose Install now and confirm.

### 5. Keep USB power connected through

Preparing update and Recovery. Do not switch off.

### 6. At Update successful, press Restart. Wait

for Home, then continue with Devices.

### 02 B / POCKET GUIDE

02 / DEVICES
Pair and manage gear.

Choose Devices > Add device, then select the equipment category and family. Follow the pairing instructions for that exact device.

A saved device can be renamed, enabled, disabled, disconnected, forgotten/re-paired, or deleted from its management menu.

Opening a saved device begins its connection. Ble(e)p can keep up to four physical equipment links ready at once. Compatible Aputure and Zhiyun lights share one link.

### 03 B / POCKET GUIDE

03 / CAMERAS

# Check what the camera

confirms.

Canon Trigger sends one movie toggle; recording state is unknown. Canon Smart, GoPro, and DJI Osmo offer explicit Start/Stop with device feedback on supported paths.

Insta360 offers Start or Stop only when its reported mode and state allow it. Phone Camera sends Volume Up as a shutter and cannot confirm capture.

When Ble(e)p says Sent, Optimistic, or Unknown, look at the camera before sending another toggle.

### 04 B / POCKET GUIDE

04 / LIGHTS + AUDIO + MOTION

# Control the rest of the

studio.

Aputure Light controls supported Aputure/amaran fixtures. Zhiyun Light controls MOLUS X100 and X60RGB paths. Available controls can include power, brightness, CCT, tint, and RGB looks.

Tascam X8 requires the AK-BT1 adapter and provides confirmed Record Start/Stop.

Shark Nano II supports keypoints, manual positioning, speed, timing, looping, Standby, Start, and Stop. Clear the rail and watch every move.

### 05 B / POCKET GUIDE

05 / SCENES

# Build repeatable

workflows.

Open Scenes > Add sequence. Add Start actions and Wait steps in order. New waits begin at 200 ms; tune them for your gear.

Review the generated Stop list, or choose Customize Stop for an independent list. Save, open the scene, and wait until every target is Ready.

Press Start, watch step progress, then use Stop for cleanup. If Start fails partway through, Stop remains available.

UNFOLD FULLY - THEN TURN OVER

### 06 B / POCKET GUIDE

### 50 mm - PRINT AT ACTUAL SIZE

FULL OWNER'S GUIDE

# Details change. Scan

before the shoot.

Exact-model compatibility matters. A similar camera, light, recorder, phone, or motion device is not automatically supported.

The complete guide includes current setup procedures, supported models, limitations, troubleshooting, safety, and developer information.

BLEEP.HML.TECH / OWNER'S GUIDE

### 12 A / POCKET GUIDE

10 / SETTINGS + RESET

# Know what Factory Reset

removes.

Open the Home cog for version information, Wi-Fi, signed firmware updates, haptics, diagnostics, and Factory Reset.

Factory Reset requires a three-second hold. It removes saved devices and pairings, scenes, Wi-Fi, Home Assistant links, light setup, and preferences, then restarts Ble(e)p. It does not remove the installed software.

Use the full owner's guide for exact-model compatibility, pairing steps, limitations, assembly, and repair information.

### 11 A / POCKET GUIDE

09 / WORK SAFELY
Observe the real studio.

Secure cameras, sliders, lights, cables, and recorders before sending commands. Keep people and loose objects clear of moving equipment.

Watch for movement, recording, power, and light-output confirmation whenever state is optimistic or unknown.

Do not charge, use, ship, or enclose a hot, damaged, or swollen battery. Power Ble(e)p off before packing it.

Treat Wi-Fi details, tokens, pairing data, and device identities as private.

### 10 A / POCKET GUIDE

08 / TROUBLESHOOT
Recover methodically.

Device missing: use the exact pairing menu, remove an old phone/remote registration if needed, and retry.

Will not reconnect: wake the device, choose Manage > Disconnect, then reopen it. Free a physical link if four are active.

Scene not Ready: open the failed target, confirm it is enabled, and resolve its connection first.

Wi-Fi scan fails: return Home and retry near the access point. Use Portal to type a hidden network name.

Portal missing: stay on the Portal screen and use the numeric address shown if bleep.local does not work.

### 09 A / POCKET GUIDE

07 / READ THE STATUS

# Ready is not the same as

done.

Connecting / Preparing
The link is being established.

Ready
A command can be sent; physical success is not promised.

Pending
Ble(e)p is waiting for an answer.

Confirmed
The device reported the displayed state.

Sent / Optimistic / Unknown
Check the real equipment.

Unavailable / Failed
Resolve the device and choose Retry.

### 08 A / POCKET GUIDE

06 / PORTAL + HOME ASSISTANT
Configure in a browser.

Open Portal. Join the matching Bleep-Setup-XXXXX network or scan the panel QR, then use the address shown.

Portal pauses normal device control and exists only while its screen is open. Use Finish & Exit when done.

For Home Assistant, add trusted studio Wi-Fi, enter the local server URL and a long-lived token, then select up to four supported entities. The setup AP is open and Portal traffic is not encrypted.

### 07 A / POCKET GUIDE

FULL OWNER'S GUIDE

# Details change. Scan

before the shoot.

Exact-model compatibility matters. A similar camera, light, recorder, phone, or motion device is not automatically supported.

The complete guide includes current setup procedures, supported models, limitations, troubleshooting, safety, and developer information.

BLEEP.HML.TECH / OWNER'S GUIDE

### 12 B / POCKET GUIDE

10 / SETTINGS + RESET

# Know what Factory Reset

removes.

Open the Home cog for version information, Wi-Fi, signed firmware updates, haptics, diagnostics, and Factory Reset.

Factory Reset requires a three-second hold. It removes saved devices and pairings, scenes, Wi-Fi, Home Assistant links, light setup, and preferences, then restarts Ble(e)p. It does not remove the installed software.

Use the full owner's guide for exact-model compatibility, pairing steps, limitations, assembly, and repair information.

### 11 B / POCKET GUIDE

09 / WORK SAFELY
Observe the real studio.

Secure cameras, sliders, lights, cables, and recorders before sending commands. Keep people and loose objects clear of moving equipment.

Watch for movement, recording, power, and light-output confirmation whenever state is optimistic or unknown.

Do not charge, use, ship, or enclose a hot, damaged, or swollen battery. Power Ble(e)p off before packing it.

Treat Wi-Fi details, tokens, pairing data, and device identities as private.

### 10 B / POCKET GUIDE

08 / TROUBLESHOOT
Recover methodically.

Device missing: use the exact pairing menu, remove an old phone/remote registration if needed, and retry.

Will not reconnect: wake the device, choose Manage > Disconnect, then reopen it. Free a physical link if four are active.

Scene not Ready: open the failed target, confirm it is enabled, and resolve its connection first.

Wi-Fi scan fails: return Home and retry near the access point. Use Portal to type a hidden network name.

Portal missing: stay on the Portal screen and use the numeric address shown if bleep.local does not work.

### 09 B / POCKET GUIDE

07 / READ THE STATUS

# Ready is not the same as

done.

Connecting / Preparing
The link is being established.

Ready
A command can be sent; physical success is not promised.

Pending
Ble(e)p is waiting for an answer.

Confirmed
The device reported the displayed state.

Sent / Optimistic / Unknown
Check the real equipment.

Unavailable / Failed
Resolve the device and choose Retry.

### 08 B / POCKET GUIDE

06 / PORTAL + HOME ASSISTANT
Configure in a browser.

Open Portal. Join the matching Bleep-Setup-XXXXX network or scan the panel QR, then use the address shown.

Portal pauses normal device control and exists only while its screen is open. Use Finish & Exit when done.

For Home Assistant, add trusted studio Wi-Fi, enter the local server URL and a long-lived token, then select up to four supported entities. The setup AP is open and Portal traffic is not encrypted.

### 07 B / POCKET GUIDE

### 50 mm - PRINT AT ACTUAL SIZE

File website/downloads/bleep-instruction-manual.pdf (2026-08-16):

# Ble(e)p Owner's Guide

## Set up your gear, control a shoot, and build repeatable studio workflows

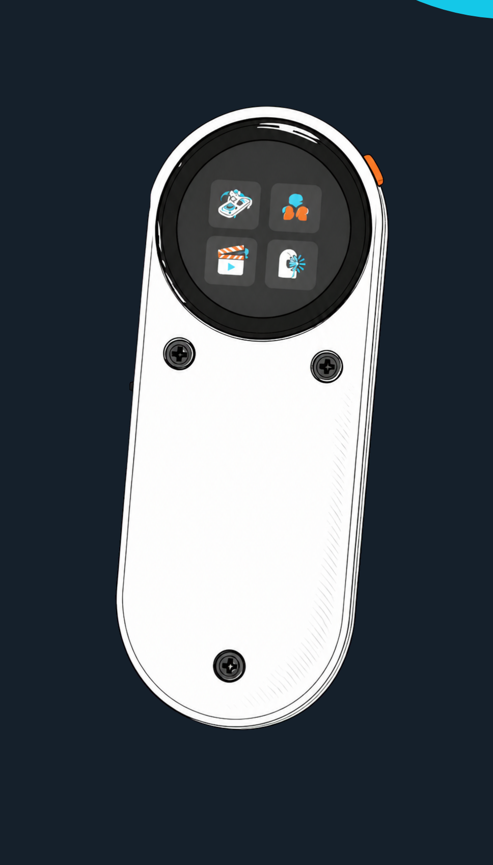
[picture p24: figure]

Development hardware -
verify before critical work
0.3.6 | 16 August 2026

BLE(E)P | Owner's guide
0.3.6 | 1

# Contents

Welcome | 3
Quick start | 3
Find your way around | 5
Set up your equipment | 6
Control cameras | 7
Control lights | 9
Control audio | 10
Control motion | 11
Connect Wi-Fi and Home Assistant | 11
Build repeatable workflows | 13
Personalize, diagnose, and reset | 15

Device compatibility matrix | 17
Troubleshooting | 17
Work safely | 19
Advanced: developers and builders | 20

# Welcome

Ble(e)p brings your cameras, lights, audio gear, slider, phone, and Home Assistant controls together in one small touchscreen remote. You can also save common actions as sequences and run them in order. Its playful name means Bluetooth Links Everything, Eventually, Probably; the practical version is Bluetooth Low Energy Equipment Panel.

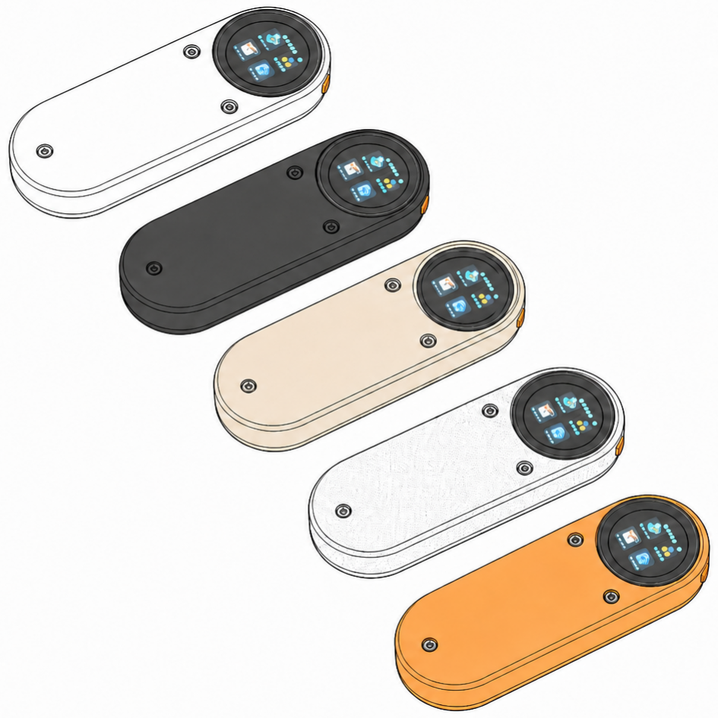
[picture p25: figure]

Five Ble(e)p enclosure finishes. All five use the same circular interface.

Ble(e)p is still in development - the "Eventually, Probably" part is there for a reason. Before an important shoot, check that your exact model is supported. When Ble(e)p says Sent, Optimistic, or Unknown, look at the equipment itself to make sure the action happened.

## Status words used here

Label | Meaning
Supported | Verified on the exact model for the listed functions.
Experimental | You can use it, but some situations still need testing.
Candidate | It may work, but this exact model has not been tested.
Research | It is being investigated and cannot be controlled yet.
Later | Not implemented.

# Quick start

Ble(e)p starts at Home and leaves your equipment disconnected until you open a device or run a sequence. If you have saved Wi-Fi, it briefly connects about five seconds after Home appears to check for a safe, signed update. It turns Wi-Fi off again when the check is finished.

1 Open Devices.

2 Open a saved device, or choose Add device and follow its pairing steps.

3 Wait for Ready.

4 Use the on-screen control or optional Action Button.

5 Check the equipment when the result is Sent, Optimistic, or Unknown.

## Action Button

A short press runs the main action on the current screen. Hold it for about 700 ms to go Back or cancel, or for two seconds to return Home. It is not a power button.

## Action Button by screen

Screen | Short press
Canon - Trigger Mode | Sends the movie trigger, which starts or stops recording without reading the camera's state.
Canon Smart, GoPro, DJI Osmo, or Tascam | Starts or stops recording according to the confirmed state.
Phone Camera | Sends the shutter command.
Insta360 | Runs Record Start while video is idle or Record Stop while recording. It does nothing while the camera reports photo mode or while recording state is unavailable.
Aputure, amaran, or Zhiyun light | Toggles the selected light On or Off.
Shark Nano II Keypoints | Opens the Run screen.
Shark Nano II Run | Runs the displayed Standby, Start, or Stop action.
Home Assistant entity | Light or switch: On; input boolean: On/Off toggle; button: Press; scene or script: Activate. Use the on-screen Off control for a Home Assistant light or switch.
Scene Run | Starts when Ready; once started or armed, stops the scene. Scene lists, editors, settings, and pickers ignore short presses.

On supported device screens, a short press also selects Retry when it is shown.

# Find your way around

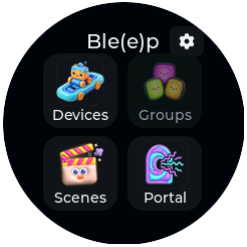
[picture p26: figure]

Home: Devices, Groups, Scenes, and Portal. The small cog opens Settings.
From Home, choose Devices to control equipment, Scenes to run saved workflows, Portal to set up Ble(e)p in a browser, or the cog to open Settings. Groups is not available yet.

# Set up your equipment

## Add a physical device

1 Open Devices.

2 Scroll to and select Add device.

3 Choose the equipment category, then the device family.

4 Put the real device in the exact pairing mode listed in this manual.

5 Wait for Ble(e)p to finish connecting and show Ready.

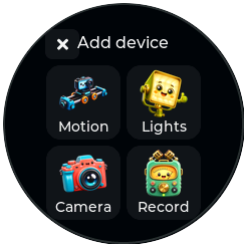
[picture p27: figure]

The Add device screen groups equipment into simple categories.

## Manage a saved device

Open a device's management menu to rename, enable, disable, disconnect, forget/re-pair, or delete it. Disabled devices are hidden from control and sequence lists without being deleted. Remove a device from every sequence before deleting it.

If your installed firmware does not include a saved device type, the entry stays saved but cannot be opened.

## Connection and state labels

Label or behavior | Meaning
Connecting / Preparing | Ble(e)p is connecting and getting the device ready.
Ready | You can send a command. Watch the equipment to make sure the action happens.
Pending | Ble(e)p is waiting for the device to answer.
Confirmed | The device reported the displayed state.
Optimistic / Sent | Ble(e)p sent the command but cannot check the physical result.
Unknown | Ble(e)p does not have a reliable current state. Check the equipment itself.
Unavailable / Failed | The device did not become ready. Check it and choose Retry, or go Back and reopen it.

# Control cameras

## Canon cameras

Canon Trigger Mode and Smart Phone Mode use separate camera pairings. Retry reconnects the camera saved for that entry; choose Forget before replacing it with another body.

Mode | Best for | Controls and feedback
Trigger Mode | The quickest remote-control setup | One movie trigger starts or stops recording. Ble(e)p cannot read the recording state.
Smart Phone Mode | Separate recording controls and camera feedback | Record Start, Record Stop, confirmed recording state, automatic wake, and on-screen power-down on the supported EOS R6 Mark II and Mark III paths.

### Trigger Mode

1 On the camera open its Bluetooth remote / BR-E1 pairing menu.

2 On Ble(e)p choose Canon (Trigger).

3 Complete pairing and wait for Ready.

4 Use Trigger on screen or press the Action Button.
The same trigger starts and stops recording, so check the camera before pressing it again. Trigger Mode is supported on the Canon EOS R6 Mark II and R6 Mark III. The original R6 has not been tested.

### Smart Phone Mode

1 On the camera choose Connect to smartphone > Add a device to connect to.

2 On Ble(e)p choose Canon (Smart).

3 Complete pairing, then use Record Start or Record Stop.
Smart Phone Mode supports confirmed recording state and automatic wake on the EOS R6 Mark II and R6 Mark III. The R6 Mark III also supports on-screen power-down; it is disabled during recording or a pending command. If the camera shows Connection target not found, remove its old phone registration and pair again.

## GoPro

Choose GoPro, put the camera in wireless pairing mode, and wait for Ready. Recording state and Start/Stop results are camera-confirmed.

Use the top-right power icon to sleep or wake an idle camera. Opening a sleeping GoPro or preparing it for a sequence also wakes it. GoPro documents remote BLE wake for eight hours after sleep; do not rely on it indefinitely.

The GoPro MAX2 is supported for pairing, confirmed Start/Stop, Sleep, wake, reconnection, and return to Ready. Other GoPro models have not been verified.

## Phone Camera

Ble(e)p appears to the phone as a wireless volume-up remote, which many camera apps can use as a shutter button.

1 Add Phone Camera on Ble(e)p.

2 Open Bluetooth settings on the phone and pair with Ble(e)p Shutter.

3 Open a camera app that maps Volume Up to shutter.

4 Use the on-screen Shutter action or press the Action Button.
Ble(e)p can remember four phones but cannot confirm that the camera app captured a photo or video. Automatic reconnection and mixed-sequence shutter operation are verified on the Google Pixel 9; other combinations remain unverified.

## Insta360

Ble(e)p appears as Insta360 Remote (Bleep) and uses the camera's reported state to offer Start or Stop.

1 Open the camera's GPS Remote pairing flow.

2 Add Insta360 on Ble(e)p and wait for the camera to connect to the panel.

3 Wait for the panel to show idle or recording state.

4 Use Start while video is idle or Stop while recording. No recording action is shown in photo mode or when state is unavailable.

5 On X5, use the on-screen power control to shut down or wake the camera. Wake can take up to 60 seconds while Ble(e)p waits for it to reconnect.
The Insta360 X3, X4, X4 Air, and X5 are supported. On X5, recording state, Start/Stop, photo-mode feedback, shutdown, and physical wake have been tested. Waking the camera after leaving and returning to its control screen still needs more testing. GO 3 and GO Ultra are unverified.

## DJI Osmo

1 Put the camera in its compatible remote-controller pairing flow.

2 Add DJI Osmo on Ble(e)p.

3 During first pairing, compare the four-digit code shown on the panel with the camera and approve it.

4 Wait for Ready, then use explicit Record Start/Stop.
Pairing, Start/Stop, and confirmed recording state are verified on the DJI Osmo Action 5 Pro and DJI Osmo 360. Reconnection, forget/re-pair, and two-camera use need more testing.

## Sony Camera

The Sony entry is for research only. It does not save a camera or provide controls yet.

# Control lights

## Aputure Light

Aputure Light adds compatible, factory-reset Aputure and amaran fixtures. Several compatible lights can share one Bluetooth connection while you still control each light separately.

1 Factory-reset the light and place it nearby in pairing mode.

2 Choose Devices > Add device > Lights > Aputure Light.

3 If several compatible fixtures appear, choose the intended name and address suffix.

4 Leave the light powered while Ble(e)p sets it up. The light may restart; wait for Ready.

5 Use On/Off, color temperature (CCT), tint, brightness, or RGB color controls as shown.

6 Check the fixture when a change is shown only as sent.

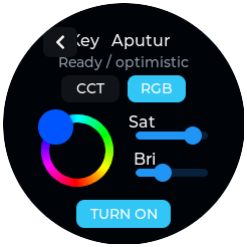
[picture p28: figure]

Aputure Light RGB controls. Color changes are sent quickly, but the displayed values are not read back from the light.
The controls adapt to each light. Ble(e)p remembers its CCT and RGB looks, brightness, mode, and power state. Changing tabs applies the stored look only while the light is On.

The amaran Ray 60c, amaran Ace 25c, Aputure MC Pro, and Aputure MT Pro are supported. The MT Pro currently appears as MC Pro because the tested fixtures report the same identity. Pano 60c and Pano 120c remain candidates.

## Zhiyun Light: MOLUS X100 and X60RGB

1 Choose Add device > Lights > Zhiyun Light once for each fixture.

2 If several compatible fixtures appear, choose the intended name and address suffix.

3 Wait while Ble(e)p identifies the model, connects, and reads its settings.

4 Use power, color temperature, and brightness. The X60RGB also offers hue and saturation controls.

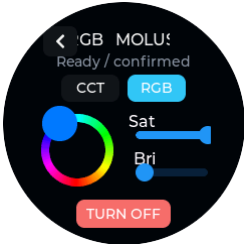
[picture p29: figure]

X60RGB control. The X100 uses the same layout without the RGB tab.
MOLUS X100: power, 2700-6500 K color temperature, and brightness. Everyday control is tested. Reconnecting after a power cycle and using several devices together need more testing.

MOLUS X60RGB: adds hue and saturation. Its color commands have been tested, but everyday panel use, reconnecting, recovery after a reset, and use with other lights need more testing.

Sidus Link network import is not supported. Aputure and Zhiyun lights share one connection but remain separate controls. Keep a compatible saved Zhiyun fixture powered whenever a Zhiyun target is active; it acts as the shared gateway.

# Control audio

## Tascam Portacapture X8

Tascam control requires the AK-BT1 Bluetooth adapter.

1 Install the AK-BT1 in the Portacapture X8.

2 Make the recorder available to its remote-app connection.

3 Choose Tascam X8 on Ble(e)p and wait for Ready.

4 Use Record Start and Record Stop. The Action Button performs the appropriate action for the state shown.
Start/Stop, reconnection, and restored recording state are verified. Battery, media status, and other recorder features are not available.

# Control motion

## iFootage Shark Nano II

### Pair

1 Make the Shark Nano II discoverable.

2 On Ble(e)p choose Devices > Add device > Motion > Shark Nano II.

3 Wait for the Shark control screen to show Ready.

### Functions

- read slider battery, keypoints, run state, and progress;
- save and select keypoints A-H;
- move manually with positioning controls and joystick;
- set speed and hold timing per keypoint;
- choose run direction and looping;
- enter Standby, Start, and Stop the programmed move;
- reconnect when opened.

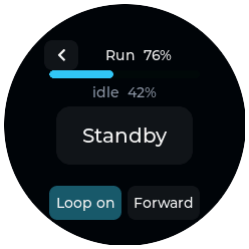
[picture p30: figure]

Shark Run shows progress, direction, looping, and the primary run-state action.

Slider movement can damage equipment or injure people. Clear the rail, secure the payload, and test at low speed. Watch the slider until the move is complete.

# Connect Wi-Fi and Home Assistant

Portal lets you configure Ble(e)p from a phone or computer. Device control is paused while Portal is open.

## First-time Portal setup

1 From Home open Portal.

2 Scan the QR code or join the open Bleep-Setup-XXXXX network matching the panel suffix.

3 Open the phone's sign-on page, or browse to the numeric setup address on the panel.

4 Manage devices and sequences directly; studio Wi-Fi is not required.

5 To use Home Assistant or configure a hidden network, open Wi-Fi, choose a network found during Portal entry or enter its SSID, and supply its password.

6 After Ble(e)p joins, note the web address shown on its screen. Rejoin the normal studio Wi-Fi on your phone or computer.

### 7 Open the displayed address while Ble(e)p remains on the Portal screen. You can also try

http://bleep.local.

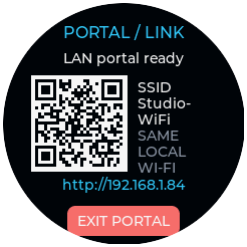
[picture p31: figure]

Portal after Ble(e)p joins your normal Wi-Fi. The address works only while the Portal screen is open.
Pair new physical equipment on Ble(e)p itself. Choose Finish & Exit in the browser or Exit on the panel when finished.

## Link Home Assistant entities

1 In Portal open Home Assistant.

2 Enter your server's local URL and a long-lived access token. Choose Change stored token only when replacing one.

3 Select up to four supported Home Assistant entities.

4 Save and exit Portal.

5 Open the saved entity under Devices or add it to a sequence.
Supported entities: lights, switches, input booleans, buttons, scenes, and scripts. Light and switch control is power-only.

Home Assistant can be Ready while an entity still shows Unknown. A successful command means Home Assistant accepted it; check the target if you need to confirm that something physically changed.

The Bleep-Setup network is open, and Portal traffic is not encrypted. Use it only in a controlled place. Connect Portal to your normal Wi-Fi only when you trust that network.

# Build repeatable workflows

A scene, also called a sequence, runs a saved list of actions and waits across one or more devices.

## Create a scene on the panel

1 Open Scenes and select Add sequence.

2 Build the Start list with Add step. Choose a target, action, and any parameters. For a light, Set look + On combines its color, brightness, and power-on in one step.

3 Add Wait steps where needed. New waits start at 200 ms; the included Press Record example uses 500 ms.

4 Select the arrow in the header to review the automatic Stop list. Ble(e)p reverses the Start order and adds a matching Stop action where it can.

5 Optional: choose Customize Stop if you want to edit that Stop list yourself.

6 Use the checkmark, enter a name, and save.
When you change Start, Ble(e)p updates the automatic Stop preview. New light looks begin at 5600 K, 50% brightness, neutral tint, and full RGB saturation. You can preview changes on the selected light. Set look + On adds one Turn Off action to Stop.

Use generated Stop replaces a custom Stop list after confirmation. You can edit and reorder existing steps; unavailable-device steps can still be deleted from a custom Stop list.

## Run a scene

1 Open the scene. Ble(e)p begins preparing every target.

2 Wait for Ready. Every target must be connected and prepared.

3 Select Start or press the Action Button.

4 Watch each step progress. Circular equipment shortcuts open individual controls.

5 Once armed, use Stop or press the Action Button. If Start fails partway through, you can still run Stop for cleanup and then try Start again.

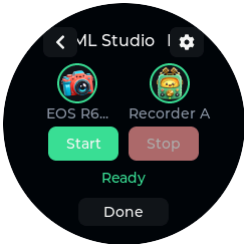
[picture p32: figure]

A prepared multi-device sequence. The circular equipment shortcuts show readiness and open individual controls.
Opening scene Settings cancels preparation. It does not interrupt a Start or Stop already in progress, an armed recording, or a failed Start that may still need cleanup.

## Action behavior to understand

Integration | Start/Stop behavior in scenes
Canon Trigger | Record Trigger; Ble(e)p cannot tell whether recording started or stopped.
Canon Smart, DJI, Tascam, GoPro | Separate Start and Stop actions. Confirmation varies by device.
Insta360 | Separate Start and Stop actions. Start is available after a fresh video-mode connection; Stop appears after the camera confirms it is recording.
Phone Camera | Sends a volume-up command; Ble(e)p cannot see what the camera app did.
Lights and Home Assistant switches | Separate On/Off. A light's Set look + On applies its stored CCT or RGB look and turns on that fixture; generated Stop adds one Turn Off.
Home Assistant button | Press.
Home Assistant scene/script | Activate.
Wait | Pause for the chosen number of milliseconds.

# Personalize, diagnose, and reset

Open the Home cog for version information, Wi-Fi, firmware updates, haptics, diagnostics, and Factory Reset.

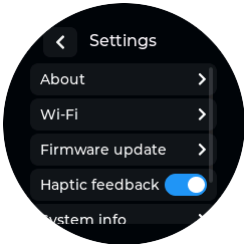
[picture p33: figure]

Settings includes About, Wi-Fi, Firmware update, haptics, system information, and Factory Reset.

## Connect Wi-Fi from the panel

Opening Settings > Wi-Fi does not connect by itself. To join or replace a visible network:

1 Choose Scan networks or Replace network.

2 If Ble(e)p is keeping equipment connected, confirm Disconnect & scan. An active command must finish first.

3 Select the network. Enter its password on the masked round keyboard when required.

4 Wait for Ble(e)p to connect. It saves the network only after the connection succeeds, then turns Wi-Fi off again.

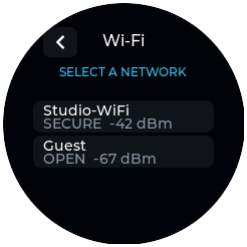
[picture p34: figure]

Visible networks are listed by signal strength after an explicit scan.
Use Portal for a hidden SSID, easier phone-based text entry, or Home Assistant setup. Forget network removes only the saved SSID and password; it preserves Home Assistant settings.

## Install a firmware update

Stable releases are selected by default. You can opt into Development builds, but they may not have been tested as thoroughly on real hardware.

With saved Wi-Fi, Ble(e)p checks your selected Stable or Development channel about five seconds after Home appears. If you are already using a device, scene, command, or Portal, it waits until Ble(e)p is idle. You can also choose Settings > Firmware update > Check now. A check downloads only the update details, not the firmware itself, and turns Wi-Fi off when finished.

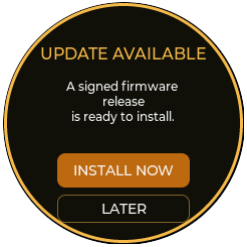
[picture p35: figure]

A newer signed release uses a round amber prompt with equal Install now and Later actions.
To install:

1 Keep Ble(e)p connected to reliable USB power.

2 Choose Install now, review the reboot warning, and confirm.

3 Leave power connected while the amber Preparing update screen appears and Ble(e)p installs the update. It will restart more than once.

4 Wait for Update successful, then choose Restart. Ble(e)p returns to Home after validating the new firmware.
Later dismisses that release's popup but leaves it available on the Firmware Update page. A newer release may prompt again. If preparation fails, return to the Firmware Update page and choose Retry update. Do not remove power during recovery or installation.

## Enter Recovery mode

On Settings > Firmware update, hold Recovery mode continuously for two seconds. Recovery can retry the requested update, install the latest stable release, start the installed firmware when it is still usable, or run Factory Reset. Use it after an interrupted update or when Ble(e)p cannot start normally.

## Factory Reset

Factory Reset requires a continuous three-second hold and working saved Wi-Fi. Ble(e)p first downloads and checks the latest stable firmware. It erases your saved devices and pairings, scenes, Wi-Fi, Home Assistant links, light setup, and preferences only after that download is ready. If the network or download fails, your saved setup is left untouched.

# Device compatibility matrix

Compatibility is intentionally exact. A similar model is not automatically supported.

Device or service | Status | Available functions | Key limitation or open gate
Canon EOS R6 Mark II / III -Trigger | Supported | Movie trigger and reconnect | Recording state is unavailable.
Canon EOS R6 - Trigger | Candidate | Intended movie trigger | Exact model untested.
Canon EOS R6 Mark III - Smart | Supported | Start/Stop, confirmation, wake, power-down | No additional camera controls.
Canon EOS R6 Mark II - Smart | Supported | Start/Stop and confirmation | No additional camera controls.
GoPro MAX2 | Supported | Start/Stop, confirmation, Sleep/wake | Use alongside several other devices needs more testing.
Other Open GoPro models | Candidate | Intended Start/Stop and state | No model-specific result.
Google Pixel 9 | Experimental | Volume-up shutter and reconnect | Capture cannot be confirmed.
Other phones | Candidate | Volume-up shutter | Phone and camera-app combinations untested.
Insta360 X3 / X4 / X4 Air | Supported | GPS Remote camera control | Reconnect, power, and use alongside other devices need more testing.
Insta360 X5 | Supported | Start/Stop, shutdown, wake | Wake after leaving and reopening its screen needs more testing.
Insta360 GO 3 | Candidate | Intended GPS Remote control | Exact model untested.
Insta360 GO Ultra | Research | None | GPS Remote compatibility unknown.
DJI Osmo Action 5 Pro / Osmo 360 | Supported | Four-digit pairing, Start/Stop, confirmation | Reconnect and two-camera use need testing.
Sony RMT-P1BT cameras | Research | None | Pairing and control unavailable.
Tascam Portacapture X8 + AK-BT1 | Supported | Start/Stop and confirmed state | No battery or media status.
Home Assistant local entities | Experimental | Up to four supported entities | Power-only lights and switches; no cloud sign-in.
amaran Ray 60c | Supported | Aputure Light power and looks | Long sessions and recovery after failures need more testing.
amaran Ace 25c / Aputure MC Pro | Supported | Setup, identity, RGB power and looks | Confirmation, recovery, and long sessions need more testing.
Aputure MT Pro | Supported | Setup, power, and looks | Currently labelled MC Pro.
amaran Pano 60c / Pano 120c | Candidate | Intended Aputure Light controls | Exact models untested.
Zhiyun MOLUS X100 | Experimental | Power, CCT, brightness, saved state | Cold reconnect, multi-light use, and recovery need testing.
Zhiyun MOLUS X60RGB | Experimental | Power, CCT, RGB, saved state | Panel, reconnect, recovery, and mixed-light use need testing.
Deity PR4 | Later | None | Not implemented.
iFootage Shark Nano II | Supported | Pair/reconnect, battery, keypoints, movement, run | Secure the payload and watch every move.

# Troubleshooting

## A device does not appear

- Confirm the target is in the correct pairing menu, not merely powered on.
- For a first-time light, select the intended name and address suffix when several appear.
- Re-enter the target's pairing mode and retry.

- If the device was paired to another phone or remote, remove the old registration or use Forget/re-pair as appropriate.
- For Canon, do not interchange BR-E1 and smartphone pairings.

## A saved device will not reconnect

- Open the saved device to begin reconnecting.
- Confirm the target is awake and still trusts Ble(e)p.
- Use Manage > Disconnect, then reopen.
- Ble(e)p can keep four equipment connections ready at once. Disconnect something you are not using, then try again.
- For a light, keep a compatible fixture powered and advertising, then use Retry.

## A command says Sent, Optimistic, or Unknown

Some equipment cannot tell Ble(e)p what happened. Check the camera display, recorder, light output, phone app, or slider directly. If you do not know the real state, do not press a toggle again without checking first.

## A scene cannot reach Ready

- Open the failed target and resolve its pairing or connection problem.
- Confirm every device used by the scene is enabled and available in the installed version.
- Check the four-connection limit. Compatible Aputure and Zhiyun lights share one connection; Home Assistant does not use one of the four.
- If the scene contains a Zhiyun light, keep a compatible saved Zhiyun fixture powered so it can provide the shared Aputure/Zhiyun gateway.
- If a multi-light scene fails, open the failed fixture, retry it, and confirm its physical output.
- Use Retry when shown. Opening scene Settings cancels preparation.

## Portal does not open

- Keep Ble(e)p on the Portal screen. Leaving it closes Portal.
- During first setup, join the Bleep-Setup-XXXXX network matching the panel suffix. If the sign-on page does not appear, use the numeric setup address.
- On the setup network, http://192.168.4.1 opens Portal directly. If the phone says the network has no internet, stay connected and open that address.
- After Ble(e)p joins the studio network, reconnect your phone or computer to that network and use the address shown on the panel.
- If bleep.local does not work, use the numeric address shown on Ble(e)p.

## Wi-Fi scan fails or finds no networks

- Return to Home, move closer to the access point, and scan again from Settings > Wi-Fi.
- For a hidden network, open Portal and enter the SSID and password yourself.

## A firmware update does not appear or complete

- Confirm Settings > Wi-Fi shows the intended saved network, and confirm the Firmware Update page is using the intended Stable or Development channel.
- Finish active device commands, leave Portal, and return Home before checking again. Ble(e)p never disconnects active equipment silently for an update.
- Keep USB power connected. If Preparing update returns to the Firmware Update page, choose Retry update. After an interrupted installation, enter Recovery mode and retry the requested update.

# Work safely

- Secure cameras, sliders, lights, cables, and recorders before sending commands.
- Watch the equipment itself for movement, recording, power, and light changes whenever Ble(e)p says Optimistic or Unknown.
- Use Portal only in a controlled place, and connect it only to Wi-Fi you trust; Portal traffic is not encrypted.
- Treat saved Wi-Fi details, Home Assistant tokens, pairing information, and device identities as private. Factory Reset removes them from Ble(e)p.
- Keep reliable USB power connected throughout firmware preparation, recovery, installation, and the final success confirmation.
- This project is independent and is not endorsed by iFootage, Canon, GoPro, Insta360, DJI, Sony, Tascam, Aputure, amaran, Zhiyun, Deity, Espressif, Elecrow, or Home Assistant.

# Advanced: developers and builders

This section is for building, repairing, or developing Ble(e)p. Opening the enclosure or modifying the battery lead requires electronics experience.

## Platform and operating limits

The reference build uses the Elecrow CrowPanel ESP32 1.28-inch round display, model DIS12824D: an ESP32-C3, 240 x 240 GC9A01 LCD, CST816D capacitive touch controller, PI4IOE5V6408 I/O expander, and onboard vibration motor. The case adds an optional Action Button and an SS12D00G slide switch for power.


Side profile of the reference enclosure. The orange actuator belongs to this build; placement can differ on community enclosures.
- The screen and backlight remain on continuously in the current firmware.
- The board does not sense its own battery voltage. A battery value on the Shark screen belongs to the slider.
- The registry holds 24 device records and up to 16 BLE bonds.
- Four physical BLE transport groups can remain connected. Compatible Aputure and Zhiyun fixtures share one group.
Function | GPIO or address
LCD DC / CS / SCK / MOSI | GPIO 2 / 10 / 6 / 7
I2C SDA / SCL | GPIO 4 / 5
Touch interrupt | GPIO 0
Action Button | GPIO 1, active low
Vibration motor | I/O expander P0
I/O expander | I2C 0x43
CST816D touch | I2C 0x15
BM8563 RTC | I2C 0x51

## Parts and tools

The maintained bill of materials and source links live in hardware/README.md. The reference assembly uses:

Item | Specification
Display/controller | Elecrow CrowPanel ESP32 1.28-inch, DIS12824D
Power switch | SS12D00G SPDT, 5 mm actuator
Battery | JLJLUP 3.7 V 1100 mAh 1S LiPo with protection board, 25 x 10 x 42 mm, and JST 1.25 plug; replace the plug during assembly
Battery pigtail | JST SH 1.0 mm, 2 pin
Threaded hardware | 3 x M3 x 6 x 5 mm heat-set inserts; 3 x M3 x 8 mm socket-head screws
Replacement battery-path diode | 1N5819 Schottky, DO-41; replaces the original CrowPanel D1

You also need a multimeter, temperature-controlled soldering iron, heat-set insertion tip, soldering supplies, heat-shrink or suitable insulation, and ordinary 3D-print cleanup tools. Battery packs and community kits vary; confirm every electrical rating rather than assuming a linked or visually similar part is correct.

## Print the enclosure

The hardware/ directory contains top, bottom, and button parts as 3MF and STL files. Use 3MF where supported. Bleep Remote.step is the editable assembly model for enclosure changes.

The original print used a Bambu Lab X1 Carbon, 0.4 mm nozzle, SuperTack plate, Bambu PLA Matte, and the stock 0.12mm High Quality @BBL X1C preset. Enable supports and select Normal (Auto) rather than Tree (Auto); otherwise keep the selected process and filament defaults. Put each part on its own plate and print the button first as a quick fit test.

## Assemble the enclosure

1 Clean the prints and dry-fit the display, slide switch, action-button actuator, battery, and both shells before soldering. The CrowPanel fits directly into the top shell without adhesive.

2 Confirm that the printed Action Button moves freely and transfers a case press to the board control. It is an action/navigation button, not a power button.

3 With a temperature-controlled iron and suitable tip, install the three heat-set inserts square to their bosses. Stop when each is flush; excessive heat or force can deform the shell.

4 Let the plastic cool completely. Do not install or wire the battery while the shell is still warm.

5 Complete and verify the switched battery lead as described below.

6 Remove the original CrowPanel D1 and install the external 1N5819 replacement as described below.

7 Route and insulate wiring so it cannot touch the PCB, antenna, USB connector, screw bosses, or moving switch parts. Fit the CrowPanel and battery without pinching a conductor.

8 Join the shells with three M3 x 8 mm screws. Tighten only until secure; overtightening can strip an insert or distort the print.

9 Before final use, check switch operation, button travel, charging behavior, and boot from battery with the enclosure attended.

## Wire the battery and power switch

The reference battery's original plug is incompatible with the CrowPanel socket. Replace it with a correctly wired JST SH 1.0 mm two-pin pigtail and put the slide switch in series with one battery lead:

Battery lead A -- switch COM -- selected throw -- connector lead A
Battery lead B ------------------------------- connector lead B
Use only the common terminal and one throw; insulate the unused throw. Identify the switch terminals with a multimeter, not by physical orientation. Verify continuity in both positions, then verify the finished connector's voltage and polarity against the CrowPanel markings and documentation before plugging it in.

Battery leads remain live during connector replacement. Cut and splice only one conductor at a time, insulate that joint before exposing the other conductor, and cover finished joints with heat-shrink. Never solder directly to a cell or its tabs. Do not charge, use, or enclose a damaged or swollen lithium battery, and prevent bare terminals from touching the board or each other.

## Replace the CrowPanel D1 battery path

The DIS12824D V1.0 schematic identifies D1 as a B5819WT Schottky diode in SOD-523, in series from VBAT to the board load. The reference assembly removes the original D1 and replaces it with a physically larger, through-hole 1N5819. Never leave both diodes connected in parallel, and never substitute a wire.

Disconnect USB and the battery. Use a multimeter to identify the actual VBAT and board-load nets rather than trusting wire colors:

battery-positive / VBAT -- unbanded [ 1N5819 ] banded -- board-load side
anode cathode
1 With all power removed, confirm the board-load side is not shorted to ground. If resistance stays near zero, stop and find the fault before continuing.

2 Confirm and mark the original D1 end connected to battery positive as the VBAT side and the opposite end as the board-load side.

3 Carefully desolder and remove the original D1. Heat each joint only as long as needed, lift the component without prying, then clean and inspect both pads. Stop if either pad or trace lifts.

4 Connect the external 1N5819's unbanded anode to VBAT. The verified battery-positive connector joint may be mechanically safer than loading the tiny former D1 pad.

5 Connect the banded cathode to the board-load side with short, flexible insulated wire. Do not let the DO-41 body pull on the former D1 pad.

6 Confirm that the removed D1 is no longer electrically connected. Insulate all exposed conductors, strain-relieve the replacement diode, and keep it clear of the antenna, USB connector, fasteners, and exposed pads.

7 Inspect for bridges, then make the first test from battery only. Disconnect immediately if the diode heats quickly, board voltage stays near zero, or operation is abnormal.
A build using this arrangement measured 4.0 V at the battery and 3.7 V on the load side while running. Before closing the case, exercise representative BLE scanning and connected operation while monitoring diode temperature and voltage drop. Disconnect immediately if the diode heats quickly or the voltage becomes unstable. The longer battery-endurance gate remains open.

## Build, test, and flash firmware

Use a compatible Python 3 installation and PlatformIO from the repository root. The full Montserrat profile is bleep:

python3 -m venv .venv
.venv/bin/python -m pip install -U pip platformio
PLATFORMIO_CORE_DIR="$PWD/.platformio-core" ./.venv/bin/python -m platformio test -e native PLATFORMIO_CORE_DIR="$PWD/.platformio-core" ./.venv/bin/python -m platformio run -e bleep PLATFORMIO_CORE_DIR="$PWD/.platformio-core" ./.venv/bin/python -m platformio run -e bleep -t upload
The configured upload port is /dev/cu.usbserial-211240; do not guess another port if it is absent. A normal PlatformIO upload writes main at 0x120000 and assumes the recovery partition layout already exists.

Build success is not proof of panel behavior, peripheral compatibility, browser behavior, tactile feel, or endurance. Record those separately and retain exact-model confidence labels.

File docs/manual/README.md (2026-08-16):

# Editing and building the Ble(e)p owner's guide

The owner-facing source is [`manual.md`](manual.md). Typography, tables, page
furniture, and PDF rendering live in [`build_manual.py`](build_manual.py), and
images live in `assets/`. The stable output is
`docs/manual/bleep-instruction-manual.pdf` at the repository root.

## Before editing

Edit or rebuild the manual only when the user explicitly requests it. Adding a
device to the support list is the exception: that change also requires a manual
update.

For a full manual refresh:

1. Find the last commit that changed `manual.md` or the generated PDF.
2. Audit every later implementation and documentation change for setup,
   controls, compatibility, safety, recovery, and troubleshooting impact.
3. Complete the implementation, manual source, generated PDF, and synchronized
   website copy on the same scoped feature branch.
4. Render and inspect the manual, rebase the branch onto current `main`, rerun
   the affected artifact checks, and merge it from `main` with `--no-ff`.

If there are no later changes, record that finding and continue on the scoped
branch. A manual refresh is a content audit, not a request to regenerate an
unchanged PDF.

Keep claims aligned with `README.md`, `docs/device-support.md`, and
`docs/progress.md`. Protocol evidence belongs under `docs/protocols/`; session
history and verification detail belong in `docs/progress.md`.

## Writing standard

Use the **Humanizer** skill whenever you write or revise the owner's guide.
Every chapter except **Advanced: developers and builders** must speak to the
person using Ble(e)p, not to an engineer or firmware developer. Explain what
the reader will see, what to do next, and what can go wrong in familiar words.
Keep implementation details in the Advanced chapter.

Write for someone using Ble(e)p during a shoot. Keep a sentence when it helps
the reader:

- complete a task;
- understand surprising behavior;
- avoid a likely mistake or safety hazard; or
- judge whether an exact device and function are supported.

Cut obvious interface narration, defensive reassurance, protocol internals,
test-history prose, and repeated limitation lists. For example, setup
instructions do not need to promise that a failed pairing will not create an
incomplete device. Preserve real boundaries such as optimistic state, toggle
commands, connection limits, destructive reset behavior, open Portal traffic,
movement risk, and exact-model compatibility.

Prefer short steps and direct verbs. Put information where the reader first
needs it, then link or refer back instead of repeating it. Do not add a second
function-reference layer that restates the task chapters. Keep electronics,
printing, assembly, repair, and firmware work in the final
**Advanced: developers and builders** section.

## Source format

The builder supports headings, paragraphs, ordered and unordered lists,
blockquote callouts, fenced code blocks, Markdown tables, page-break comments,
and figures:

```md
![Caption](assets/example.png){width=3.2 rotate=90}
```

Use `<!-- pagebreak -->` only when a deliberate chapter boundary is worth the
space. Recheck pagination after cutting or adding text; a useful break can turn
into a mostly empty page after an editorial change.

Hardware views are line illustrations generated from user-supplied reference
photographs. Regenerate them only when the enclosure changes. UI figures are
simulator captures from the source snapshot recorded in `docs/progress.md`;
replace a figure when the illustrated screen materially changes.

## Build the PDF

From `docs/manual/`:

```sh
python3 -m venv .venv
.venv/bin/python -m pip install -r requirements.txt
make PYTHON=.venv/bin/python pdf
```

If `.venv` already exists, run only the `make` command. Copy the finished PDF to
the website download before committing:

```sh
cp bleep-instruction-manual.pdf \
  ../../website/downloads/bleep-instruction-manual.pdf
```

The two files must have the same checksum. Publishing the website is a separate
step; deploy it only when the user asks for a live or mobile-review copy.

## Render and inspect

Render every page after any content or layout change, not only the page you
expected to move. Use a fresh empty directory so pages from an older, longer
build cannot linger:

```sh
render_dir=../../tmp/pdfs/manual-pages-review-1
test ! -e "$render_dir"
mkdir -p "$render_dir"
pdftoppm -r 120 -png bleep-instruction-manual.pdf \
  "$render_dir/page"
pdfinfo bleep-instruction-manual.pdf
```

Review all pages, preferably in contact sheets, then inspect changed pages and
dense tables at full resolution. Check for:

- clipped or overlapping text and images;
- captions colliding with the following paragraph;
- broken or overflowing tables;
- unexpected blank or mostly empty pages;
- awkward headings or lists split across pages; and
- incorrect headers, footers, page numbers, or contents entries.

Rebuild and rerender after every layout fix. Text extraction is useful for
confirming key phrases, exact models, dates, and page count, but it does not
replace visual inspection.

## Finish the update

Add a dated `docs/progress.md` entry with the audit base commit, material edits,
output page count, render settings, pages inspected at full resolution, defects
found and fixed, and whether firmware was built or flashed. Manual-only edits do
not require a firmware build or flash.

Commit the source, generated PDF, synchronized website copy, and progress entry
together. Remove temporary renders after verification; keep only the stable PDF
and maintained source artifacts.

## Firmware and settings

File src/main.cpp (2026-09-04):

#define LGFX_USE_V1

#include <Arduino.h>
#include <Wire.h>
#include <lvgl.h>
#include <LovyanGFX.hpp>

#include <cstdlib>
#include <cstring>

#include "build_info.h"
#include "driver_config.h"
#if CONFIG_BLE_RUNTIME_ENABLED
#include "core/ble/ble_runtime.h"
#endif
#include "core/device_manager.h"
#include "core/scene_service.h"
#include "core/system_info.h"
#include "fonts/ui_fonts.h"
#include "haptic_feedback.h"
#include "firmware_update.h"
#include "wifi_configuration.h"
#include "ui.h"
#include "portal_service.h"
#if CONFIG_DRIVER_CANON_BLE
#include "devices/canon_ble/client.h"
#endif

#if ARDUINO_USB_CDC_ON_BOOT
#define DEBUG_PORT Serial0
#else
#define DEBUG_PORT Serial
#endif

#ifndef DISPLAY_RGB_ORDER
#define DISPLAY_RGB_ORDER 0
#endif

#ifndef DISPLAY_FLUSH_SWAP565
#define DISPLAY_FLUSH_SWAP565 1
#endif

namespace board {
constexpr int lcdDc = 2;
constexpr int lcdCs = 10;
constexpr int lcdSck = 6;
constexpr int lcdMosi = 7;
constexpr int i2cSda = 4;
constexpr int i2cScl = 5;
constexpr int button = 1;
constexpr int touchInt = 0;

constexpr uint8_t ioExpanderAddr = 0x43;
constexpr uint8_t touchAddr = 0x15;
constexpr uint8_t ioDirectionReg = 0x03;
constexpr uint8_t ioOutputReg = 0x05;
constexpr uint8_t ioHighZReg = 0x07;
constexpr uint8_t ioVibrationMotor = 0;
constexpr uint8_t ioPanelPower = 4;
constexpr uint8_t ioTouchPower = 3;
constexpr uint8_t ioBacklight = 2;

#ifndef TOUCH_SWAP_XY
constexpr bool touchSwapXy = false;
#else
constexpr bool touchSwapXy = TOUCH_SWAP_XY;
#endif

#ifndef TOUCH_INVERT_X
constexpr bool touchInvertX = false;
#else
constexpr bool touchInvertX = TOUCH_INVERT_X;
#endif

#ifndef TOUCH_INVERT_Y
constexpr bool touchInvertY = false;
#else
constexpr bool touchInvertY = TOUCH_INVERT_Y;
#endif

constexpr uint32_t i2cFreq = 400000;
constexpr uint16_t screenWidth = 240;
constexpr uint16_t screenHeight = 240;
// Keep DMA double buffering, but use narrow partial-render strips so the
// ESP32-C3 can initialize Wi-Fi while concurrent BLE links remain active.
// Fifteen rows divides the 240-line panel evenly into 16 flushes.
constexpr uint16_t drawBufferRows = 15;
constexpr uint32_t buttonDebounceMs = 35;
constexpr uint32_t buttonLongPressMs = 700;
constexpr uint32_t buttonHomePressMs = 2000;
}  // namespace board

class CrowPanelDisplay : public lgfx::LGFX_Device {
 public:
  CrowPanelDisplay() {
    auto busCfg = bus_.config();
    busCfg.spi_host = SPI2_HOST;
    busCfg.spi_mode = 0;
    busCfg.freq_write = 80000000;
    busCfg.freq_read = 20000000;
    busCfg.spi_3wire = true;
    busCfg.use_lock = true;
    busCfg.dma_channel = SPI_DMA_CH_AUTO;
    busCfg.pin_sclk = board::lcdSck;
    busCfg.pin_mosi = board::lcdMosi;
    busCfg.pin_miso = -1;
    busCfg.pin_dc = board::lcdDc;
    bus_.config(busCfg);
    panel_.setBus(&bus_);

    auto panelCfg = panel_.config();
    panelCfg.pin_cs = board::lcdCs;
    panelCfg.pin_rst = -1;
    panelCfg.pin_busy = -1;
    panelCfg.memory_width = board::screenWidth;
    panelCfg.memory_height = board::screenHeight;
    panelCfg.panel_width = board::screenWidth;
    panelCfg.panel_height = board::screenHeight;
    panelCfg.offset_x = 0;
    panelCfg.offset_y = 0;
    panelCfg.offset_rotation = 0;
    panelCfg.dummy_read_pixel = 8;
    panelCfg.dummy_read_bits = 1;
    panelCfg.readable = false;
    panelCfg.invert = true;
    panelCfg.rgb_order = DISPLAY_RGB_ORDER != 0;
    panelCfg.dlen_16bit = false;
    panelCfg.bus_shared = false;
    panel_.config(panelCfg);
    setPanel(&panel_);
  }

 private:
  lgfx::Bus_SPI bus_;
  lgfx::Panel_GC9A01 panel_;
};

CrowPanelDisplay display;

static lv_disp_draw_buf_t drawBuf;
static lv_color_t lvBuf1[board::screenWidth * board::drawBufferRows];
static lv_color_t lvBuf2[board::screenWidth * board::drawBufferRows];
static lv_disp_drv_t dispDrv;
static lv_indev_drv_t touchDrv;

static bool touchPresent = false;
static uint8_t activeTouchAddr = board::touchAddr;
static uint8_t touchChipId = 0;
static uint8_t ioOutputState = 0;

studio::LinkState currentLink() {
  return studio::devices()
      .runtimeState(studio::devices().foregroundInstance())
      .link;
}

const char* linkLabel(studio::LinkState link) {
  switch (link) {
    case studio::LinkState::Disconnected:
      return "disconnected";
    case studio::LinkState::Scanning:
      return "scanning";
    case studio::LinkState::Connecting:
      return "connecting";
    case studio::LinkState::Connected:
      return "connected";
  }
  return "unknown";
}

void logRuntimeStats(const char* event) {
  const studio::SystemInfo info = studio::systemInfo();
  DEBUG_PORT.printf("runtime event=%s uptime_ms=%lu link=%s free_heap=%lu min_free_heap=%lu max_alloc=%lu wifi=%s\n",
                    event, static_cast<unsigned long>(millis()),
                    linkLabel(currentLink()),
                    static_cast<unsigned long>(info.freeHeap),
                    static_cast<unsigned long>(info.minimumFreeHeap),
                    static_cast<unsigned long>(info.largestFreeBlock),
                    info.wifiState);
}

enum class DebugDevicePhase : uint8_t {
  Idle,
  WaitingForReady,
  WaitingForDispatch,
  WaitingForConfirmation,
};

struct DebugDeviceCommand {
  DebugDevicePhase phase = DebugDevicePhase::Idle;
  studio::InstanceId instanceId = studio::kInvalidInstanceId;
  studio::CommandType command = studio::CommandType::Refresh;
  int32_t value0 = 0;
  int32_t value1 = 0;
  int32_t value2 = 0;
  uint32_t requestId = 0;
  uint32_t deadlineMs = 0;
};

DebugDeviceCommand debugDeviceCommand;

const char* debugDeviceAction(studio::CommandType command) {
  switch (command) {
    case studio::CommandType::TurnOn: return "on";
    case studio::CommandType::TurnOff: return "off";
    case studio::CommandType::SetLightCct: return "cct";
    case studio::CommandType::SetLightRgb: return "rgb";
    default: return "other";
  }
}

studio::Capability debugDeviceCapability(studio::CommandType command) {
  switch (command) {
    case studio::CommandType::TurnOn: return studio::Capability::TurnOn;
    case studio::CommandType::SetLightCct: return studio::Capability::SetLightCct;
    case studio::CommandType::SetLightRgb: return studio::Capability::SetLightRgb;
    default: return studio::Capability::TurnOff;
  }
}

void finishDebugDeviceCommand(const char* result) {
  DEBUG_PORT.printf(
      "debug_device event=complete instance=%lu action=%s result=%s\n",
      static_cast<unsigned long>(debugDeviceCommand.instanceId),
      debugDeviceAction(debugDeviceCommand.command), result);
  studio::devices().release(debugDeviceCommand.instanceId,
                            studio::ConnectionOwner::Sequence);
  debugDeviceCommand = DebugDeviceCommand{};
}

void beginDebugDeviceCommand(studio::InstanceId instanceId,
                             studio::CommandType command, int32_t value0 = 0,
                             int32_t value1 = 0, int32_t value2 = 0) {
  if (debugDeviceCommand.phase != DebugDevicePhase::Idle) {
    DEBUG_PORT.println("debug_device event=begin result=busy");
    return;
  }
  const studio::DeviceRecord* record = studio::devices().find(instanceId);
  const studio::Capability capability = debugDeviceCapability(command);
  if (record == nullptr ||
      (studio::devices().profile(instanceId).capabilities &
       studio::capabilityBit(capability)) == 0) {
    DEBUG_PORT.printf(
        "debug_device event=begin instance=%lu action=%s result=invalid_target\n",
        static_cast<unsigned long>(instanceId), debugDeviceAction(command));
    return;
  }
  if (studio::scenes().busy() ||
      studio::devices().ownedBy(instanceId, studio::ConnectionOwner::Sequence)) {
    DEBUG_PORT.printf(
        "debug_device event=begin instance=%lu action=%s result=scene_busy\n",
        static_cast<unsigned long>(instanceId), debugDeviceAction(command));
    return;
  }
  if (!studio::devices().acquire(instanceId,
                                 studio::ConnectionOwner::Sequence)) {
    DEBUG_PORT.printf(
        "debug_device event=begin instance=%lu action=%s result=acquire_failed\n",
        static_cast<unsigned long>(instanceId), debugDeviceAction(command));
    return;
  }
  debugDeviceCommand.phase = DebugDevicePhase::WaitingForReady;
  debugDeviceCommand.instanceId = instanceId;
  debugDeviceCommand.command = command;
  debugDeviceCommand.value0 = value0;
  debugDeviceCommand.value1 = value1;
  debugDeviceCommand.value2 = value2;
  debugDeviceCommand.deadlineMs = millis() + 30000;
  DEBUG_PORT.printf(
      "debug_device event=begin instance=%lu action=%s result=waiting\n",
      static_cast<unsigned long>(instanceId), debugDeviceAction(command));
}

void pollDebugDeviceCommand() {
  if (std::strcmp(build_info::kReleaseChannel, "local") != 0 ||
      debugDeviceCommand.phase == DebugDevicePhase::Idle)
    return;
  if (static_cast<int32_t>(millis() - debugDeviceCommand.deadlineMs) >= 0) {
    finishDebugDeviceCommand("timeout");
    return;
  }

  const studio::DeviceRuntimeState runtime =
      studio::devices().runtimeState(debugDeviceCommand.instanceId);
  if (debugDeviceCommand.phase == DebugDevicePhase::WaitingForReady) {
    if (!runtime.protocolReady) return;
    studio::DeviceCommand command;
    command.instanceId = debugDeviceCommand.instanceId;
    command.type = debugDeviceCommand.command;
    command.value0 = debugDeviceCommand.value0;
    command.value1 = debugDeviceCommand.value1;
    command.value2 = debugDeviceCommand.value2;
    if (!studio::devices().enqueue(command, &debugDeviceCommand.requestId)) {
      finishDebugDeviceCommand("queue_full");
      return;
    }
    debugDeviceCommand.phase = DebugDevicePhase::WaitingForDispatch;
    DEBUG_PORT.printf(
        "debug_device event=dispatch instance=%lu action=%s request=%lu\n",
        static_cast<unsigned long>(debugDeviceCommand.instanceId),
        debugDeviceAction(debugDeviceCommand.command),
        static_cast<unsigned long>(debugDeviceCommand.requestId));
    return;
  }

  if (debugDeviceCommand.phase == DebugDevicePhase::WaitingForDispatch) {
    studio::CommandResult result;
    if (!studio::devices().takeResult(debugDeviceCommand.requestId, result))
      return;
    if (result.status != studio::CommandStatus::Succeeded) {
      DEBUG_PORT.printf(
          "debug_device event=dispatch_result instance=%lu action=%s status=%u\n",
          static_cast<unsigned long>(debugDeviceCommand.instanceId),
          debugDeviceAction(debugDeviceCommand.command),
          static_cast<unsigned>(result.status));
      finishDebugDeviceCommand("dispatch_failed");
      return;
    }
    debugDeviceCommand.phase = DebugDevicePhase::WaitingForConfirmation;
    return;
  }

  if (!runtime.commandPending) {
    finishDebugDeviceCommand(runtime.commandFailed ? "confirmation_failed"
                                                   : "confirmed");
  }
}

void runDebugCommand(char* command) {
  if (std::strcmp(build_info::kReleaseChannel, "local") != 0) return;

  static constexpr char kDeviceOnPrefix[] = "device on ";
  static constexpr char kDeviceOffPrefix[] = "device off ";
  const char* deviceIdText = nullptr;
  studio::CommandType deviceCommand = studio::CommandType::Refresh;
  if (std::strncmp(command, kDeviceOnPrefix, sizeof(kDeviceOnPrefix) - 1) == 0) {
    deviceIdText = command + sizeof(kDeviceOnPrefix) - 1;
    deviceCommand = studio::CommandType::TurnOn;
  } else if (std::strncmp(command, kDeviceOffPrefix,
                          sizeof(kDeviceOffPrefix) - 1) == 0) {
    deviceIdText = command + sizeof(kDeviceOffPrefix) - 1;
    deviceCommand = studio::CommandType::TurnOff;
  }
  if (deviceIdText != nullptr) {
    char* end = nullptr;
    const unsigned long value = std::strtoul(deviceIdText, &end, 10);
    if (end == deviceIdText || *end != '\0' || value == 0) {
      DEBUG_PORT.println("debug_device event=begin result=invalid_id");
      return;
    }
    beginDebugDeviceCommand(static_cast<studio::InstanceId>(value),
                            deviceCommand);
    return;
  }

  static constexpr char kCctPrefix[] = "device cct ";
  static constexpr char kRgbPrefix[] = "device rgb ";
  const bool isCct =
      std::strncmp(command, kCctPrefix, sizeof(kCctPrefix) - 1) == 0;
  const bool isRgb =
      std::strncmp(command, kRgbPrefix, sizeof(kRgbPrefix) - 1) == 0;
  if (isCct || isRgb) {
    // "device cct <instance> <kelvin> <brightness>" and
    // "device rgb <instance> <rrggbb> <brightness>" exercise the look paths
    // that scenes use, so colour behaviour can be measured without the panel.
    const char* cursor = command + (isCct ? sizeof(kCctPrefix) - 1
                                          : sizeof(kRgbPrefix) - 1);
    char* end = nullptr;
    const unsigned long instance = std::strtoul(cursor, &end, 10);
    if (end == cursor || instance == 0) {
      DEBUG_PORT.println("debug_device event=begin result=invalid_id");
      return;
    }
    cursor = end;
    const unsigned long value = std::strtoul(cursor, &end, isRgb ? 16 : 10);
    if (end == cursor) {
      DEBUG_PORT.println("debug_device event=begin result=invalid_value");
      return;
    }
    cursor = end;
    const unsigned long brightness = std::strtoul(cursor, &end, 10);
    if (end == cursor || *end != '\0' || brightness > 100) {
      DEBUG_PORT.println("debug_device event=begin result=invalid_brightness");
      return;
    }
    beginDebugDeviceCommand(static_cast<studio::InstanceId>(instance),
                            isRgb ? studio::CommandType::SetLightRgb
                                  : studio::CommandType::SetLightCct,
                            static_cast<int32_t>(value),
                            static_cast<int32_t>(brightness), 0);
    return;
  }

  static constexpr char kStartPrefix[] = "scene start ";
  if (std::strncmp(command, kStartPrefix, sizeof(kStartPrefix) - 1) == 0) {
    char* end = nullptr;
    const unsigned long value =
        std::strtoul(command + sizeof(kStartPrefix) - 1, &end, 10);
    if (end == command + sizeof(kStartPrefix) - 1 || *end != '\0') {
      DEBUG_PORT.println("debug_scene event=start result=invalid_id");
      return;
    }
    const studio::SceneId sceneId = static_cast<studio::SceneId>(value);
    const studio::SceneRunStatus status = studio::scenes().start(sceneId);
    DEBUG_PORT.printf("debug_scene event=start scene=%lu status=%u\n", value,
                      static_cast<unsigned>(status));
    return;
  }
  if (std::strcmp(command, "scene stop") == 0) {
    const studio::SceneRunStatus status = studio::scenes().stop();
    DEBUG_PORT.printf("debug_scene event=stop status=%u\n",
                      static_cast<unsigned>(status));
    return;
  }
  if (std::strcmp(command, "scene cancel") == 0) {
    studio::scenes().cancel();
    DEBUG_PORT.println("debug_scene event=cancel result=ok");
    return;
  }
  // Bench access to the configuration Portal without touching the panel. The
  // serial console already requires physical access, so this keeps ADR-027's
  // physically-entered boundary for the operator while letting a tethered
  // host open the same screen the Settings tile does.
#if CONFIG_DRIVER_CANON_BLE
  static constexpr char kCanonBackoffPrefix[] = "canon backoff ";
  if (std::strncmp(command, kCanonBackoffPrefix,
                   sizeof(kCanonBackoffPrefix) - 1) == 0) {
    char* end = nullptr;
    const unsigned long value =
        std::strtoul(command + sizeof(kCanonBackoffPrefix) - 1, &end, 10);
    if (end == command + sizeof(kCanonBackoffPrefix) - 1 || *end != '\0' ||
        value > 60000) {
      DEBUG_PORT.println("debug_canon event=backoff result=invalid_value");
      return;
    }
    canon_ble::setRetryBackoffCapForDebug(static_cast<uint16_t>(value));
    DEBUG_PORT.printf("debug_canon event=backoff cap_ms=%lu\n", value);
    return;
  }
#endif
  static constexpr char kDeviceShowPrefix[] = "device show ";
  if (std::strncmp(command, kDeviceShowPrefix,
                   sizeof(kDeviceShowPrefix) - 1) == 0) {
    char* end = nullptr;
    const unsigned long value =
        std::strtoul(command + sizeof(kDeviceShowPrefix) - 1, &end, 10);
    if (end == command + sizeof(kDeviceShowPrefix) - 1 || *end != '\0' ||
        value == 0) {
      DEBUG_PORT.println("debug_device event=show result=invalid_id");
      return;
    }
    // Same path as tapping the row in Devices: foreground ownership and the
    // device's own control screen.
    ui::showDevice(static_cast<studio::InstanceId>(value));
    DEBUG_PORT.printf("debug_device event=show instance=%lu\n", value);
    return;
  }
  if (std::strcmp(command, "device home") == 0) {
    ui::showHome();
    DEBUG_PORT.println("debug_device event=home result=ok");
    return;
  }
  if (std::strcmp(command, "heap") == 0) {
    const studio::SystemInfo info = studio::systemInfo();
    DEBUG_PORT.printf(
        "debug_heap free_heap=%lu min_free_heap=%lu max_alloc=%lu wifi=%s\n",
        static_cast<unsigned long>(info.freeHeap),
        static_cast<unsigned long>(info.minimumFreeHeap),
        static_cast<unsigned long>(info.largestFreeBlock), info.wifiState);
    return;
  }
  if (std::strcmp(command, "portal start") == 0) {
    ui::showPortal();
    DEBUG_PORT.printf("debug_portal event=start active=%u status=%s\n",
                      portal::active() ? 1u : 0u, portal::statusText());
    return;
  }
  if (std::strcmp(command, "portal stop") == 0) {
    portal::stop();
    ui::showHome();
    DEBUG_PORT.println("debug_portal event=stop result=ok");
    return;
  }
  DEBUG_PORT.println("debug event=command result=unknown");
}

void pollDebugSerial() {
  if (std::strcmp(build_info::kReleaseChannel, "local") != 0) return;
  static char command[48] = {};
  static size_t length = 0;
  while (DEBUG_PORT.available() > 0) {
    const char value = static_cast<char>(DEBUG_PORT.read());
    if (value == '\r') continue;
    if (value == '\n') {
      command[length] = '\0';
      if (length > 0) runDebugCommand(command);
      length = 0;
      continue;
    }
    if (length + 1 < sizeof(command)) {
      command[length++] = value;
    } else {
      length = 0;
      DEBUG_PORT.println("debug event=command result=too_long");
    }
  }
}

bool i2cWrite8(uint8_t addr, uint8_t reg, uint8_t value) {
  Wire.beginTransmission(addr);
  Wire.write(reg);
  Wire.write(value);
  return Wire.endTransmission() == 0;
}

bool i2cRead(uint8_t addr, uint8_t reg, uint8_t* data, size_t len) {
  Wire.beginTransmission(addr);
  Wire.write(reg);
  if (Wire.endTransmission(false) != 0) {
    return false;
  }
  if (Wire.requestFrom(static_cast<int>(addr), static_cast<int>(len)) != len) {
    return false;
  }
  for (size_t i = 0; i < len; ++i) {
    data[i] = Wire.read();
  }
  return true;
}

bool i2cDevicePresent(uint8_t addr) {
  Wire.beginTransmission(addr);
  return Wire.endTransmission() == 0;
}

void scanI2cBus() {
  DEBUG_PORT.print("I2C:");
  int found = 0;
  for (uint8_t addr = 1; addr < 0x7F; ++addr) {
    if (i2cDevicePresent(addr)) {
      found++;
      DEBUG_PORT.printf(" %02X", addr);
    }
  }
  if (found == 0) {
    DEBUG_PORT.print(" none");
  }
  DEBUG_PORT.println();
}

void ioSetPin(uint8_t pin, bool high) {
  if (high) {
    ioOutputState |= (1U << pin);
  } else {
    ioOutputState &= ~(1U << pin);
  }
  i2cWrite8(board::ioExpanderAddr, board::ioOutputReg, ioOutputState);
}

void initIoExpander() {
  constexpr uint8_t enabledPins =
      (1U << board::ioVibrationMotor) | (1U << 1) | (1U << board::ioBacklight) |
      (1U << board::ioTouchPower) | (1U << board::ioPanelPower);

  ioOutputState = 0;
  i2cWrite8(board::ioExpanderAddr, board::ioOutputReg, ioOutputState);
  i2cWrite8(board::ioExpanderAddr, board::ioDirectionReg, enabledPins);
  i2cWrite8(board::ioExpanderAddr, board::ioHighZReg, static_cast<uint8_t>(~enabledPins));
  ioSetPin(board::ioTouchPower, true);
  delay(80);
  ioSetPin(board::ioPanelPower, true);
  delay(80);
  ioSetPin(board::ioBacklight, true);
  delay(80);
}

void setHapticMotor(bool enabled) {
  ioSetPin(board::ioVibrationMotor, enabled);
}

bool initTouch() {
  activeTouchAddr = board::touchAddr;

  pinMode(board::touchInt, OUTPUT);
  digitalWrite(board::touchInt, HIGH);
  delay(1);
  digitalWrite(board::touchInt, LOW);
  delay(1);

  if (!i2cDevicePresent(activeTouchAddr)) {
    DEBUG_PORT.printf("No CST816D at 0x%02X\n", activeTouchAddr);
    return false;
  }

  i2cRead(activeTouchAddr, 0xA7, &touchChipId, 1);
  i2cWrite8(activeTouchAddr, 0xFE, 0xFF);
  DEBUG_PORT.printf("CST816D 0x%02X id 0x%02X\n", activeTouchAddr, touchChipId);
  return true;
}
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
void loop() {
  static uint32_t lastTickMs = millis();
  static uint32_t lastStatsMs = millis();
  static studio::LinkState lastLink = currentLink();
  const uint32_t now = millis();
  lv_tick_inc(now - lastTickMs);
  lastTickMs = now;

#if CONFIG_BLE_RUNTIME_ENABLED
  studio::ble::loopBleRuntime(now);
#endif
  studio::devices().loop();
  studio::scenes().loop(now);
  pollDebugSerial();
  pollDebugDeviceCommand();
  portal::loop();
  firmware_update::service().setRuntimeIdle(
      !portal::active() && !studio::scenes().busy() &&
          studio::devices().activeCount() == 0 &&
          !wifi_configuration::service().active(),
      ui::showingHome());
  firmware_update::service().loop();
  wifi_configuration::service().loop();
  const studio::LinkState link = currentLink();
  if (link != lastLink) {
    lastLink = link;
    logRuntimeStats("link_change");
  }
  if (now - lastStatsMs >= 30000) {
    lastStatsMs = now;
    logRuntimeStats("periodic");
  }
  haptic_feedback::loop(now);
  pollButton();
  ui::tick();

  lv_timer_handler();
  delay(5);
}

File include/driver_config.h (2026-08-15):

#pragma once

// PlatformIO supplies these today. The names intentionally match ESP-IDF
// Kconfig symbols so a future Arduino-as-component build can replace defaults
// without changing driver code.
#ifndef CONFIG_DRIVER_SHARK_NANO_II
#define CONFIG_DRIVER_SHARK_NANO_II 0
#endif

#ifndef CONFIG_DRIVER_CANON_BLE
#define CONFIG_DRIVER_CANON_BLE 0
#endif

#ifndef CONFIG_DRIVER_CANON_TRIGGER
#define CONFIG_DRIVER_CANON_TRIGGER 0
#endif

#ifndef CONFIG_DRIVER_TASCAM_X8
#define CONFIG_DRIVER_TASCAM_X8 0
#endif

#ifndef CONFIG_DRIVER_HOME_ASSISTANT
#define CONFIG_DRIVER_HOME_ASSISTANT 0
#endif

#ifndef CONFIG_DRIVER_APUTURE_LIGHT
#define CONFIG_DRIVER_APUTURE_LIGHT 0
#endif

#ifndef CONFIG_DRIVER_ZHIYUN_LIGHT
#define CONFIG_DRIVER_ZHIYUN_LIGHT 0
#endif

#ifndef CONFIG_DRIVER_GOPRO
#define CONFIG_DRIVER_GOPRO 0
#endif

#ifndef CONFIG_DRIVER_SONY_CAMERA
#define CONFIG_DRIVER_SONY_CAMERA 0
#endif

#ifndef CONFIG_DRIVER_INSTA360
#define CONFIG_DRIVER_INSTA360 0
#endif

#ifndef CONFIG_DRIVER_DJI_OSMO
#define CONFIG_DRIVER_DJI_OSMO 0
#endif

#ifndef CONFIG_DRIVER_PHONE_CAMERA
#define CONFIG_DRIVER_PHONE_CAMERA 0
#endif

#define CONFIG_BLE_RUNTIME_ENABLED                                      \
  (CONFIG_DRIVER_SHARK_NANO_II || CONFIG_DRIVER_CANON_BLE ||           \
   CONFIG_DRIVER_CANON_TRIGGER || CONFIG_DRIVER_TASCAM_X8 ||           \
   CONFIG_DRIVER_APUTURE_LIGHT || CONFIG_DRIVER_ZHIYUN_LIGHT ||        \
   CONFIG_DRIVER_GOPRO || CONFIG_DRIVER_INSTA360 || CONFIG_DRIVER_DJI_OSMO || \
   CONFIG_DRIVER_PHONE_CAMERA)

#ifndef CONFIG_MAX_DEVICE_INSTANCES
#define CONFIG_MAX_DEVICE_INSTANCES 24
#endif

#ifndef CONFIG_DEVICE_COMMAND_QUEUE_SIZE
#define CONFIG_DEVICE_COMMAND_QUEUE_SIZE 12
#endif

#ifndef CONFIG_MAX_ACTIVE_LINKS
#define CONFIG_MAX_ACTIVE_LINKS 4
#endif

#ifndef CONFIG_MAX_ACTIVE_INSTANCES
#define CONFIG_MAX_ACTIVE_INSTANCES CONFIG_MAX_ACTIVE_LINKS
#endif

#if defined(CONFIG_BT_NIMBLE_MAX_CONNECTIONS) && \
    CONFIG_MAX_ACTIVE_LINKS > CONFIG_BT_NIMBLE_MAX_CONNECTIONS
#error "CONFIG_MAX_ACTIVE_LINKS cannot exceed CONFIG_BT_NIMBLE_MAX_CONNECTIONS"
#endif

#ifndef CONFIG_BLE_EVENT_QUEUE_SIZE
#define CONFIG_BLE_EVENT_QUEUE_SIZE 16
#endif

#ifndef CONFIG_BLE_ADV_QUEUE_SIZE
#define CONFIG_BLE_ADV_QUEUE_SIZE 8
#endif

#ifndef CONFIG_BLE_ADV_PAYLOAD_SIZE
#define CONFIG_BLE_ADV_PAYLOAD_SIZE 96
#endif

#ifndef CONFIG_BLE_MAX_SKIP_ADDRESSES
#define CONFIG_BLE_MAX_SKIP_ADDRESSES 4
#endif

#ifndef CONFIG_BLE_TX_POWER_DBM
#define CONFIG_BLE_TX_POWER_DBM 6
#endif

#ifndef CONFIG_BLE_SCAN_INTERVAL_UNITS
#define CONFIG_BLE_SCAN_INTERVAL_UNITS 100
#endif

#ifndef CONFIG_BLE_SCAN_WINDOW_UNITS
#define CONFIG_BLE_SCAN_WINDOW_UNITS 40
#endif

#if CONFIG_BLE_SCAN_INTERVAL_UNITS == 0 || CONFIG_BLE_SCAN_WINDOW_UNITS == 0 || \
    CONFIG_BLE_SCAN_WINDOW_UNITS > CONFIG_BLE_SCAN_INTERVAL_UNITS
#error "BLE scan window must be between 1 and the scan interval"
#endif

#if CONFIG_BLE_TX_POWER_DBM < -24 || CONFIG_BLE_TX_POWER_DBM > 20
#error "CONFIG_BLE_TX_POWER_DBM must be between -24 and 20 dBm"
#endif

#ifndef CONFIG_MAX_SCENE_STEPS
#define CONFIG_MAX_SCENE_STEPS 8
#endif

#ifndef CONFIG_SCENE_MIN_WAIT_MS
#define CONFIG_SCENE_MIN_WAIT_MS 0
#endif

#ifndef CONFIG_SCENE_MAX_WAIT_MS
#define CONFIG_SCENE_MAX_WAIT_MS 60000
#endif

#ifndef CONFIG_SCENE_DEFAULT_WAIT_MS
#define CONFIG_SCENE_DEFAULT_WAIT_MS 200
#endif

#if CONFIG_SCENE_DEFAULT_WAIT_MS < CONFIG_SCENE_MIN_WAIT_MS || \
    CONFIG_SCENE_DEFAULT_WAIT_MS > CONFIG_SCENE_MAX_WAIT_MS
#error "CONFIG_SCENE_DEFAULT_WAIT_MS must be within the scene wait range"
#endif

#ifndef CONFIG_SCENE_CONNECT_TIMEOUT_MS
#define CONFIG_SCENE_CONNECT_TIMEOUT_MS 30000
#endif

#ifndef CONFIG_SCENE_PHYSICAL_CONNECT_TIMEOUT_MS
#define CONFIG_SCENE_PHYSICAL_CONNECT_TIMEOUT_MS 60000
#endif

#ifndef CONFIG_SCENE_ACTION_TIMEOUT_MS
#define CONFIG_SCENE_ACTION_TIMEOUT_MS 5000
#endif

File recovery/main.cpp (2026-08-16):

#define LGFX_USE_V1

#include <Arduino.h>
#include <SPI.h>
#include <WiFi.h>
#include <Wire.h>
#include <esp_http_client.h>
#include <esp_image_format.h>
#include <esp_ota_ops.h>
#include <mbedtls/pk.h>
#include <mbedtls/sha256.h>
#include <nvs_flash.h>
#include <time.h>

#include "core/home_assistant_config.h"
#include "core/partition_recovery_backend.h"
#include "core/preferences_store.h"
#include "core/recovery_journal.h"
#include "core/recovery_startup_policy.h"
#include "core/recovery_touch_gate.h"
#include "firmware_update_keys.h"

namespace {

constexpr int kHttpBufferSize = 8192;

constexpr char kStableManifestUrl[] =
    "https://github.com/nethunter/bleep/releases/latest/download/bleep-update.json";
constexpr size_t kMaximumImageSize = 0x2C0000;
constexpr uint32_t kConnectTimeoutMs = 15000;
constexpr char kRootCa[] = R"CERT(-----BEGIN CERTIFICATE-----
MIIDjjCCAnagAwIBAgIQAzrx5qcRqaC7KGSxHQn65TANBgkqhkiG9w0BAQsFADBh
MQswCQYDVQQGEwJVUzEVMBMGA1UEChMMRGlnaUNlcnQgSW5jMRkwFwYDVQQLExB3
d3cuZGlnaWNlcnQuY29tMSAwHgYDVQQDExdEaWdpQ2VydCBHbG9iYWwgUm9vdCBH
MjAeFw0xMzA4MDExMjAwMDBaFw0zODAxMTUxMjAwMDBaMGExCzAJBgNVBAYTAlVT
MRUwEwYDVQQKEwxEaWdpQ2VydCBJbmMxGTAXBgNVBAsTEHd3dy5kaWdpY2VydC5j
b20xIDAeBgNVBAMTF0RpZ2lDZXJ0IEdsb2JhbCBSb290IEcyMIIBIjANBgkqhkiG
9w0BAQEFAAOCAQ8AMIIBCgKCAQEAuzfNNNx7a8myaJCtSnX/RrohCgiN9RlUyfuI
2/Ou8jqJkTx65qsGGmvPrC3oXgkkRLpimn7Wo6h+4FR1IAWsULecYxpsMNzaHxmx
1x7e/dfgy5SDN67sH0NO3Xss0r0upS/kqbitOtSZpLYl6ZtrAGCSYP9PIUkY92eQ
q2EGnI/yuum06ZIya7XzV+hdG82MHauVBJVJ8zUtluNJbd134/tJS7SsVQepj5Wz
tCO7TG1F8PapspUwtP1MVYwnSlcUfIKdzXOS0xZKBgyMUNGPHgm+F6HmIcr9g+UQ
vIOlCsRnKPZzFBQ9RnbDhxSJITRNrw9FDKZJobq7nMWxM4MphQIDAQABo0IwQDAP
BgNVHRMBAf8EBTADAQH/MA4GA1UdDwEB/wQEAwIBhjAdBgNVHQ4EFgQUTiJUIBiV
5uNu5g/6+rkS7QYXjzkwDQYJKoZIhvcNAQELBQADggEBAGBnKJRvDkhj6zHd6mcY
1Yl9PMWLSn/pvtsrF9+wX3N3KjITOYFnQoQj8kVnNeyIv/iPsGEMNKSuIEyExtv4
NeF22d+mQrvHRAiGfzZ0JFrabA0UWTW98kndth/Jsw1HKj2ZL7tcu7XUIOGZX1NG
Fdtom/DzMNU+MeKNhJ7jitralj41E6Vf8PlwUHBHQRFXGU7Aj64GxJUTFy8bJZ91
8rGOmaFvE7FBcf6IKshPECBV1/MUReXgRPTqh5Uykw7+U0b6LJ3/iyK5S9kJRaTe
pLiaWN0bfVKfjllDiIGknibVb63dDcY3fe0Dkhvld1927jyNxF1WW6LZZm6zNTfl
MrY=
-----END CERTIFICATE-----
-----BEGIN CERTIFICATE-----
MIICjzCCAhWgAwIBAgIQXIuZxVqUxdJxVt7NiYDMJjAKBggqhkjOPQQDAzCBiDEL
MAkGA1UEBhMCVVMxEzARBgNVBAgTCk5ldyBKZXJzZXkxFDASBgNVBAcTC0plcnNl
eSBDaXR5MR4wHAYDVQQKExVUaGUgVVNFUlRSVVNUIE5ldHdvcmsxLjAsBgNVBAMT
JVVTRVJUcnVzdCBFQ0MgQ2VydGlmaWNhdGlvbiBBdXRob3JpdHkwHhcNMTAwMjAx
MDAwMDAwWhcNMzgwMTE4MjM1OTU5WjCBiDELMAkGA1UEBhMCVVMxEzARBgNVBAgT
Ck5ldyBKZXJzZXkxFDASBgNVBAcTC0plcnNleSBDaXR5MR4wHAYDVQQKExVUaGUg
VVNFUlRSVVNUIE5ldHdvcmsxLjAsBgNVBAMTJVVTRVJUcnVzdCBFQ0MgQ2VydGlm
aWNhdGlvbiBBdXRob3JpdHkwdjAQBgcqhkjOPQIBBgUrgQQAIgNiAAQarFRaqflo
I+d61SRvU8Za2EurxtW20eZzca7dnNYMYf3boIkDuAUU7FfO7l0/4iGzzvfUinng
o4N+LZfQYcTxmdwlkWOrfzCjtHDix6EznPO/LlxTsV+zfTJ/ijTjeXmjQjBAMB0G
A1UdDgQWBBQ64QmG1M8ZwpZ2dEl23OA1xmNjmjAOBgNVHQ8BAf8EBAMCAQYwDwYD
VR0TAQH/BAUwAwEB/zAKBggqhkjOPQQDAwNoADBlAjA2Z6EWCNzklwBBHU6+4WMB
zzuqQhFkoJ2UOQIReVx7Hfpkue4WQrO/isIJxOzksU0CMQDpKmFHjFJKS04YcPbW
RNZu9YO6bVi9JNlWSOrvxKJGgYhqOkbRqZtNyWHa0V1Xahg=
-----END CERTIFICATE-----
-----BEGIN CERTIFICATE-----
MIIFazCCA1OgAwIBAgIRAIIQz7DSQONZRGPgu2OCiwAwDQYJKoZIhvcNAQELBQAw
TzELMAkGA1UEBhMCVVMxKTAnBgNVBAoTIEludGVybmV0IFNlY3VyaXR5IFJlc2Vh
cmNoIEdyb3VwMRUwEwYDVQQDEwxJU1JHIFJvb3QgWDEwHhcNMTUwNjA0MTEwNDM4
WhcNMzUwNjA0MTEwNDM4WjBPMQswCQYDVQQGEwJVUzEpMCcGA1UEChMgSW50ZXJu
ZXQgU2VjdXJpdHkgUmVzZWFyY2ggR3JvdXAxFTATBgNVBAMTDElTUkcgUm9vdCBY
MTCCAiIwDQYJKoZIhvcNAQEBBQADggIPADCCAgoCggIBAK3oJHP0FDfzm54rVygc
h77ct984kIxuPOZXoHj3dcKi/vVqbvYATyjb3miGbESTtrFj/RQSa78f0uoxmyF+
0TM8ukj13Xnfs7j/EvEhmkvBioZxaUpmZmyPfjxwv60pIgbz5MDmgK7iS4+3mX6U
A5/TR5d8mUgjU+g4rk8Kb4Mu0UlXjIB0ttov0DiNewNwIRt18jA8+o+u3dpjq+sW
T8KOEUt+zwvo/7V3LvSye0rgTBIlDHCNAymg4VMk7BPZ7hm/ELNKjD+Jo2FR3qyH
B5T0Y3HsLuJvW5iB4YlcNHlsdu87kGJ55tukmi8mxdAQ4Q7e2RCOFvu396j3x+UC
B5iPNgiV5+I3lg02dZ77DnKxHZu8A/lJBdiB3QW0KtZB6awBdpUKD9jf1b0SHzUv
KBds0pjBqAlkd25HN7rOrFleaJ1/ctaJxQZBKT5ZPt0m9STJEadao0xAH0ahmbWn
OlFuhjuefXKnEgV4We0+UXgVCwOPjdAvBbI+e0ocS3MFEvzG6uBQE3xDk3SzynTn
jh8BCNAw1FtxNrQHusEwMFxIt4I7mKZ9YIqioymCzLq9gwQbooMDQaHWBfEbwrbw
qHyGO0aoSCqI3Haadr8faqU9GY/rOPNk3sgrDQoo//fb4hVC1CLQJ13hef4Y53CI
rU7m2Ys6xt0nUW7/vGT1M0NPAgMBAAGjQjBAMA4GA1UdDwEB/wQEAwIBBjAPBgNV
HRMBAf8EBTADAQH/MB0GA1UdDgQWBBR5tFnme7bl5AFzgAiIyBpY9umbbjANBgkq
hkiG9w0BAQsFAAOCAgEAVR9YqbyyqFDQDLHYGmkgJykIrGF1XIpu+ILlaS/V9lZL
ubhzEFnTIZd+50xx+7LSYK05qAvqFyFWhfFQDlnrzuBZ6brJFe+GnY+EgPbk6ZGQ
3BebYhtF8GaV0nxvwuo77x/Py9auJ/GpsMiu/X1+mvoiBOv/2X/qkSsisRcOj/KK
NFtY2PwByVS5uCbMiogziUwthDyC3+6WVwW6LLv3xLfHTjuCvjHIInNzktHCgKQ5
ORAzI4JMPJ+GslWYHb4phowim57iaztXOoJwTdwJx4nLCgdNbOhdjsnvzqvHu7Ur
TkXWStAmzOVyyghqpZXjFaH3pO3JLF+l+/+sKAIuvtd7u+Nxe5AW0wdeRlN8NwdC
jNPElpzVmbUq4JUagEiuTDkHzsxHpFKVK7q4+63SM1N95R1NbdWhscdCb+ZAJzVc
oyi3B43njTOQ5yOf+1CceWxG1bQVs5ZufpsMljq4Ui0/1lvh+wjChP4kqKOJ2qxq
4RgqsahDYVvTH9w7jXbyLeiNdd8XM2w9U/t7y0Ff/9yi0GE44Za4rF2LN9d11TPA
mRGunUHBcnWEvgJBQl9nJEiU0Zsnvgc/ubhPgXRR4Xq37Z0j4r7g1SgEEzwxA57d
emyPxgcYxn/eR44/KJ4EBs+lVDR3veyJm+kXQ99b21/+jh5Xos1AnX5iItreGCc=
-----END CERTIFICATE-----
)CERT";

namespace board {
constexpr int lcdDc = 2, lcdCs = 10, lcdSck = 6, lcdMosi = 7;
constexpr int i2cSda = 4, i2cScl = 5, touchInt = 0;
constexpr uint8_t ioAddr = 0x43, touchAddr = 0x15;
constexpr uint8_t directionReg = 0x03, outputReg = 0x05, highZReg = 0x07;
}

constexpr uint16_t TFT_BLACK = 0x0000;
constexpr uint16_t TFT_WHITE = 0xFFFF;
constexpr uint16_t TFT_CYAN = 0x07FF;
constexpr uint16_t TFT_DARKCYAN = 0x03EF;
constexpr uint16_t TFT_DARKGREEN = 0x03E0;
constexpr uint16_t TFT_DARKGREY = 0x7BEF;
constexpr uint16_t TFT_MAROON = 0x7800;
constexpr int middle_center = 0;
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

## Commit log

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2026-06-16 Implement deep sleep functionality in main.cpp, including GPIO wakeup configuration and power management for display components.
2026-06-16 Remove battery monitoring code and related configurations from platformio.ini and main.cpp. Update README.md to clarify the absence of onboard battery sensing and provide guidance for potential hardw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
2026-06-16 Update font configurations in lv_conf.h to use Roboto instead of Montserrat for improved UI consistency. Modify ui.cpp to reflect these font changes in button and label styles, ensuring a cohesive de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
2026-06-16 Refactor keypoint management in ui.cpp by removing the manual tracking switch and implementing gesture-based navigation between Keypoints and Run views. Introduce an armed set mechanism for committin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
2026-06-17 Enhance run state management in SharkClient by refining progress reporting and state transitions. Implement a single run action button that dynamically updates based on the current run state (stopped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
2026-06-26 Enhance battery management and UI responsiveness by adding reset reason logging in main.cpp to diagnose power issues. Adjust TX power in shark_client.cpp to moderate levels for improved battery perfo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
    [main.cpp]
2026-06-26 Remove deep sleep functionality from main.cpp and related references in README.md and AGENTS.md. Adjust button handling logic to simplify user interactions by eliminating long press actions. Update d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
2026-06-29 Comment out monitor and upload port configurations in platformio.ini for improved flexibility in device connection settings.
2026-06-30 Add long press functionality for button to power off remote and update README.md
2026-06-30 Add wake button handling logic to prevent premature wake during button press. Update UI elements in the connection screen for improved layout and status display, including new arc indicator and statu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
    [main.cpp]
2026-08-03 Refactor UI layout in connection screen to enhance user experience, including adjustments to status display and arc indicator. Improve button handling logic for better responsiveness during interacti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
2026-08-03 Refactor firmware architecture to evolve the iFootage Shark Nano II remote into a multi-device studio controller. Implement a compile-time configurable driver catalog and device manager, allowing for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
2026-08-03 Enhance desktop UI simulation capabilities by adding a new `ui_sim` environment in platformio.ini for generating 240x240 PNG screenshots without hardware flashing. Update AGENTS.md and README.md to d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
2026-08-03 Update UI to support Home screen with icon tiles for Devices, Groups, Scenes, and Portal. Adjust layout and sizing for improved alignment and responsiveness in shark_ui.cpp and ui.cpp. Enable image s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
2026-08-03 Implement a compact paged rename input feature in the UI, replacing the rectangular keyboard with a round-native 3x3 keypad. Introduce page navigation for character selection (A-I, J-R, S-Z, and numb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
2026-08-03 Consolidate Shark Nano II device code into a per-device structure under `src/devices/shark_nano_ii/`. Update platformio.ini to reflect new source filters and dependencies. Remove legacy `shark_client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
2026-08-03 Add Canon BLE driver support for EOS R6 family. Update platformio.ini to include new environment and build flags. Enhance README.md to reflect the addition of Canon BLE capabilities and update docume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
2026-08-03 Update LVGL memory configuration to support four-device setup. Increase LVGL heap size from 48 KiB to 96 KiB in lv_conf.h and platformio.ini. Enhance simulator to manage multiple devices and document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
2026-08-03 Update architecture and documentation for Canon drivers. Introduce `Canon (Trigger)` and `Canon (Smart)` workflows, detailing their functionalities and requirements. Document the need for a capture o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
2026-08-03 Enhance device management UI with a category-grouped add-device picker. Replace automatic driver creation with a scrollable model selection organized by Motion, Lights, Cameras, and Recorders. Update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
    [main.cpp]
2026-08-03 Update Canon BLE driver documentation and UI. Enhance README.md to reflect the implementation status of the EOS R6 Mark II and Mark III, including verification of pairing and movie record trigger. Mo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
2026-08-03 Enhance documentation and UI for hardware trigger functionality. Update README.md to clarify button actions for device control, including the new hardware trigger behavior for Canon and Shark devices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
    [main.cpp]
2026-08-03 Add Tascam X8 support and update documentation. Introduce Tascam Portacapture X8 driver with record control capabilities, including explicit start/stop commands and state management. Update platformi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
2026-08-04 Refine Tascam X8 connection handling and state management. Enhance the Tascam X8 client to support asynchronous connection and reconnect-state restoration, ensuring accurate recording status after re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
2026-08-04 Update Tascam X8 documentation and verify hardware functionality. Revise README.md to reflect confirmed hardware capabilities, including start/stop, persisted reconnect, and state restoration after r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
2026-08-04 Implement Canon smartphone-mode BLE control and update documentation. Replace the existing BR-E1 trigger implementation with a new experimental branch for smartphone-mode BLE pairing and explicit mov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
    [main.cpp]
2026-08-04 Implement explicit power-off control for Canon BLE integration. Enhance README.md to clarify the new power management features, including the explicit power-off command and its operational constraint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
2026-08-04 Enhance Canon BLE integration with improved power management and connection handling. Update README.md to clarify the new power-on functionality and connection procedures for the EOS R6 Mark II and I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
    [driver.h, main.cpp]
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2026-08-04 Add hardware files for Bleep Remote enclosure including 3MF, STL, and STEP formats. Update README.md with parts list, enclosure details, and assembly instructions.
    [Bleep Remote Bottom.3mf, Bleep Remote Bottom.stl, Bleep Remote Button.3mf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]
2026-08-04 Prevent mixed-sequence BLE allocation failures
    [main.cpp]
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2026-08-06 Fix sequence step settings editing
    [main.cpp]
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2026-08-07 Implement sequence editing and connection recovery flows
    [bleep_watch_crown_0p76mm.step, bleep_watch_crown_0p76mm.stl]
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2026-08-07 Remove obsolete code and generated artifacts
    [bleep_watch_crown_0p76mm.step, bleep_watch_crown_0p76mm.stl]
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2026-08-08 Add local Settings, diagnostics, and factory reset flows
    [main.cpp]
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2026-08-08 Fix Canon setup recovery and mute device status text
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2026-08-09 Add single-line marquee titles across UI screens
    [dis12824d_v1.brd]
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2026-08-09 Fix native test portability and profile memory diagnostics
    [main.cpp]
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2026-08-12 Fix offline Portal configuration and sequence saves
    [main.cpp]
2026-08-12 Fix Canon multi-camera pairing identity
    [driver.h, main.cpp]
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2026-08-12 Improve Aputure light onboarding and reboot recovery
    [main.cpp]
2026-08-12 Resolve per-instance light capabilities and add scene diagnostics
    [driver.h, main.cpp]
2026-08-12 Fix Zhiyun reconnect to resume saved targets
    [driver.h]
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2026-08-15 Prepare version 0.3 release gates
    [dis12824d_v1.brd]
2026-08-15 Fix 0.3 refactor review findings
    - Portal: cancel a pending AP-mode scan when Wi-Fi credentials are
    submitted so the loop's scan-completion branch cannot overwrite the
    join status or leave a stale scan-failed flag
    - ActiveInstancePool: reject kInvalidInstanceId in add/remove so an
    unguarded caller cannot corrupt the capacity accounting
    - DeviceConfiguration::transact: restore the previous registry when the
    mutation itself fails, matching pre-refactor rollback semantics
    Add native tests for the pool guards and the transact rollback. Native
    suite 86/86; full bleep profile built and flashed with hashes verified.
2026-08-15 Skip retry backoff when falling back to passive BLE scan
    - BleCentral::scheduleRetry: when the next retry can only listen for
    advertisements (direct-attempt budget exhausted), resume scanning in
    the same loop pass instead of adding the 1.5 s failure backoff as dead
    time. Direct re-attempts keep their per-failure settling delay and
    explicit post-drop reconnect delays are unchanged
    - Diagnosed from timestamped on-device captures of a cold HML Studio
    sequence open (~15.1 s to Ready): the Tascam AK-BT1's first direct
    attempt died with HCI 574 and the peripheral then stayed silent for
    ~7-9 s; the panel-side 1.5 s pre-scan wait was the only avoidable cost.
    Canon Smart reached proto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
2026-08-15 Implement device onboarding and routing improvements
    [bleep_recovery.csv]
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2026-09-03 Fix Zhiyun shared-mesh repair flow
    [driver.h]
2026-09-04 Fix HML Studio sequence failures and speed up mixed-scene preparation
    Diagnosed the failing HML Studio sequence on the bench panel over the local
    debug console. The camera had dropped this panel's pairing and the saved Home
    Assistant token was invalid; the invalid token then hung the panel.
    - Home Assistant: consume a frame slot before handling it so an auth_invalid
    teardown cannot wrap the frame counter and replay the frame forever; stage
    the Wi-Fi shutdown (DHCP stop, disconnect, settled WIFI_OFF from the driver
    loop); remember the access point channel/BSSID for fast rejoins (shared
    with the updater).
    - Scenes: fail preparation immediately with "Re-pair <device>" when a physical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
    [main.cpp]
2026-09-04 Halve update-check TLS load, read HA state under memory pressure, verify Canon backoff cap
    Boot update checks failed intermittently with mbedtls -0x2700. Heap sampling
    shows Wi-Fi leaves ~96 KB free and each github.com TLS handshake (Sectigo
    P-384 chain) then takes 55-75 KB, so the trough sat between 0.2 KB and 23 KB
    and the handshake occasionally ran out of memory; the trust roots themselves
    verify all three GitHub chains.
    - Add bleep-update.bundle (canonical manifest + base64 signature line) to the
    release packager and verifier; firmware fetches it first so a check costs
    one github.com handshake instead of two, falls back to the .json/.sig pair
    on 404, and remembers (release-tagged,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
    [main.cpp]
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2026-09-04 Reconnect automatically when a just-woken Canon body stalls GATT setup
    An 18-minute-idle reproduction showed the body accepting the link and bonding
    after four wake pokes, then never answering service discovery: getService()
    blocked for the 30 s ATT timeout, returned nothing, and the screen parked on
    CONNECTION FAILED with a manual Retry.
    A saved body whose setup finds no handshake service now disconnects and
    reconnects (1.5 s delay, at most two retries) before the protocol is marked
    failed. The blocking discovery itself is NimBLE's ATT timeout and is noted
    against ADR-021's asynchronous-GATT gate.
2026-09-04 Trim recorder queue wait behind a sleeping camera and retry setup parameters
    Tascam X8 links split three ways in captures: awake and unqueued 2.1 s,
    awake but queued behind the Canon's connect/bonding 5.1-5.7 s, asleep
    10-25 s (first poke fails, the AK-BT1 advertises nothing for 6-13 s, then
    rediscovery plus setup).
    - Canon Smart connect timeout 4000 -> 2500 ms (watchdog 6000 -> 4000): no
    successful establishment exceeded 2.1 s and no wake failure surfaced after
    2.8 s, so a silent camera blocks the queued recorder for 2.5 s not 4 s.
    Measured: recorder ready at 4.3 s instead of 5.1 s behind a sleeping camera.
    - BleCentral retries the post-connect parameter update (400 ms, 1 s, 2 s)
    w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
2026-09-04 Acquire recorders before cameras and scan continuously while a peer wakes
    - Sequence preparation acquires recorders, then lights, then cameras so the
    X8's sub-second connect is not queued behind a sleeping camera's pokes;
    ConnectPolicy::connectPriority orders queued connects the same way.
    Measured: X8 ready at 2.7 s, all targets at 6.3 s.
    - Shared scan skips its 1.5 s pauses for 15 s while a saved peer that just
    failed to establish is sought; sightings showed an AK-BT1 silent for 29 s
    after a failed poke, then one connectable advertisement.
    - Advertisement::connectable from NimBLE; non-connectable adverts never start
    a connect. Generic listen-first policy (directAttemptsBeforeSca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
2026-09-06 Redesign studio marketing site with interactive device and screen tour
    [bottom.stl, button.stl, power-switch.stl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]
2026-09-06 Fit website display to the raised CAD cover
    [display-cover.stl]
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

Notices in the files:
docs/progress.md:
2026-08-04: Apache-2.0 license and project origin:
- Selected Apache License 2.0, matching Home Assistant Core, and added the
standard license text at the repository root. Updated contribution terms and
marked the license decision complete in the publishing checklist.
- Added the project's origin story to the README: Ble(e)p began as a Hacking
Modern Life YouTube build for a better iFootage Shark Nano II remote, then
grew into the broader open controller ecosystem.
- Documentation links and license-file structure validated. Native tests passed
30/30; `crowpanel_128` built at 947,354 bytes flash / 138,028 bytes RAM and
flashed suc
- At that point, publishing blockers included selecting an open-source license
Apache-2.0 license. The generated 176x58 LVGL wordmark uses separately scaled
